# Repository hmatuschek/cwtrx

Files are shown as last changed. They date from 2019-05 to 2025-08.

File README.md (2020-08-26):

# Multiband QRP CW TRX based on the QCX

This repository contains all CAD files for the PCBs, documentation and 
firmware sourcecode for my small [portable multi-band QRP CW transceiver](https://dm3mat.darc.de/cw2019). 

## License
This work is licensed under a [Creative Commons Attribution-ShareAlike 4.0 International License](http://creativecommons.org/licenses/by-sa/4.0/).

[](http://creativecommons.org/licenses/by-sa/4.0/">)

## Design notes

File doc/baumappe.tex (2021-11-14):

\documentclass[10pt, a4paper,twoside]{scrartcl}
\usepackage[ngerman]{babel}
\usepackage{amsmath}
\usepackage{amssymb}
\usepackage{graphicx}
\usepackage{subcaption}
\usepackage{float}
\usepackage[top=2cm,bottom=3cm,outer=2cm,inner=3cm]{geometry}\usepackage[utf8]{inputenc}
\usepackage{hyperref}
\usepackage[multiple]{footmisc}
\usepackage{parskip}
\usepackage{wrapfig}
\usepackage{xfrac}
\usepackage{xcolor}
\usepackage{tikz}
\usetikzlibrary{arrows}
\usetikzlibrary{arrows.meta}
\usepackage{longtable}
\usepackage{pdfpages}
\usepackage[tikz]{bclogo}
\usepackage{eurosym}
\usepackage{listings}

\hypersetup{
    colorlinks=true,
    linkcolor=blue,
    filecolor=magenta,      
    urlcolor=cyan
}

\restylefloat{table}

\newcommand{\warn}[1]{\textbf{#1}}
\newcommand{\con}[1]{\texttt{#1}}
\newcommand{\dis}[1]{\textbf{\texttt{#1}}}

\newenvironment{remember}{\begin{bclogo}[couleur=blue!30,arrondi=.1,logo=\bccrayon,ombre=true]{Merke}}{\end{bclogo}}   
\newenvironment{remark}{\begin{bclogo}[couleur=blue!30,arrondi=.1,logo=\bcinfo,ombre=true]{Hinweis}}{\end{bclogo}}   
\newenvironment{warning}{\begin{bclogo}[couleur=red!30,arrondi=.1,logo=\bcattention,ombre=true]{Warnung}}{\end{bclogo}}   

\title{QRP CW Transceiver Baumappe}
\subtitle{Board Rev. 2, Firmware Rev. 2.0}
\author{Hannes Matuschek -- DM3MAT\\\texttt{<dm3mat [at] darc [dot] de>}\\\texttt{https://dm3mat.darc.de/cw2019}}
\date{\today}

\begin{document}
\maketitle

\begin{abstract}
Diese Baumappe beschreibt den Zusammenbau, Abgleich und die Bedienung der zweiten Revision meines kleinen, portablen CW TRX. Wenn Sie keinen \emph{rev 2} Aufdruck auf den Leiterplatten finden können, ist dies das falsche Dokument!

Der Hauptunterschied zwischen dieser und der ersten Revision ist der Mischer. Anstatt des \texttt{74HC4053}, der eine recht große Dämpfung bei höheren Frequenzen aufweist, verwendet die zweite Revision den \texttt{FST3253}. Dieser Mischer kann problemlos bis ins 10m Band verwendet werden. Außerdem wurde das Platinenlayout vereinfacht. Die Platinen werden nun durch Platinensteckverbinder verbunden, was den Aufbau des TRX deutlich vereinfacht. Auch wanderte der Mikrocontroller auf die Empfängerplatine. Es gibt nun nur noch zwei Platinen mit $10\times 8\,cm$ Abmaßen und nicht mehr drei. Diese passen gerade so in ein Fischer-Gehäuse (\texttt{KOH-2100} + \texttt{KOH-4100} + \texttt{DPL 2-4}).
\end{abstract}
\thispagestyle{empty}
\vfill
\begin{center}
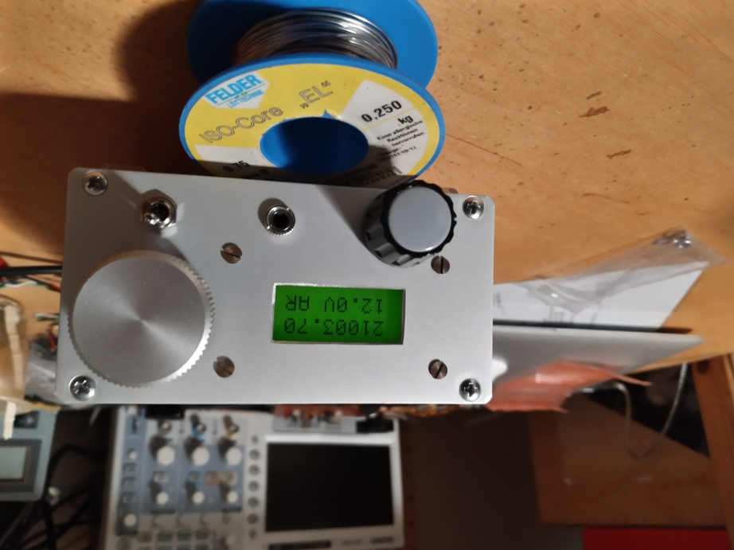
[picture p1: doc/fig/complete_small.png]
 
\end{center}

\cleardoublepage
\tableofcontents
\thispagestyle{empty}

\cleardoublepage
\section{Empfänger- \& Controllerplatine} \label{sec:rx}
 Auf dieser Platine befindet sich der Hauptteil der gesamten TRX-Schaltung. Der Empfänger ist ein Direktüberlagerungsempfänger (Driektmischer), der einen \texttt{FST3253} CMOS-Schalter als so genannter \emph{sample-hold} Mischer verwendet (zusammen mit \texttt{C4-C7}). Dieser Mischer benötigt zwei VFO Signale mit $90^\circ$ Phasendifferenz und produziert vier Mischprodukte mit $0^\circ$, $90^\circ$, $180^\circ$ und $270^\circ$ Phasenverschiebung. Diese zwei Signalpaare ($0^\circ$ + $180^\circ$) und ($90^\circ$ + $270^\circ$) werden dann in zwei unabhängige Differenzverstärker (\texttt{U6A}, \texttt{U6B}) geführt, die zwei um $90^\circ$ phasenverschobene Audiosignale produzieren (für USB, $-90^\circ$ für LSB). Das nachfolgende Phasennetzwert \texttt{U7} \& \texttt{U8} verschiebt dann die Phasenlage der Audiosignale um $-90^\circ$ bei $700\,Hz$. Zuletzt werden die resultierenden Signale mit \texttt{RV3} addiert. Dabei interferieren USB-Signale konstruktiv und LSB-Signal heben sich auf. Diese \emph{Phasenmethode} erlaubt Direktüberlagerungsempfängern eine Unterdrückung eines Seitenbanden. Die weiteren Audiostufen (\texttt{U3} \& \texttt{U5}) filtern und verstärken Audiosignale nahe $700\,Hz$, welche schließlich in die Audio-PA \texttt{U4} geführt werden.
 
 Der Controller- und VFO-Abschnitt der Platine besteht aus einem \texttt{ATMega 328P} Mikrocontroller, der die \texttt{SI5351} PLL steuert. Das \texttt{CLK2} Signal der PLL treibt zwei Flip-Flops \texttt{U9}, welche die Frequenz des \texttt{CLK2} Signals durch vier teilen und dabei zwei um $90^\circ$ phasenverschobene VFO-Signale für den Mischer erzeugen.
  
\subsection{Aufbau des Controllers}
 In einem ersten Schritt wird der Controllerteil der Platine aufgebaut. Löten Sie \texttt{C2}, \texttt{C26}, \texttt{J7} Steckverbinder, \texttt{L3}, \texttt{C38}, \texttt{C40}, \texttt{C41}, \texttt{C42}, \texttt{U10}, \texttt{J10}, \texttt{C14}, \texttt{J3}, \texttt{R3}, \texttt{C46}, \texttt{R4}, \texttt{U11} + Socket, \texttt{LCD1} Steckverbinder, \texttt{R43}, \texttt{R5}, \texttt{RV4}, \texttt{J9} Steckverbinder, \texttt{R41}, \texttt{R40}, \texttt{C39} \& \texttt{U9} ein. 

\begin{remark}
 Durch das kompakte Design sind die Bauteilreferenzen leider teilweise schlecht zu lesen. I habe dafür, mit Hilfe eines sehr netten KiCAD Plugins, eine \href{https://dm3mat.darc.de/cw2019/rx_rev2_ibom.html}{interaktive BOM} für diese Platine exportiert. Damit sollte es recht einfach sein, bestimmte Bauteile auf der Platine zu finden.
\end{remark}

\begin{warning}
Das Metallfähnchen des TO-220 Gehäuses von \texttt{U10} ist üblicherweise direkt mit dem Mittelpin (GND) verbunden. Bitte prüfen Sie das vor dem Einbau. Einige sehr seltene Varianten verbinden dieses Fähnchen mit $+5\,V$, was einen soliden Kurzschluss verursacht.
\end{warning}

Wenn Sie einen der seltenen Varianten von \emph{U10} verwenden, fügen Sie bitte ein Glimmerplätchen zwischen dem TO-220 und der Leiterplatte ein um einen Kurzschluss zu verhindern. Falls nicht, kann darauf verzichtet werden und U10 direkt auf die Platine verschraubt werden.

 \texttt{R43} limitiert den Strom zur LCD-Hintergrundbeleuchtung. Standardmäßig wird hier ein $220\,\Omega$ Widerstand verwendet. Dieser limitiert den Strom auf ungefähr $23\,mA$. Die führt zu eine sehr schwachen Hintergrundbeleuchtung verringert aber den Stromverbrauch von den max. $120\,mA$ (\texttt{R43} kurzgeschlossen). Ich finde persönlich eine schwache Hintergrundbeleuchtung ideal: Während der Nacht reicht auch eine geringe Hintergrundbeleuchtung aus um das Display lesen zu können. Am Tage ist diese Beleuchtung völlig unnötig. Eine sehr helle Hintergrundbeleuchtung ist daher nicht notwendig und würde nur unnötig viel Batteriestrom verbrauchen. Wenn Sie diesen TRX ausschließlich zu Hause verwenden, können Sie \texttt{R43} überbrücken um somit die maximale Helligkeit zu erhalten.
 
\begin{remark} 
 Sie können auch den Widerstand \texttt{R43} mit einem Taster am Frontpanel ersetzen um die Hintergrundbeleuchtung bei bedarf einzuschalten.
\end{remark}

 Als nächsten bauen Sie den Stecker für den Schalter zusammen (oben-rechts auf der Platine mit der Beschriftung \texttt{SW}). Verbinden Sie eine $12\,V$ Spannungsquelle (Strombegrenzt auf nicht mehr als $100\,mA$) mit den Pads oben-rechts auf der Leiterplatte mit der Beschriftung \texttt{+ G}, wobei \texttt{+} $+12\,V$ und \texttt{G} Masse bedeutet.

\begin{remember}
 Die Empfängerplatine selbst besitzt keine Absicherung gegen Verpolung. Seien Sie also vorsichtig, wenn Sie den RX an die Spannungsquelle anschließen.
\end{remember}

 Wenn nichts in Rauch aufgeht, schalten Sie den RX aus und bauen sie die Stecker für den Drehimpulsgeber und das LCD auf.  

 Der Stecker für den Drehimpulsgeber hat die folgenden Anschlüsse (von links nach rechts) \emph{Mitteltaster}, \emph{Encoder B}, \emph{Encoder A} und \emph{Masse}.

 Der LCD-Stecker hat die folgenden Anschlüsse (von links nach rechts): \emph{5V} Pin 2 am LCD, \emph{Kontrast} Pin 3 am LCD, \emph{LED Hintergrundbeleuchtung} Pin 15 am LCD, \emph{GND} Pin 1 am LCD, \emph{RS (register selection)} Pin 4 am LCD, \emph{D4-D7} Pins 11-14 am LCD, \emph{Chip-Enable (EN)} Pin 6 am LCD. Sie müssen auch Pins 5 und 16 direkt am LCD mit Masse (Pin 1, GND) verbinden.
 
 Verbinden Sie nun den Drehimpulsgeber und das LCD mit der Platine und installieren Sie den \texttt{ATMega328} Mikrocontroller. Dann verbinden Sie den RX wieder mit der Spannungsversorgung. Wenn Sie einen vorprogrammierten MCU erhalten haben, sollten Sie nun eine kurze Begrüßung auf dem Display lesen können. Wenn Sie gar nichts oder eine Reihe schwarzer Blöcke auf dem Display sehen, sollten sie zunächst den Kontrast mit \texttt{RV4} einstellen. Wenn Sie weiterhin nichts auf dem Display sehen, überprüfen Sie bitte die Verbindungen zwischen der Platine und dem Display.

\subsection{Die PLL Testen}
 Als nächstes wird die Funktion der \texttt{SI5351} PLL überprüft. Dazu stecken Sie das \texttt{SI5351} breakout-board in den Sockel J9.

\begin{warning}
 Bitte achten Sie darauf, das \texttt{SI5351} beakout-board richtig herum einzusetzen. Es gibt keinen Schutz. Das breakout-board sollte mit dem LCD Steckverbinder überlappen nicht aber \texttt{U9}!
\end{warning}
 
 Schalten Sie nun den RX ein und überprüfen Sie ob ei $3.5\,MHz$ Signal an den Pins 8, 9, 11 und 12 von \texttt{U9} anliegt. Wenn nicht, überprüfen Sie ob ein $14.0\,MHz$ Signal am \texttt{CLK2} Ausgang des \texttt{SI5351} beakout-board anliegt. An dieser Stelle können Sie auch die $90^\circ$ Phasenverschiebung zwischen den Pins 8 und 12 von \texttt{U9} überprüfen.

\begin{remark}
Standardmäßig ist der RX für den Empfang des oben Seitenbandes (USB) ausgelegt. Wenn Sie den LSB Empfang bevorzugen, unterbrechen Sie die Verbindung des Jumpers \texttt{USB} und überbrücken Sie den Jumper \texttt{LSB} neben \texttt{U9}.
\end{remark} 

Wenn alles zu Ihrer Zufriedenheit funktioniert, fahren Sie mit dem Zusammenbau des restlichen Empfängers fort.

\subsection{Aufbau des Empfängers}
Bevor Sie mit dem Zusammenbau des Empfängers fortfahren, entfernen Sie alle Verbindungen zur Platine. Das heißt, entfernen Sie den \texttt{SI5351}, das LCD und den Impulsgeber sowie die Verkabelung zur Spannungsversorgung.

Als erstes sollte der SMD SOIC-16 \texttt{FST3253} Mischer eingelötet werden. 

\begin{warning}
 Seien Sie vorsichtig! Der \texttt{SI5351} sowie der \texttt{FST3253} sind \textbf{sehr} empfindlich gegenüber elektrostatischer Entladung. Tragen Sie ein anti-static Armband und verwenden Sie eine anti-statische Matte. Tragen Sie keine Kleidung aus Wolle oder synthetischen Fasern. Ich habe schon zwei \texttt{FST3253} auf diese Weise zerstört. 
\end{warning}

\paragraph{Falls Sie noch nie SMD Komponenten verbaut haben}
 Es ist überraschend einfach. Verwenden Sie eine kleine Spitze für Ihren Lötkolben, dünnes Lötzinn (z.B., $0.75mm$) und reichlich Flussmittel! Geben Sie eine gute Portion Flussmittel auf die Pads und Verzinnen Sie ein Pad (z.B., Pin 1). Dann nehmen Sie den IC mit einer spitzen Pinzette auf und fixieren Sie ihn ausschließlich an Pin 1 indem Sie das Pad erhitzen und den IC auf die Platine drücken. Überprüfen Sie nun die Ausrichtung des IC mit seinen Pads. Ist alles zu ihrer Zufriedenheit, können Sie die verbleibenden Pins verlöten. Verwenden Sie wenig Lötzinn und lassen Sie das Flussmittel die ganze Arbeit machen! Falls Sie eine Lötbrücke zwischen zwei Pins erhalten, entfernen Sie das überschüssige Lötzinn mit etwas Entlötlitze.

Sobald der Mischer installiert ist, ist die Reihenfolge, in der die  weiteren Bauelemente installiert werden unkritisch. Bauen Sie den restlichen RX auf, lassen Sie aber noch die Platinensteckverbinder sowie die RCA-Buchse (\texttt{TX-OC}) weg. Diese werden erst am Ende montiert.

\begin{remark}
Die Audio-PA (\texttt{LM386}, \texttt{U4}) hat sehr viel Verstärkung. Wenn Sie lediglich Kopfhörer verwenden wollen, können Sie \texttt{R13} und \texttt{C16} weglassen. Sie könne sie später noch hinzufügen.
\end{remark}

Um den Eingangstransformator zu wickeln, schneiden sie drei 15-16 cm lange CuL-Drahtstücke zurecht. Starten Sie die Windungen indem Sie die drei Drähte \textbf{von Hinten} durch den Kern stecken. Halten Sie diese nun fest und machen Sie die nächste Windung indem Sie die Drähte gegen den Uhrzeigersinn \textbf{von vorn} durch den Kern stecken. Fahren Sie nun fort bis sie 8 Findungen gegen den Uhrzeigersinn auf den Kern gebracht haben. Jedes mal, wenn die Drähte durch den Kern gesteckt werden, gilt als eine Windung.

\begin{figure}[ht!]
 \begin{subfigure}[t]{0.49\textwidth}
   \centering
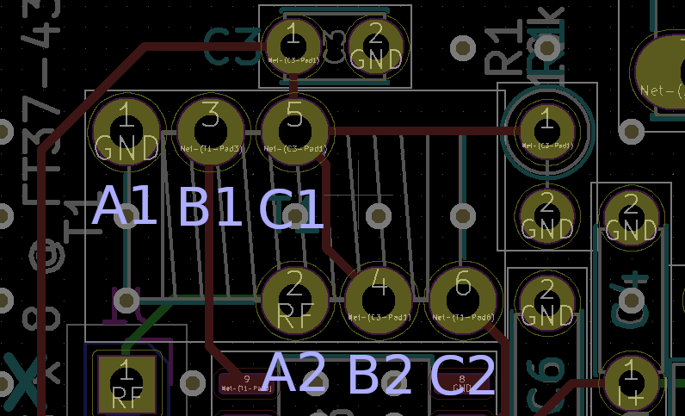
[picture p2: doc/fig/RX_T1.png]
   
   \caption{Footprint von T1}
 \end{subfigure}
 \begin{subfigure}[t]{0.49\textwidth}
   \centering
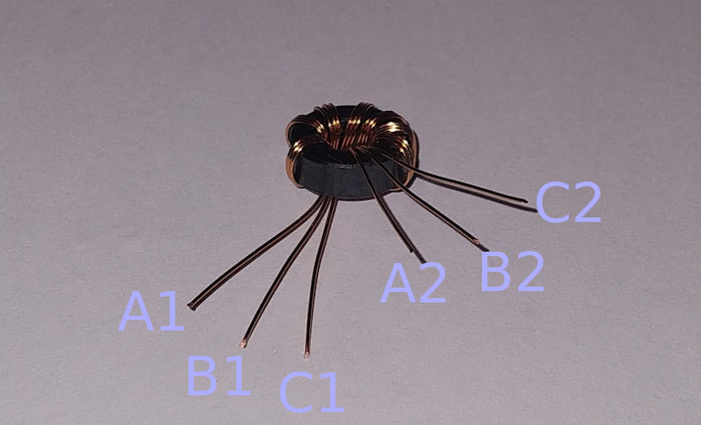
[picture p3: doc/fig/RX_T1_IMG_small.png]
   
   \caption{Gewickelter T1 mit Beschriftung.}
 \end{subfigure}
 \caption{Bevor Sie den Transformator einlöten, überprüfen Sie bitte korrekte Ausrichtung der Anschlüsse. Das Bedeutet das oben-linke wird mit dem unten-linken (d.h., A1 mit A2), oben-mitte mit dem unten-mitte (d.h., B1 mit B2) und das oben-rechte mit dem unten-rechten Pad (d.h., C1 mit C2) verbunden ist.}
\end{figure}

\begin{warning}
Die Audioendstufe neigt leider zum Schwingen, vor allem wenn ein kleiner Lautsprecher verwendet wird. Wenn das passiert, wird der gesamte Audiopfad in die Sättigung getrieben. Dabei kann bis zu 12V an den Mixer geführt werden, was diesen dann zerstört! Um das zu verhindern, \textbf{sollten} vier 5.1V Zenerdioden parallel zu den Kondensatoren C4-C7 fliegend gelötet werden. 
\end{warning}

\subsection{Empfängertest und Abstimmung}
Sobald der Empfänger vollständig aufgebaut ist, verbinden Sie die Spannungsversorgung und bereiten Sie die Stecker für die Lautstärke und den Kopfhörerausgang vor. Verbinden Sie nun auch ein Stück Koaxialkabel mit den \texttt{RX}/\texttt{GN} Pads links-oben auf der Platine. Dies ist der Antenneneingang für den Test. Je nachdem welches Band Sie gewählt haben, sollten Sie die Strombegrenzung der Spannungsversorgung nun auf $120\,mA$ erhöhen.

\subsubsection{Frequenzabstimmung}
Wenn ein genauer Frequenzzähler vorhanden ist, können Sie mit der Feinabstimmung der PLL Frequenz anfangen. Wählen Sie dazu im Menu das 20m Band aus und stellen Sie eine Frequenz von $14.000.70 MHz$ ein. Messen Sie nun die Frequenz am USB Pad. Sie Sollte nun genau $14.0\,MHz$ betragen (falls die Seitentonfrequenz auf $700\,Hz$) eingestellt ist. Sollte die Frequenz abweichen, wählen Sie im \emph{Setup}-Menü den Punkt \emph{PLL correction}. Sie können nun die PLL-Korrektur einstellen bis Sie die gewünschte Frequenz messen.

\subsubsection{CW Filter Abgleich}
Ach wenn die Mittenfrequenz des CW Audiofilter von $\approx 700\,Hz$ nicht geändert werden kann, werden Variationen in den Bauelementwerten zu eine kleinen Verschiebung der Mittenfrequenz des schmalen Filters führen. Für einen guten Abgleich der Send- und Empfangsfrequenzen sollte der CW Seitenton auf genau der Mittenfrequenz des CW Filters liegen. Daher sollte das Spektrum des CW Filters gemessen werden. Zum Beispiel mit der PC Soundkarte und einer Anwendung, die dieses Spektrum darstellt. Die so ermittelte Mittenfrequenz des CW Filters sollte dann unter \texttt{Menu}\ $\rightarrow$\ \texttt{Setup}\ $\rightarrow$\ \texttt{CW Tone} eingestellt werden.

\begin{remember}
Die im Display dargestellte Frequenz ist die Frequenz auf dem der TRX sendet. Nicht die VFO-Frequenz während des Empfangs.
\end{remember}

\subsubsection{Seitenbandunterdrückung}
Wenn Sie über einen Signalgenerator verfügen, stellen Sie ihn auf $14.000 MHz$ ein. Verbinden Sie den Signalgenerator über ein geeignetes Dämpfungsglied mit dem RX. Wählen Sie dann das 20m Band aus und stimmen Sie auf $14.001.3\,MHz$ ab. Sie werden nun einen sehr niedrigen Ton (c.a. $500\,Hz$) hören. Stimmen Sie nun \texttt{RV2} \& \texttt{RV3} ab um die Lautstärke dieses Tons zu minimieren. Dann stimmen Sie den RX auf $14.001.6\,HMz$ ab. Sie sollte nun eine hohen Ton ($900\,Hz$) hören. Stimmen Sie nun \texttt{RV1} \& \texttt{RV3} ab um die Lautstärke dieses Tons zu minimieren. Es könnte notwendig sein, diese Vorgang abwechselnd zu wiederholen bis ein optimales Ergebnis erreicht wird.

Mit diesem Abgleich ist der Abgleich des RX nun vollständig. 

\clearpage
\subsection{RX Bauelemente}  \label{sec:rxcomp}
\begin{longtable}{|l|p{6cm}|l|l|} \hline 
\# & Component & Value & Remarks \\ \hline 
1 & R15 & 10R & \\
4 & R20, R21, R22, R23 & 100R & \\
1 & R43 & 220R & \\
3 & R38, R39, R42 & 1k & \\
1 & R13 & 2.2k & \\
9 & R7, R27, R29-R31, R33, R35-R37 & 3.3k & \\
1 & R32 & 4.3k & \\
1 & R4 & 4.7k & \\
1 & R26 & 5.1k & \\
1 & R34 & 7.5k & \\
10 & R1, R2, R6, R11, R18, R24, R25, R28, R40, R41 & 10k & \\
2 & R9, R10 & 30k & \\
2 & R12, R14 & 33k & \\
2 & R16, R17 & 36k & \\
2 & R3, R5 & 47k & \\
1 & R8 & 120k & \\
1 & R19 & 470k & \\
2 & RV1, RV2 & 50k & \\
1 & RV3 & 500R & \\
1 & RV4 & 10k & \\
3 & C13, C20, C23 & 1n & \\
2 & C25, C27 & 3.3n & \\
3 & C30, C31, C35 & 10n & \\
5 & C12, C17, C18, C21, C33 & 47n & \\
23 & C3, C8, C11, C22, C24, C26, C29, C32, C34, C37-C41, C46-C54 & 100n & \\
5 & C4, C5, C6, C7, C36 & 470n & \\
2 & C1, C28 & 1u & \\
3 & C15, C16, C42 & 10u & \\
3 & C2, C14, C19 & 100u & \\
8 & L1, L3, L4, L5, L6, L7, L8, L9 & 100u & \\
1 & T1 & 3 x 8 @ FT37-43 & \\
1 & D1 & 1N4148 & \\
4 & parallel zu C4-C7 & 5.1V Zener & \\
1 & Q1 & BS170 & \\
1 & Q2 & 2N3904 & \\
1 & U1 & FST3253 & \\
5 & U3, U5, U6, U7, U8 & LM833 & \\
1 & U4 & LM386 & \\ 
6 & -- & DIP-8 Sockets & \\
1 & U9 & 74AC74 & \\
1 & U10 & L7805 & \\
1 & U11 & ATmega328-PU & \\
1 & --  & DIP-28 Socket & \\
1 & - & SI5351 break-out & \\
2 & J1, J3, J4, J11 & 1x10 pin-header long & \\
1 & J6 & 2x3 pin-header & \\
1 & J9 & 1x7 pin-socket & \\
2 & J2, J7 & 1x2 90deg & \\
1 & -- & Switch & \\
1 & J8 & 1x3 90deg & \\
1 & -- & 10k log & potentiometer \\
1 & J10 & 1x4 90deg & \\
1 & -- & Rotary encoder & \\
1 & LCD1 & 1x10 90deg & \\
1 & -- & LCD & 2 x 8 symbols \\
1 & J13 & TX-OC & RCA-jack (optional) \\
1 & J5 & Key & 3.5mm stereo jack\\ \hline
\end{longtable}

\cleardoublepage
\section{PA \& Tiefpassfilter-Platine} \label{sec:pa}
Den Hauptteil der PA/LP-Platine wird von den vier 7-Pol Chebyschev Tiefpassfilter eingenommen. Diese Chebyschevfilter werden benötigt um mit lediglich vier Tiefpassfiltern alle HF-Bänder von 80m bis 10m abzudecken. Der Filter ganz rechts deckt die 80m und 60m Bänder ab und sollte eine Grenzfrequenz von $5.6\,MHz$ haben. Der nächste Filter deckt das 40m und 30m Band ab und sollte eine Grenzfrequenz von $10.5\,MHz$. Der vorletzte Filter deckt das 20m und 17m Band ab und sollte eine Grenzfrequenz von $20\,MHz$ haben. Letztendlich der Filter ganz links deckt das 15m, 12m und 10m Band ab und sollte eine Grenzfrequenz von $30\,Mhz$. Die einzelnen Tiefpassfilter werden mit 4 Subminiaturrelais umgeschaltet die von der RX Platine durch \texttt{J2} gesteuert werden.

Der MOSFET \texttt{Q4} fungiert als RX/TX-Schalter, der das Tiefpass-gefilterte Signal vom Eingang zum RX über \texttt{J6} führt. Der PA-Abschnitt besteht aus einem \texttt{74HCT00} als Treiber und vier \texttt{BS170} MOSFETs als PA Transistoren. Das TX-Oszillator-Signal kommt von der RX/Controller-Platine via \texttt{J7}. Die Stromversorgung des gesamten TRX geschieht durch die Buchse \texttt{J3} und die Stromversorgung des RX erfolgt durch \texttt{J11}.

\begin{remark}
 Bevor Sie die Tiefpassfilter auf die Platine löten, bauen Sie diese zuerst auf einem Stück Leiterplattenmaterial auf und messen Sie diesen durch. Chebyschev Tiefpassfilter sind etwas empfindlich bezüglich der Komponentenwerte.
\end{remark}

 Wenn keine Messgeräte vorhanden sind, ziehen Sie bitte jeweils eine Windung von den gegebenen Werten ab. Die Anzahl der Windungen wurden aus den Al-Werten des Herstellers bestimmte. Meiner Erfahrung nach führt dies zu leicht zu großen Induktivitäten. Außerdem gehen Sie sicher lieber das Risiko einer zu hohen als einer zu niedrigen Grenzfrequenz der Tiefpassfilter ein. 
 
\begin{remark}
 Wie für die Empfängerplatine, gibt es auch für die PA-Platine eine \href{https://dm3mat.darc.de/cw2019/pa_rev2_ibom.html}{interaktive BOM}.
\end{remark}

 Die Diode \texttt{D4} ist parallel in Sperrrichtung zur Spannungsversorgungsbuchse geschaltet. Zusammen mit einer Sicherung im Kabel dient diese Diode dem Verpolschutz. Wenn die Spannungsversorgung falsch herum angeschlossen wird, schließt diese Diode die Spannungsversorgung kurz, was die Sicherung in der Versorgungsleitung durchbrennen lässt. Eine 2A Sicherung \emph{flink} sollte es schon sein. 

 Zuletzt löten Sie die Platinensteckverbindersockel \texttt{J2}, \texttt{J6}, \texttt{J7} ein \texttt{J11}.
´ 
\clearpage
\subsection{PA/Tiefpass Bauelemente}  \label{sec:pacomp}
\begin{longtable}{|l|p{6cm}|l|l|} \hline 
\# & Component & Value & Remarks \\ \hline 
2 & R12, R13 & 100 & \\
1 & R9 & 470R & \\
1 & R10 & 1k & \\
1 & R14 & 4.7k & \\
7 & R1, R3, R5, R7, R11, R15, R16 & 10k & \\
4 & R2, R4, R6, R8 & 100k & \\
2 & C2, C15 & 100p & NP0 \\
4 & C3, C6, C11, C16 & 220p & NP0 \\
4 & C4, C7, C12, C17 & 470p & NP0 \\
2 & C5, C18 & 820p & NP0 \\
2 & C8, C13 & 1n & NP0 \\
2 & C9, C14 & 1.5n & NP0 \\
11 & C1, C10, C19, C20, C22, C23, C24, C27, C28, C29, C30 & 100n & \\
1 & C25 & 1u & \\
1 & C26 & 220u & \\
1 & L14 & 22u & 07HCP \\
1 & L13 & 100u & MICC \\
3 & L1, L5, L9 & 330n & 11T on T37-6 \\
3 & L2, L6, L10 & 480n & 13T on T37-6 \\
3 & L3, L7, L11 & 750n & 14T on T37-2 \\
3 & L4, L8, L12 & 1700n & 21T on T37-2 \\
1 & T1 & -- & 8T + 8T on FT37-43 \\
4 & K1, K2, K3, K4 & G6S-2 & \\
6 & D1, D2, D3, D5, D6, D7 & 1N4148 & \\
1 & D4 & 1N4001 & \\	
4 & Q1, Q2, Q3, Q10 & 2N3904 & \\
6 & Q4, Q6, Q7, Q8, Q9, Q11 & BS170 & \\
1 & Q5 & BD140-16 & \\
1 & U1 & 74HCT00 & \\
1 & J1 & BNC & \\
1 & J2 & 1 x 8 pin-socket & \\
1 & J3 & barrel-jack & \\
3 & J6, J7, J11 & 1 x 2 pin-socket & \\ \hline
\end{longtable}

\cleardoublepage
\section{Endmontage} \label{sec:box}
Schließlich folgt die Endmontage. In diesem schritt werden die Platinensteckverbinder montiert. Wie dies geschieht hängt ein wenig von dem Verwendeten Gehäuse ab. Die Beschreibung die ich hier gebe, betrifft den Fischer-Gehäusebausatz \texttt{KOH-2100} + \texttt{KOH-4100} + \texttt{DPL 2-4}. Dieses ist ein kompaktes $10 \times 10 \times 5\,cm$ Gehäuse. Die Platinen werden mit c.a. $\approx 1.5\,cm$ Abstand in die untere Halbschale geschoben. Leider habe ich keine passenden Stapelleisten für diesen Abstand gefunden und verwende daher welche mit $38\,mm$ Gesamtlänge und daher die viel zu lang sind.

\begin{figure}[!ht]
 \centering
 \begin{subfigure}{0.49\linewidth}
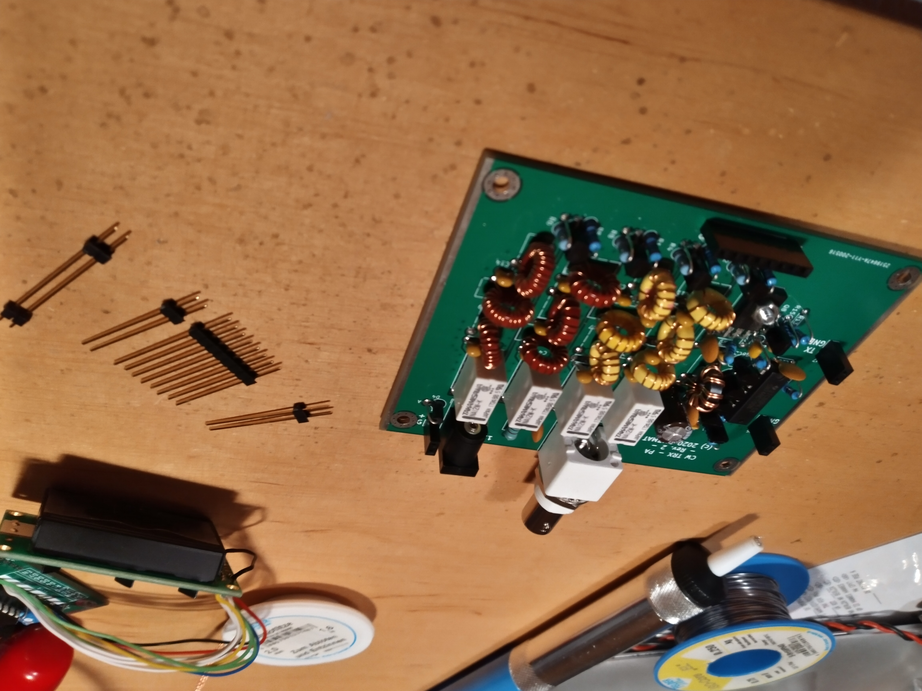
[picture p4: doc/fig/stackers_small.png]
  
  \caption{Schneiden Sie das obere Ende der Stapelleisten ab, bevor Sie sie in die Sockel auf der PA Platine stecken.}  \label{fig:stackers}
 \end{subfigure}
 \begin{subfigure}{0.49\linewidth}
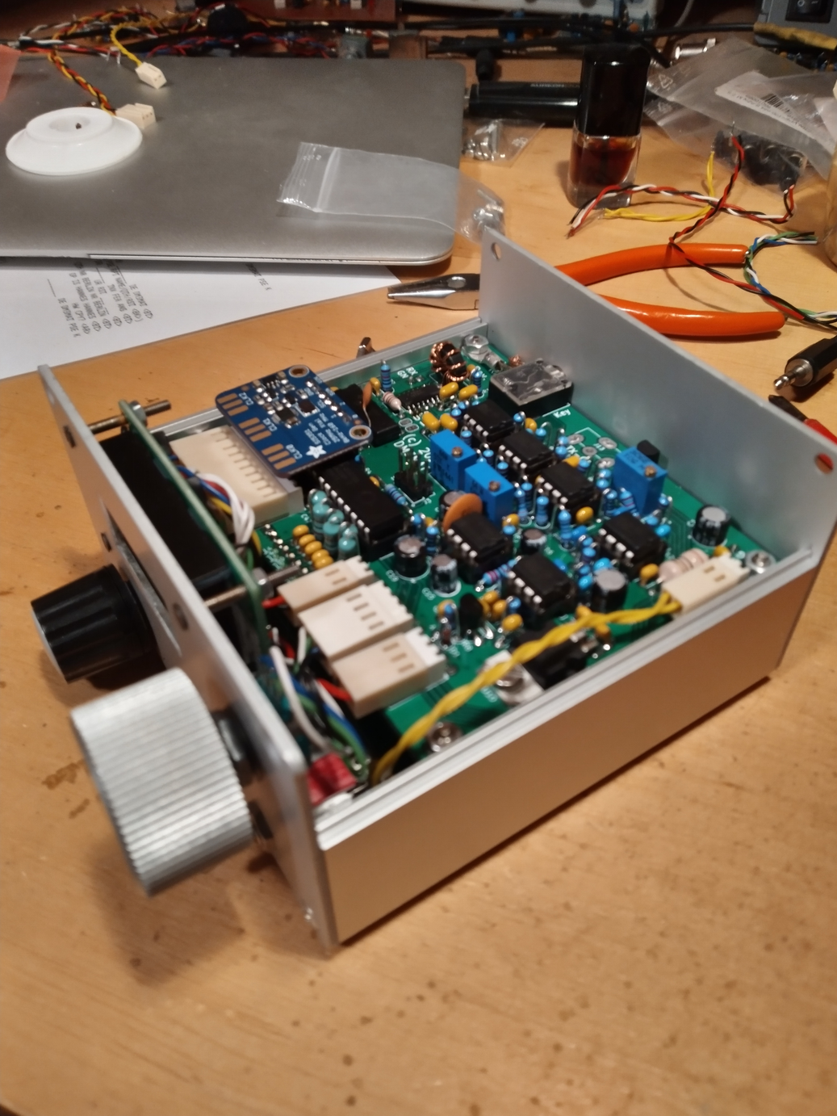
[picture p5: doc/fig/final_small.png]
  
  \caption{Stecken Sie die RX Platine auf die Stapelleisten, schieben Sie das Gebilde in die Gehäuseschale, löten Sie die Stapelleisten an der Empfängerplatine fest und schneiden Sie schließlich die Stapelleisten zu.}  \label{fig:final}
 \end{subfigure}
 \caption{Endmontage der Platinen.}
\end{figure}

Der einfachste Weg ist es die oberen Enden der Stapelleisten abzuschneiden (siehe Abbildung \ref{fig:stackers}) und diese dann in die entsprechenden Sockel der PA Platine zu stecken. Führen Sie dann die langen Enden durch die entsprechenden Löcher der RX Platine und schieben Sie beide in das Gehäuse. Löten Sie nun die Stapelleisten auf der RX Platine fest und kürzen Sie die überstehenden Enden.

Wenn Sie das oben erwähnte Fischergehäuse verwenden, wird die RCA Buchse zur Steuerung einer externen PA nicht mehr passen. Die RX und PA Platinen sind einfach zu dicht beieinander. Wenn Sie ein größeres Gehäuse verwenden, können Sie nun die RCA Buchse installieren.

\subsection{Finaler Test}
Mit der abgeschlossenen Endmontage ist es nun an der Zeit die PA und die Sende-Empfangsumschaltung zu testen. Verbinden Sie alles miteinander und schließen Sie ein Dummyload and den Ausgang an. Messen Sie die HF Spannung über dem Dummyload oder schleifen Sie ein HF-Leistungsmeter zwischen TRX und Dummyload ein. Sie sollte etwa $22\,Vp$ oder ca. $5\,W$ am Ausgang messen. Die Leistung hängt auch von der Betriebsspannung ab. Hier werden $13.8\,V$ angenommen.

Wenn Sie deutlich weniger Messen, messen Sie bitte die Spitzenspannungen am PA-Ausgang und Tiefpassfiltereingang. Überprüfen Sie bitte auch nochmals die Tiefpassfilter. Wenn alles zu Ihrer Zufriedenheit ist, ist der Aufbau abgeschlossen.

\subsection{Hot fixes}
Die zweite Revision war beinahe ein Redesign. Daher ist noch nicht alles Perfekt. Zum Beispiel produziert der \texttt{74AC74} recht hohe Hochfrequenzspannungen auf der $5\,V$ Spannungsversorgung. Um diese stärker zu dämpfen löten Sie bitte einen $470\,pF$ Kondensator direkt von Pin 16 (5V) zu Pin 8 (GND).

Die Audioendstufe neigt leider zum Schwingen, vor allem wenn ein kleiner Lautsprecher verwendet wird. Wenn das passiert, wird der gesamte Audiopfad in die Sättigung getrieben. Dabei kann bis zu 12V an den Mixer geführt werden, was diesen dann zerstört! Um das zu verhindern, \textbf{sollten} vier 5.1V Zenerdioden parallel zu den Kondensatoren C4-C7 auf dem RX-Board fliegend gelötet werden. 

\clearpage
\subsection{Mechanical Parts}
\begin{longtable}{|l|p{6cm}|l|l|} \hline 
\# & Component & Remarks \\ \hline 
1 & chassis top & \\
1 & chassis bottom & \\
1 & chassis front/back & \\
1 & 10k log pot & \\
1 & rotary encoder & \\
1 & LCD display & \\
1 & head-phone socket & \\
1 & switch & \\
1 & barrel plug & \\
2 & fuse holder & optional \\
2 & 2A flink & optional \\
1 & speaker & optional \\ \hline
\end{longtable}

\cleardoublepage 
\section{Die Firmware bauen und laden} \label{sec:fw}
Um die Firmware zu bauen und aufs Gerät zu laden oder auch um die Firmware zu aktualisieren, wird ein sogenannter \emph{in-system programmer} (ISP) benötigt. Dies sind kleine USB-Sticks die die Verbindung vom Computer zum Controller (MCU) herstellen. Es gibt eine Vielzahl an verschiedenen günstigen ISPs (üblicherweise zwischen 5\EUR und 10\EUR auf eBay). Es ist auch möglich einen ISP für die serielle Schnittstelle \href{http://www.lancos.com/siprogsch.html}{selbst zu bauen} oder auch einen \href{https://www.arduino.cc/en/Tutorial/BuiltInExamples/ArduinoISP}{Arduino als ISP} zu verwenden.

Wenn Sie nun einen ISP besitzen, benötigen Sie etwas Software um die Firmware auf die MCU zu schreiben. I verwende \href{https://www.nongnu.org/avrdude/}{avrdude} unter Linux dafür. Andere funktionieren auch. Sie können nun einfach die Firmware sowie das EEPROM Abbild \href{https://github.com/hmatuschek/cwtrx/releases}{herunter laden} und diese auf die MCU spielen. Zuvor müssen Sie aber die sog. \emph{fuses} (Sicherungen) setzen. Setzen Sie die \emph{low-fuses} auf \texttt{0xE2} und die \emph{high-fuses} auf \texttt{0xD9}. Dies konfiguriert the MCU den internen RC-Oszillator als Takt zu verwenden und diesen Takt nicht um den Faktor 8 zu teilen. Alle weiteren Einstellungen bleiben auf den Standardwerten.

\begin{wrapfigure}{l}{0.2\linewidth}
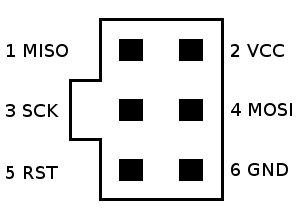
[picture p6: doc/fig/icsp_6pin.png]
  
\end{wrapfigure}
Um nun die Firmware zu laden, muss die MCU mit dem Computer verbunden werden. Dazu wird ein Standard 6-Pin ISP-Steckverbinder verwendet. Der Pin 1 ist durch einen kleinen Kreis auf dem Board markiert. Daraus ergibt sich, dass die kleine \emph{Nase} am Stecker vom Controller weg zeigen muss.

Wenn Sie den Controller programmieren, müssen Sie zunächst die \emph{fuses} setzen. Dieser Schritt muss nur einmal ausgeführt werden, da diese Einstellungen erhalten bleiben auch wenn die Firmware überschrieben wird. Im zweiten Schritt wird die eigentliche Firmware (\texttt{firmware-atmega328p.hex}) auf den Controller geschrieben. Dieser Schritt löscht normalerweise den internen EEPROM. Im EEPROM werden Ihre Einstellungen und die letzte eingestellte Frequenz gespeichert. Die Firmware kann ggf. nicht richtig funktionieren, wenn der EEPROM nicht korrekt initialisiert ist. Daher muss nach der Firmware das EEPROM Abbild (\texttt{firmware-atmega328p-eeprom.hex}) der \emph{Werkseinstellungen} aufgespielt werden.

\subsection{Die Firmware aus den Quellen bauen und laden}
In diesem Absatz will ich kurz das Bauen und Laden der Firmware aus den Quellen unter Ubuntu/Debian (und damit auf einem Raspberry Pi) beschreiben. Bevor Sie starten können, müssen Sie etwas Software nachinstallieren. Den Compiler, die Buildumgebung und die Programmiersoftware. Führen Sie also auf der Kommandozeile aus: 
\begin{lstlisting}[language=bash]
sudo apt-get install git cmake gcc-avr avrdude
\end{lstlisting}

\texttt{git} ist das Versionskontrollsystem. Es wird verwendet um den aktuellen Quellcode herunter zu laden. \texttt{cmake} ist die Buildumgebung. Es gibt eine nette Erweiterung für cmake, die es ermöglicht die Firmware einfach zu bauen und auf die MCU zu laden. \texttt{gcc-avr} ist der Compiler für die AVR MCUs. \texttt{avrdude} ist das Programmiersoftware um die Firmware letztlich auf die MCU zu schreiben.

Sobald Sie die Software installiert haben, können Sie die Quellen von meiner github Seite laden mit
\begin{lstlisting}[language=bash]
git clone https://github.com/hmatuschek/cwtrx.git
\end{lstlisting}

Sie werden nun ein neues Verzeichnis mit dem Namen \texttt{cwtrx} finden. Bevor Sie die Firmware auf die MCU schreiben können, müssen Sie ggf. einige Einstellungen vornehmen. In den ersten Zeilen der Datei \texttt{cwtrx/\-firmware/\-CMakeLists.txt} wird der ISP festgelegt, den Sie verwenden wollen und wie die Software diesen finden kann.

Standardmäßig sollte dort so etwas stehen:
\lstinputlisting[linerange={1-4}, numbers=left]{../firmware/CMakeLists.txt}
In der zweiten Zeile wird die Programmiersoftware festgelegt. Ich verwende hier avrdude. Die dritte Zeile legt den ISP fest. Ich verwende einen STK500V2 kompatiblen ISP (eigentlich heißt der DIAMEX-AVR). Letztendlich wird in Zeile 4 die Gerätedatei festgelegt, unter der der ISP gefunden werden kann. Dieser ISP stellt eine serielle Schnittstelle dar. Daher ist er bei mir unter der Datei \texttt{/dev/ttyACM0} zu finden. Gegebenenfalls müssen Sie die Zeilen 3 und 4 an Ihren ISP anpassen.

Wenn alles aufgesetzt ist, können sie die Firmware bauen. Betreten Sie das Verzeichnis \texttt{cwtrx}, erzeugen Sie ein sog. \emph{build}-Verzeichnis und betreten Sie dieses auch.
\begin{lstlisting}[language=bash]
cd cwtrx
mkdir build
cd build
\end{lstlisting}

Im nächsten Schritt wird der build konfiguriert:
\begin{lstlisting}[language=bash]
cmake ..
\end{lstlisting}
Dieser Schritt sucht nach dem Compiler und bereitet alles vor. Sobald dieser Schritt abgeschlossen ist kann die Firmware und das EEPROM Abbild erstellt werden.
\begin{lstlisting}[language=bash]
make
\end{lstlisting}

Danach müssen die \emph{fuses} gesetzt werden.
\begin{lstlisting}[language=bash]
make set_fuses
\end{lstlisting}
Dieser Schritt kann bei brandneuen MCUs auch fehlschlagen. Versuchen Sie es einfach nochmal. Sobald die \emph{fuses} gesetzt sind, sollte die Kommunikation mit der MCU stabil sein.

Laden Sie danach die Firmware auf die MCU mit
\begin{lstlisting}[language=bash]
make upload_firmware
\end{lstlisting}
und letztendlich das EEPROM Abbild mit
\begin{lstlisting}[language=bash]
make upload_eeprom
\end{lstlisting}

Ihr TRX ist nun betriebsbereit.

\subsection{Firmware aktualisieren}
Unter der Annahme, dass Sie die Schritte oben bereits ausgeführt haben, können Sie die Firmware recht einfach aktualisieren. Betreten Sie dazu das Verzeichnis \texttt{cwtrx} und führen sie die folgenden Schritte aus.
\begin{lstlisting}[language=bash]
git pull
cd build
make 
make upload_firmware
make upload_eeprom
\end{lstlisting}
Ihr TRX sollte nun über die aktuellste Firmware verfügen.

\cleardoublepage
\section{Bedienung} \label{sec:user}
Einen komplexen TRX mit einem Drehimpulsgeber zu bedienen ist recht schwierig. Ich habe daher ein zwei-ebenen Menu entworfen, dass alles Wichtige in die erste Ebene (blau in Abb. \ref{fig:menu}) und alles weniger Wichtige in die Zweite ebene (rot in Abb. \ref{fig:menu}) verbannt. Das erlaubt eine schnelle Handhabung für häufig verwendete Menüpunkte.

\begin{figure}[!ht]
 \centering
 \footnotesize
 \begin{tikzpicture}[node distance=2.3cm,
	>={Latex[width=2mm,length=2mm]},
    menu/.style = {rectangle, rounded corners, draw=black,
                   minimum width=1.5cm, minimum height=1cm,
                   text centered, font=\sffamily, fill=blue!30},
    submenu/.style = {menu, fill=red!30}]
  \node (rit) [menu] {RIT};   
  \node (speed) [menu, right of=rit] {CW Speed}; 
  \node (step) [menu, right of=speed]{Step size};
  \node (vfo) [menu, right of=step] {VFO};
  \node (band) [menu, right of=vfo] {Band};
  \node (setup) [menu, right of=band] {Setup};
  
  \node (quick) [submenu, below of=setup] {Qick-set};
  \node (cw) [submenu, left of=quick] {CW Mode}; 
  \node (tone) [submenu, left of=cw] {CW Tone}; 
  \node (level) [submenu, left of=tone] {CW Level}; 
  \node (text) [submenu, left of=level] {CW Text}; 
  \node (clr) [submenu, left of=text] {Clr. CWT};
  \node (meter) [submenu, below of=clr] {Meter};
  \node (hold) [submenu, below of=meter] {TX Hold}; 
  \node (greet) [submenu, right of=hold] {Greet};
  \node (enc) [submenu, right of=greet] {Enc.Type};
  \node (version) [submenu, right of=enc] {Version};
  \node (sideband) [submenu, right of=version] {USB/LSB};
  \node (pll) [submenu, right of=sideband] {PLL Cor.};
  \node (reset) [submenu, above of=pll] {Reset};

  \path[->,thick]
    (rit) edge (speed)
    (speed) edge (step)
	(step) edge (vfo)
	(vfo) edge (band)
	(band) edge (setup)
	(setup) edge[bend right] (rit);
	
  \path[->,thick,dashed]
    (setup) edge (quick);
  \path[->,thick]
        (quick) edge (cw)
    	(cw) edge (tone)
    	(tone) edge (level) 
    	(level) edge (text)
    	(text) edge (clr)
    	(clr) edge (meter) 
    	(meter) edge (hold)
    	(hold) edge (greet) 
    	(greet) edge (enc)
    	(enc) edge (version)
    	(version) edge (sideband)
    	(sideband) edge (pll)
    	(pll) edge (reset) 
    	(reset) edge (quick);
 \end{tikzpicture}
 \caption{Menu navigation} \label{fig:menu}
\end{figure}

Um in das Menu zu gelangen, drücken Sie einfach kurz auf den Achsentaster des Impulsgebers. Sie werden dann auf der RIT Einstellung oder der zuletzt verwendeten Einstellung landen. Drehen Sie nun den Impulsgeber um in der ersten Ebene des Menüs zu navigieren. Um eine Einstellung zu ändern, drücken Sie nochmals kurz auf den Achsentaster. Sie können nun die ausgewählte Einstellung ändern. Um die Änderung zu speichern und das Menü zu verlassen, drücken Sie nochmals kurz auf den Achsentaster.

Um die zweite Menüebene zu erreichen, drücken Sie zunächst kurz auf den Achsentaster um in die erste Ebene zu gelangen. Wählen Sie dann den Menüpunkt \texttt{Setup} aus und drücken Sie nochmals kurz den Achsentaster. Sie befinden sich nun in der zweiten Menüebene. Das Navigieren, Bearbeiten und Verlassen der zweiten Ebene erfolgt genauso wie in der ersten Menüebene.

\subsection{Gesten}
Die Firmware unterscheidet zwischen 4 verschiedenen \emph{Gesten} den Sie mit dem Drehimpulsgeber ausführen können:
\begin{enumerate}
 \item \emph{drehen} - Einfach den Impulsgeber drehen.
 \item \emph{klick} - Kurzes drücken und wieder loslassen des Achsentasters.
 \item \emph{gedrückt halten} - Langes (mind. $2\,s$) gedrückt halten des Achsentasters.
 \item \emph{drücken \& drehen} - Halten die den Achsentaster gedrückt und drehen Sie gleichzeitig den Impulsgeber.
\end{enumerate}

Während des Empfangs wird durch die \emph{drehen} Geste die Frequenz eingestellt (natürlich), eine \emph{klick} Geste wird das Menü öffnen, die \emph{gedrückt halten} Geste wird den gespeicherten Text senden (falls konfiguriert) und die \emph{drücken \& drehen} Geste wird die sogenannte \emph{quick-set} Einstellung ändern (falls konfiguriert).

\subsection{Einstellungen}
Als \emph{Einstellungen} wird alles Bezeichnet, was während des Betriebs geändert werden kann. Diese Einstellungen sind daher auch alle in der ersten Menüebene zu finden. 
 
\paragraph{Receive/Transmit offset (RIT)}
Erlaubt es die Empfangsfrequenz relativ zur Sendefrequenz zu verstimmen. Eine von null verschiedene RIT wird durch ein \texttt{+} oder \texttt{-} Symbol in der rechten unteren Ecke angezeigt.

\paragraph{CW speed}
Die Gebegeschwindigkeit in WPM.

\paragraph{Tuning step-size}
Die Abstimmschrittweite.

\paragraph{VFO}
Der aktuelle VFO. Entweder \texttt{VFO A}, \texttt{VFO B} oder \texttt{Split}.

\paragraph{Band}
Das aktuelle Band.

\subsection{Setup}
Im \emph{Setup} werden alle Einstellungen versteckt, die üblicherweise nicht während des Betriebs geändert werden. Sie sind daher in die zweite Menüebene verband.

\paragraph{Quick-set}
Das \emph{quick-set} Feature erlaubt es Ihnen eine bestimmte Einstellung (siehe oben) während des Empfangs zu ändern ohne dazu erst das Menü aufrufen zu müssen. Hier können Sie diese Einstellung auswählen: RIT, Gebegeschwindigkeit, Schrittweite, Band oder eben \texttt{none}. Letzteres deaktiviert \emph{quick-set}.

\paragraph{Keyer mode}
Stellt die Art der Taste ein. Entweder \emph{straight key} oder \emph{iambic}.

\paragraph{CW side-tone level}
Stellt die Lautstärke des CW Seitentons ein. Dies ist ein Wert zwischen 1 und 255.

\paragraph{Keyer memory \texttt{CW Text}}
Legt den Text fest, der gesendet wird, wenn der Achsentaster lange gedrückt wird. Wenn kein Text gespeichert ist wird nichts passieren.

Um den Text zu editieren drücken sie nun kurz den Achsentaster. Sie sollten nun einen Kursor unter dem ersten Zeichen des Textes sehen. Wenn Sie nun am Impulsgeber drehen, können Sie das Zeichen auswählen, das sie editieren wollen. Drücken sie nochmals kurz den Achsentaster um das ausgewählte Zeichen zu ändern. Das gewählte Zeichen sollte nun blinken. Wenn die das Zeichen geändert haben drücken Sie nochmals kurz auf den Achsentaster. Der Kursor sollte nun eine Stelle weiter gesprungen sein. Fahren Sie nun so fort bis der gewünschte Text erstellt ist (z.B. ein CQ Ruf). Um den Text zu speichern und das Menu zu verlassen, drücken und halten Sie den Achsentaster für mindestens 2 Sekunden.

\paragraph{Clear keyer memory}
Dieser Menüpunkt löscht den gespeicherten Text.

\paragraph{Meter selection}
Wählt die Anzeige während des Empfangs aus. Dies kann \texttt{Volt}, \texttt{Temp} oder \texttt{None} sein. Wenn Sie \texttt{Volt} wählen wird die Versorgungsspannung kontinuierlich gemessen und angezeigt. Wenn Sie \texttt{Temp} wählen wird die Kerntemperatur der MCU gemessen und angezeigt. Wenn Sie \texttt{None} gewählt haben, wird nichts angezeigt.

\paragraph{TX-hold time}
Legt die Länge der Umschaltpause im $ms$ fest. Standardmäßig ist sie auf $50\,ms$ festgelegt. Dieser kleine Wert erlaubt quasi-QSK. 
\begin{remark}
Wenn Sie eine externe PA verwenden oder im Split Modus operieren, sollten Sie eine längere Umschaltpause wählen um den Relais genügend Zeit um Umschalten zu gewähren.
\end{remark}

\paragraph{Greet text}
Dieser Editor erlaubt es den Begrüßungstext beim booten zu ändern. Dieser Editor funktioniert genau so wie der CW-Texteditor.

\paragraph{CW Seitenton}
Stellt die Frequenz des CW Seitentons ein. Diese Frequenz legt auch den Shift zwischen der Sende und Empfangsfrequenz fest und sollte daher der Mittenfrequenz des CW Audiofilters ($\approx 700\,Hz$) entsprechen.

\paragraph{Encoder type}
Legt den Typ des Drehimpulsgebers fest. Es gibt zwei verbreitete Typen \texttt{A} \& \texttt{B}. Wenn Sie genau den Encoder aus der BOM bestellt haben, haben Sie Typ A. Wenn Sie Probleme mit dem Encoder haben (Doppelschritte), sollten Sie hier Typ B einstellen.

\paragraph{PLL correction}
Diese Einstellung legt die PLL Frequenzkorrektur in PPM fest.

\paragraph{Factory reset}
Vorherige Versionen hatten einige Probleme mit korrumpierten EEPROM Speicher. Dieser Menüpunkt erlaubt es Ihnen den EEPROM auf den Auslieferungszustand zurückzusetzen.

\cleardoublepage
\section{Bill-of-Material (BOM)}
\input{bom.tex}

\subsection{Ein paar \euro\ sparen}
Der teuerste Einzelposten auf der BOM ist das Gehäuse. Sie können sicher ein Alugehäuse für unter \EUR{5} bei ebay finden. Sie finden auch billige Clone der SI5351 break-out Platine für um die \EUR{3}, billige Drehimpulsgeber und 2x8 LCD Displays dort. So können Sie die BOM Kosten noch deutlich senken.

\cleardoublepage
\includepdf[pages={1,2,4,3,5,6},landscape=true, addtotoc={
 1, section, 1, RX Schaltung, rxscm,
 2, subsection, 1, RX Mischer, rxmix,
 4, subsection, 1, Demodulator, rxdemod,
 3, subsection, 1, NF-Sektion, rxaudio,
 5, subsection, 1, PLL, rxpll,
 6, subsection, 1, Controller, rxctrl}]{fig/rx_scm.pdf}
\includepdf[pages={1,2,3},landscape=true, addtotoc={
 1, section, 1, RX Board, rxbrdtop,
 2, subsection, 1, Unterseite, rxbrdbottom,
 3, subsection, 1, Siebdruck, rxbrdsilk}]{fig/rx_brd.pdf}
\includepdf[landscape=true, addtotoc={
 1, subsection, 1, Bauteil Werte \& Lage, rxval}]{fig/rx_values.pdf}
\includepdf[landscape=true, addtotoc={
 1, section, 1, PA/LP Schaltung, pascm}]{fig/pa_scm.pdf}
\includepdf[pages={1,2,3},landscape=true, addtotoc={
 1, section, 1, PA/LP Board, pabrdtop,
 2, subsection, 1, Unterseite, pabrdbottom,
 3, subsection, 1, Siebdruck, pabrdsilk}]{fig/pa_brd.pdf}
\includepdf[landscape=true, addtotoc={
 1, subsection, 1, Bauteil Werte \& Lage, pacomp}]{fig/pa_values.pdf}
\includepdf[landscape=true, addtotoc={
 1, section, 1, Bohrplan, drillfront}]{fig/drill_front.pdf}
\includepdf[landscape=true]{fig/drill_back.pdf}
\end{document}

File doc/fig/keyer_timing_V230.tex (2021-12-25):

\documentclass{standalone}
\usepackage{pgfplots}
\usetikzlibrary{patterns}
\pgfplotsset{width=12cm, height=8cm, compat=1.9}
\pgfplotsset{compat=newest} 

\begin{document}
\begin{tikzpicture}
 \begin{axis}[
   axis lines = left,
   xlabel={$t$ in \emph{dits}},
   ytick={1.5,3.5,5.5,7.5},
   yticklabels={{iambic A}, {iambic B}, {left}, {right}}
  ]
  \fill[pattern=north west lines, opacity=0.2] (2.5,0) rectangle (5,9);
  \fill[pattern=north east lines, opacity=0.5] (4.5,0) rectangle (5,9);
  \fill[pattern=north west lines, opacity=0.2] (5.25,0) rectangle (7,9);
  \fill[pattern=north east lines, opacity=0.5] (6.5,0) rectangle (7,9);
  \fill[pattern=north west lines, opacity=0.2] (8.5,0) rectangle (11,9);
  \fill[pattern=north east lines, opacity=0.5] (10.5,0) rectangle (11,9);
  \fill[pattern=north west lines, opacity=0.2] (11.25,0) rectangle (13,9);
  \fill[pattern=north east lines, opacity=0.5] (12.5,0) rectangle (13,9);
  \addplot [mark=none, blue] coordinates {(0,1) (1,1) (1,2) (4,2) (4,1) (5,1) (5,2) (6,2) (6,1) (7,1) (7,2) (10,2) (10,1) (14,1)};
  \addplot [mark=none, red] coordinates {(0,3) (1,3) (1,4) (4,4) (4,3) (5,3) (5,4) (6,4) (6,3) (7,3) (7,4) (10,4) (10,3) (11,3) (11,4) (12,4) (12,3) (14,3)};
  \addplot [mark=none, black] coordinates {(0,5) (1.5,5) (1.5,6) (9.5,6) (9.5,5) (14,5)};
  \addplot [mark=none, black] coordinates {(0,7) (1,7) (1,8) (9.7,8) (9.7,7) (14,7)};
  \addplot +[mark=none, dashed, black] coordinates {(5,0) (5,9)};
  \addplot +[mark=none, dashed, black] coordinates {(7,0) (7,9)};
  \addplot +[mark=none, dashed, blue] coordinates {(11,0) (11,9)};
  \addplot +[mark=none, dashed, red] coordinates {(13,0) (13,9)};
 \end{axis}
\end{tikzpicture}
\end{document}

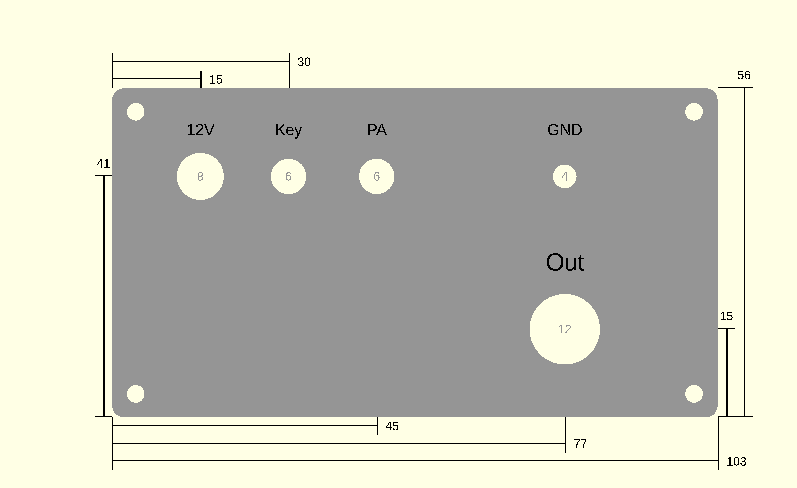
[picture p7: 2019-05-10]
doc/fig/BackPanel.png

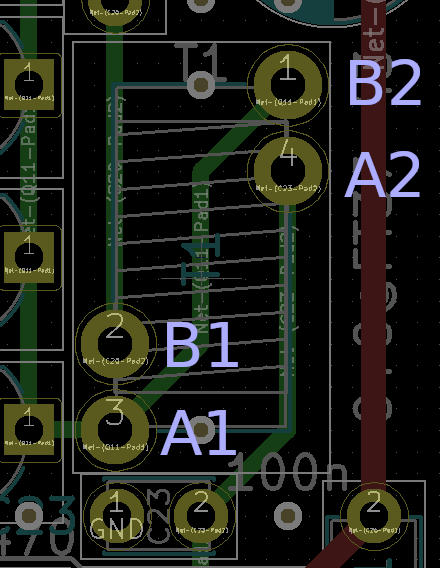
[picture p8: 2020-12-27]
doc/fig/PA_T1.png

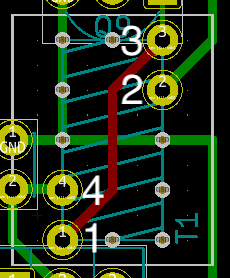
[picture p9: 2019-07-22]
doc/fig/T1.png

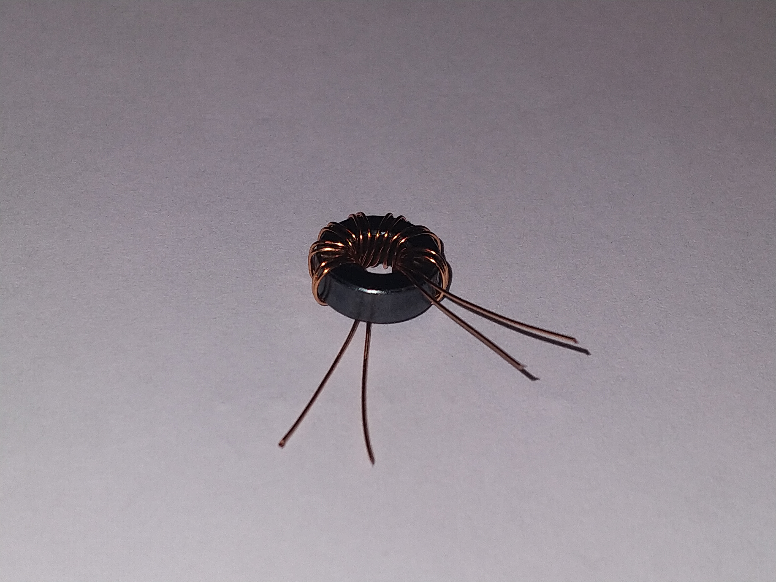
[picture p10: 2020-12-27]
doc/fig/PA_T1_IMG.jpg

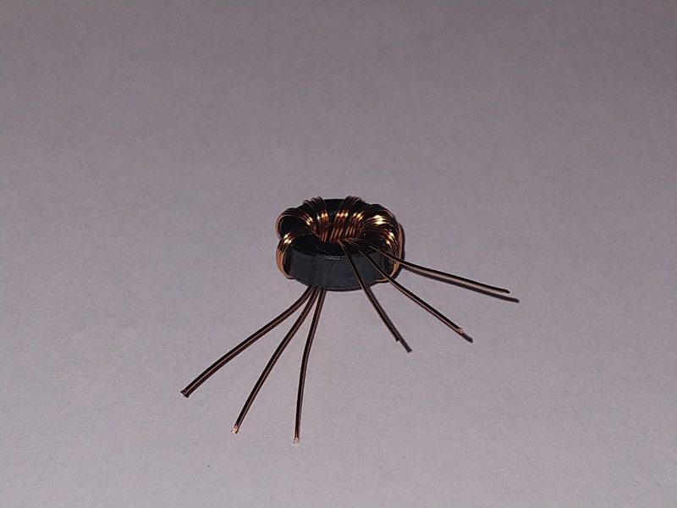
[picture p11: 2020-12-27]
doc/fig/RX_T1_IMG_small.jpg

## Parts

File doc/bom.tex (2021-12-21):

\begin{longtable}{|p{0.02\textwidth}|p{0.02\textwidth}|p{0.3\textwidth}|p{0.3\textwidth}|p{0.07\textwidth}|p{0.07\textwidth}|}\hline
\# & & Value & Reichelt & Cost & Sum \\ \hline\hline
1 & $\square$ & 10R & METALL 10,0 & 0,05 \euro & 0,05 \euro \\
6 & $\square$ & 100R & METALL 100 & 0,05 \euro & 0,29 \euro \\
1 & $\square$ & 220R & METALL 220 & 0,05 \euro & 0,05 \euro \\ 
1 & $\square$ & 470R & METALL 470 & 0,05 \euro & 0,05 \euro \\
4 & $\square$ & 1k & METALL 1,00K & 0,05 \euro & 0,20 \euro \\
1 & $\square$ & 2.2k & METALL 2,20K & 0,05 \euro & 0,05 \euro \\
9 & $\square$ & 3.3k & METALL 3,30K & 0,05 \euro & 0,44 \euro \\
1 & $\square$ & 4.3k & METALL 4,30K & 0,05 \euro & 0,05 \euro \\
2 & $\square$ & 4.7k & METALL 4,70K & 0,05 \euro & 0,10 \euro \\
1 & $\square$ & 5.1k & METALL 5,10K & 0,05 \euro & 0,05 \euro \\
1 & $\square$ & 7.5k & METALL 7,50K & 0,05 \euro & 0,05 \euro \\
17 & $\square$ & 10k & METALL 10,0K & 0,05 \euro & 0,83 \euro \\
2 & $\square$ & 30k & METALL 30,0K & 0,05 \euro & 0,10 \euro \\
2 & $\square$ & 33k & METALL 33,0K & 0,05 \euro & 0,10 \euro \\
2 & $\square$ & 36k & METALL 36,0K & 0,05 \euro & 0,10 \euro \\
2 & $\square$ & 47k & METALL 47,0K & 0,05 \euro & 0,10 \euro \\
4 & $\square$ & 100k & METALL 100K & 0,05 \euro & 0,20 \euro \\
1 & $\square$ & 120k & METALL 120K & 0,05 \euro & 0,05 \euro \\
1 & $\square$ & 470k & METALL 470K & 0,05 \euro & 0,05 \euro \\
2 & $\square$ & 50k & 64W-50K & 0,31 \euro & 0,62 \euro \\
1 & $\square$ & 500R & 64W-500 & 0,27 \euro & 0,27 \euro \\
1 & $\square$ & 10k & ACP 6-L 10K & 0,21 \euro & 0,21 \euro \\ \hline
2 & $\square$ & 100p & NPO-2,5 100P & 0,07 \euro & 0,14 \euro \\
4 & $\square$ & 220p & NPO-2,5 220P & 0,08 \euro & 0,32 \euro \\
4 & $\square$ & 470p & NPO-2,5 470P & 0,09 \euro & 0,36 \euro \\
2 & $\square$ & 820p & Conrad: 1578706 & 0,16 \euro & 0,32 \euro \\
3 & $\square$ & 1n & X7R-2,5 1,0N & 0,07 \euro & 0,21 \euro \\
2 & $\square$ & 1n & NPO-2,5 1,0N & 0,09 \euro & 0,18 \euro \\
2 & $\square$ & 1.5n & X7R-2,5 1,5N & 0,07 \euro & 0,14 \euro \\
2 & $\square$ & 3.3n & X7R-2,5 3,3N & 0,07 \euro & 0,14 \euro \\
3 & $\square$ & 10n & X7R-2,5 10N & 0,07 \euro & 0,21 \euro \\
5 & $\square$ & 47n & X7R-2,5 47N & 0,11 \euro & 0,55 \euro \\
35 & $\square$ & 100n & Z5U-2,5 100N & 0,05 \euro & 1,75 \euro \\
5 & $\square$ & 470n & Z5U-5 470N & 0,19 \euro & 0,95 \euro \\
3 & $\square$ & 1u & Z5U-5 1,0µ & 0,26 \euro & 0,78 \euro \\ \hline		
3 & $\square$ & 10u & RAD 10/35 & 0,02 \euro & 0,06 \euro \\
3 & $\square$ & 100u & RAD 100/16 & 0,03 \euro & 0,09 \euro \\
1 & $\square$ & 220u & RND 150ECR AY & 0,06 \euro & 0,06 \euro \\ \hline
1 & $\square$ & 22u & L-07HCP 22µ & 0,38 \euro & 0,38 \euro \\
9 & $\square$ & 100u & L-MICC 100µ & 0,27 \euro & 2,43 \euro \\ \hline
2 & $\square$ & FT37-43 & FT 37-43 & 0,58 \euro & 1,16 \euro \\
6 & $\square$ & T 37-6 & T 37-6 & 0,78 \euro & 4,68 \euro \\
6 & $\square$ & T 37-2 & T 37-2 & 0,54 \euro & 3,24 \euro \\ \hline
7 & $\square$ & 1N4148 & 1N 4148 & 0,02 \euro & 0,14 \euro \\
1 & $\square$ & 1N4001 & 1N 4001 & 0,02 \euro & 0,02 \euro \\
4 & $\square$ & 5.1V Zener & RND 1N751A &0,02 \euro & 0,08 \euro \\
7 & $\square$ & BS170 & BS 170 & 0,10 \euro & 0,70 \euro \\
5 & $\square$ & 2N3904 & 2N 3904 & 0,04 \euro & 0,20 \euro \\
1 & $\square$ & 2SB772 & SB 772 & 0,24 \euro & 0,24 \euro \\
1 & $\square$ & FST3253 & SOIC-16, Ebay & 2,00 \euro & 2,00 \euro \\
5 & $\square$ & LM833 & LM 833 & 0,90 \euro & 4,50 \euro \\
1 & $\square$ & LM386 & LM 386 DIP & 0,22 \euro & 0,22 \euro \\
6 & $\square$ & DIP-8 socket (optional) & GS 8 & 0,04 \euro & 0,24 \euro \\
1 & $\square$ & 74AC74 & Kessler: 522421 & 0,36 \euro & 0,36 \euro \\
1 & $\square$ & 74HCT00 & 74HCT 00 & 0,33 \euro & 0,33 \euro \\
1 & $\square$ & L7805 & L 7805 CV & 0,25 \euro & 0,25 \euro \\
1 & $\square$ & ATmega328-PU & ATMEGA 328P-PU & 2,50 \euro & 2,50 \euro \\
1 & $\square$ & DIP-28 socket (optional) & GS 28-S & 0,10 \euro & 0,10 \euro \\
1 & $\square$ & SI5351 breakout & Adafruit & 7,35 \euro & 7,35 \euro \\ \hline
4 & $\square$ & G6S-2 & NA 12W K & 0,96 \euro & 3,84 \euro \\ \hline
2 & $\square$ & 1x10 pin-header long & STAPELLEISTE 10 & 0,38 \euro & 0,76 \euro \\
1 & $\square$ & 2x3 pin-header & MPE 087-2-006 & 0,14 \euro & 0,14 \euro \\
1 & $\square$ & 1x7 pin-socket & MPE 156-1-007 & 0,37 \euro & 0,27 \euro \\
2 & $\square$ & 1x2 90deg & PSS 254/2W & 0,02 \euro & 0,04 \euro \\
2 & $\square$ & 1x2 plug & PSK 254/2W & 0,02 \euro & 0,04 \euro \\
1 & $\square$ & 1x3 90deg & PSS 254/3W & 0,04 \euro & 0,04 \euro \\
1 & $\square$ & 1x3 plug & PSK 254/3W & 0,02 \euro & 0,02 \euro \\
1 & $\square$ & 1x4 90deg & PSS 254/4W & 0,09 \euro & 0,09 \euro \\
1 & $\square$ & 1x4 plug & PSK 254/4W & 0,02 \euro & 0,02 \euro \\
1 & $\square$ & 1x10 90deg & PSS 254/10W & 0,10 \euro & 0,10 \euro \\
1 & $\square$ & 1x10 plug & PSK 254/10W & 0,08 \euro & 0,08 \euro \\
2 & $\square$ & contacts & PSK-KONTAKTE & 0,29 \euro & 0,58 \euro \\
2 & $\square$ & head-phone socket & EBS 35 & 0,30 \euro & 0,60 \euro\\
1 & $\square$ & TX-OC & CBP & 0,21 \euro & 0,21 \euro \\
1 & $\square$ & BNC & UG 1094W1 & 0,99 \euro & 0,99 \euro \\
1 & $\square$ & 1 x 8 socket & MPE 094-1-008 & 0,24 \euro & 0,14 \euro \\
1 & $\square$ & barrel jack & DC BU21 90 & 0,46 \euro & 0,46 \euro \\
3 & $\square$ & 1 x 2 socket & RND 205-00642 & 0,02 \euro & 0,06 \euro \\ \hline
1 & $\square$ & chassis top & KOH-2100 & 5,40 \euro & 5,40 \euro \\
1 & $\square$ & chassis bottom & KOH-4100 & 5,80 \euro & 5,80 \euro \\
1 & $\square$ & chassis front/back & DPL 2-4 & 7,99 \euro & 7,99 \euro \\
1 & $\square$ & 10k log pot & RK11K112-LOG10K & 1,35 \euro & 1,35 \euro \\
1 & $\square$ & rotary encoder & STEC11B03 & 3,70 \euro & 3,70 \euro \\
1 & $\square$ & LCD display & LCD-PM 2X8-5 A & 7,30 \euro & 7,30 \euro \\
1 & $\square$ & switch & KIPP 1A11 & 1,20 \euro & 1,20 \euro \\
1 & $\square$ & barrel plug & HS 21-13 & 0,20 \euro & 0,20 \euro \\
2 & $\square$ & fuse holder (optional) & RND 170-00170 & 0,19 \euro & 0,38 \euro \\
2 & $\square$ & 2A flink (optional) & ESKA 520.020 & 0,09 \euro & 0,18 \euro \\
1 & $\square$ & speaker (optional) & LSM-S20K & 2,70 \euro & 2,70 \euro \\ \hline \hline
\multicolumn{4}{|l}{Total\footnote{Prices may change over time.}} & \multicolumn{2}{r|}{\textbf{89,26 \euro}} \\ \hline
\end{longtable}

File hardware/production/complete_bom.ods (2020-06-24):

Qty | Value | Reichelt | Preis | Summe
1 | 10R | METALL 10,0 | 0,05 € | 0,05 €
6 | 100R | METALL 100 | 0,05 € | 0,29 €
1 | 220R | METALL 220 | 0,05 € | 0,05 €
1 | 470R | METALL 470 | 0,05 € | 0,05 €
4 | 1k | METALL 1,00K | 0,05 € | 0,20 €
1 | 2.2k | METALL 2,20K | 0,05 € | 0,05 €
9 | 3.3k | METALL 3,30K | 0,05 € | 0,44 €
1 | 4.3k | METALL 4,30K | 0,05 € | 0,05 €
2 | 4.7k | METALL 4,70K | 0,05 € | 0,10 €
1 | 5.1k | METALL 5,10K | 0,05 € | 0,05 €
1 | 7.5k | METALL 7,50K | 0,05 € | 0,05 €
17 | 10k | METALL 10,0K | 0,05 € | 0,83 €
2 | 30k | METALL 30,0K | 0,05 € | 0,10 €
2 | 33k | METALL 33,0K | 0,05 € | 0,10 €
2 | 36k | METALL 36,0K | 0,05 € | 0,10 €
2 | 47k | METALL 47,0K | 0,05 € | 0,10 €
4 | 100k | METALL 100K | 0,05 € | 0,20 €
1 | 120k | METALL 120K | 0,05 € | 0,05 €
1 | 470k | METALL 470K | 0,05 € | 0,05 €
2 | 50k | 64W-50K | 0,31 € | 0,62 €
1 | 500R | 64W-500 | 0,27 € | 0,27 €
1 | 10k | ACP 6-L 10K | 0,21 € | 0,21 €
2 | 100p | NPO-2,5 100P | 0,07 € | 0,14 €
4 | 220p | NPO-2,5 220P | 0,08 € | 0,32 €
4 | 470p | NPO-2,5 470P | 0,09 € | 0,36 €
2 | 820p | C: 1578706 | 0,16 € | 0,32 €
3 | 1n | X7R-2,5 1,0N | 0,07 € | 0,21 €
2 | 1n | NPO-2,5 1,0N | 0,09 € | 0,18 €
2 | 1.5n | X7R-2,5 1,5N | 0,07 € | 0,14 €
2 | 3.3n | X7R-2,5 3,3N | 0,07 € | 0,14 €
3 | 10n | X7R-2,5 10N | 0,07 € | 0,21 €
5 | 47n | X7R-2,5 47N | 0,11 € | 0,55 €
35 | 100n | Z5U-2,5 100N | 0,05 € | 1,75 €
5 | 470n | Z5U-5 470N | 0,19 € | 0,95 €
3 | 1u | Z5U-5 1,0µ | 0,26 € | 0,78 €
3 | 10u | RAD 10/35 | 0,02 € | 0,06 €
3 | 100u | RAD 100/16 | 0,03 € | 0,09 €
1 | 220u | RND 150ECR AY | 0,06 € | 0,06 €
1 | 22u | L-07HCP 22µ | 0,38 € | 0,38 €
7 | 100u | L-MICC 100µ | 0,27 € | 1,89 €
2 | FT37-43 | FT 37-43 | 0,58 € | 1,16 €
6 | T 37-6 | T 37-6 | 0,78 € | 4,68 €
6 | T 37-2 | T 37-2 | 0,54 € | 3,24 €
7 | 1N4148 | 1N 4148 | 0,02 € | 0,14 €
1 | 1N4001 | 1N 4001 | 0,02 € | 0,02 €
7 | BS170 | BS 170 | 0,10 € | 0,70 €
5 | 2N3904 | 2N 3904 | 0,04 € | 0,20 €
1 | BD140 | BD 140-16 STM | 0,19 € | 0,19 €
1 | FST3253 | Ebay | 2,00 € | 2,00 €
5 | LM833 | LM 833 | 0,90 € | 4,50 €
1 | LM386 | LM 386 DIP | 0,22 € | 0,22 €
6 | DIP-8 socket | GS 8 | 0,04 € | 0,24 €
1 | 74AC74 | Kessler: 522421 | 0,36 € | 0,36 €
1 | 74HCT00 | 74HCT 00 | 0,33 € | 0,33 €
1 | L7805 | L 7805 CV | 0,25 € | 0,25 €
1 | ATmega328-PU | ATMEGA 328P-PU | 2,50 € | 2,50 €
1 | DIP-28 socket | GS 28-S | 0,10 € | 0,10 €
1 | SI5351Breakout | Adafruit | 7,35 € | 7,35 €
4 | G6S-2 | NA 12W K | 0,96 € | 3,84 €
2 | 1x10 pin-header long | STAPELLEISTE 10 | 0,38 € | 0,76 €
1 | 2x3 pin-header | RND 205-00634 | 0,03 € | 0,03 €
1 | 1x7 pin-socket | RND 205-00647 | 0,10 € | 0,10 €
2 | 1x2 90deg | PSS 254/2W | 0,02 € | 0,04 €
2 | 1x2 plug | PSK 254/2W | 0,02 € | 0,04 €
1 | 1x3 90deg | PSS 254/3W | 0,04 € | 0,04 €
1 | 1x3 plug | PSK 254/3W | 0,02 € | 0,02 €
1 | 1x4 90deg | PSS 254/4W | 0,09 € | 0,09 €
1 | 1x4 plug | PSK 254/4W | 0,02 € | 0,02 €
1 | 1x8 90deg | PSS 254/8W | 0,10 € | 0,10 €
1 | 1x8 plug | PSK 254/8W | 0,08 € | 0,08 €
2 | contacts | PSK-KONTAKTE | 0,29 € | 0,58 €
1 | TX-OC | RND 205-00698 | 0,57 € | 0,57 €
1 | Key | EBS 35 | 0,30 € | 0,30 €
1 | BNC | UG 1094W1 | 0,99 € | 0,99 €
1 | 1 x 8 Socket | RND 205-00648 | 0,10 € | 0,10 €
1 | Barrel Jack | CLIFF FCR681465P | 0,77 € | 0,77 €
3 | 1 x 2 Socket | RND 205-00642 | 0,02 € | 0,06 €
1 | chassis top | KOH-2100 | 5,40 € | 5,40 €
1 | chassis bottom | KOH-4100 | 5,80 € | 5,80 €
1 | chassis front/back | DPL 2-4 | 7,99 € | 7,99 €
1 | 10k log pot | RK11K112-LOG10K | 1,35 € | 1,35 €
1 | rotary encoder | STEC11B03 | 3,70 € | 3,70 €
1 | LCD display | LCD-PM 2X8-5 A | 7,30 € | 7,30 €
1 | Head-phone socket | EBS 35 | 0,30 € | 0,30 €
1 | Switch | KIPP 1A11 | 1,20 € | 1,20 €
1 | barrel plug | HS 21-13 | 0,20 € | 0,20 €
2 | fuse holder (optional) | RND 170-00170 | 0,19 € | 0,38 €
2 | 2A flink (optional) | ESKA 520.020 | 0,09 € | 0,18 €
1 | speaker (optional) | LSM-S20K | 2,70 € | 2,70 €
 |  | Summe |  | 85,73 €

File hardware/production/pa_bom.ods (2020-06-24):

Qty | Reference(s) | Value | Reichelt | Price | Cost
2 | R12, R13 | 100R | METALL 100 | 0,05 € | 0,10 €
1 | R9 | 470R | METALL 470 | 0,05 € | 0,05 €
1 | R10 | 1k | METALL 1,00K | 0,05 € | 0,05 €
1 | R14 | 4.7k | METALL 4,70K | 0,05 € | 0,05 €
7 | R1, R3, R5, R7, R11, R15, R16 | 10k | METALL 10,0K | 0,05 € | 0,34 €
4 | R2, R4, R6, R8 | 100k | METALL 100K | 0,05 € | 0,20 €
 |  |  |  |  | 0,00 €
2 | C2, C15 | 100p | NPO-2,5 100P | 0,07 € | 0,14 €
4 | C3, C6, C11, C16 | 220p | NPO-2,5 220P | 0,08 € | 0,32 €
4 | C4, C7, C12, C17 | 470p | NPO-2,5 470P | 0,09 € | 0,36 €
2 | C5, C18 | 820p | C: 1578706 | 0,16 € | 0,32 €
2 | C8, C13 | 1n | NPO-2,5 1,0N | 0,09 € | 0,18 €
2 | C9, C14 | 1.5n | X7R-2,5 1,5N | 0,07 € | 0,14 €
12 | C1, C10, C19, C20, C22, C23, C24, C27, C28, C29, C30 | 100n | Z5U-2,5 100N | 0,03 € | 0,36 €
1 | C25 | 1u | Z5U-5 1,0µ | 0,26 € | 0,26 €
 |  |  |  |  | 0,00 €
1 | C26 | 220u | RND 150ECR AY | 0,06 € | 0,06 €
 |  |  |  |  | 0,00 €
1 | L14 | 22u | L-07HCP 22µ | 0,38 € | 0,38 €
1 | L13 | 100u | L-MICC 100µ | 0,27 € | 0,27 €
3 | L1, L5, L9 | 330n, 11T | T 37-6 | 0,78 € | 2,34 €
3 | L2, L6, L10 | 480n, 13T | T 37-6 | 0,78 € | 2,34 €
3 | L3, L7, L11 | 750n, 14T | T 37-2 | 0,54 € | 1,62 €
3 | L4, L8, L12 | 1700n, 21T | T 37-2 | 0,54 € | 1,62 €
1 | T1 | 8+8 @ FT37-43 | FT 37-43 | 0,58 € | 0,58 €
 |  |  |  |  | 0,00 €
4 | K1, K2, K3, K4 | G6S-2 | NA 12W K | 0,96 € | 3,84 €
 |  |  |  |  | 0,00 €
4 | D1, D2, D3, D5 | 1n4148 | 1N 4148 | 0,02 € | 0,08 €
1 | D4 | 1N4001 | 1N 4001 | 0,02 € | 0,02 €
 |  |  |  |  | 0,00 €
4 | Q1, Q2, Q3, Q10 | 2N3904 | 2N 3904 | 0,04 € | 0,16 €
6 | Q4, Q6, Q7, Q8, Q9, Q11 | BS170 | BS 170 | 0,10 € | 0,60 €
1 | Q5 | BD140 | BD 140-16 STM | 0,19 € | 0,19 €
 |  |  |  |  | 0,00 €
1 | U1 | 74HCT00 | 74HCT 00 | 0,33 € | 0,33 €
 |  |  |  |  | 0,00 €
1 | J1 | BNC | UG 1094W1 | 0,99 € | 0,99 €
1 | J2 | 1 x 8 Socket | RND 205-00648 | 0,10 € | 0,10 €
1 | J3 | Barrel Jack + Switch | CLIFF FCR681465P | 0,77 € | 0,77 €
3 | J6, J7, J11 | 1 x 2 Socket | RND 205-00642 | 0,02 € | 0,06 €
 |  |  | Summe |  | 19,21 €

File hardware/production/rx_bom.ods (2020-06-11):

Qty | Reference(s) | Value | Reichelt | Preis | Summe
1 | R15 | 10R | METALL 10,0 | 0,05 € | 0,05 €
4 | R20, R21, R22, R23 | 100R | METALL 100 | 0,05 € | 0,20 €
1 | R43 | 220R | METALL 220 | 0,05 € | 0,05 €
3 | R38, R39, R42 | 1k | METALL 1,00K | 0,05 € | 0,15 €
1 | R13 | 2.2k | METALL 2,20K | 0,05 € | 0,05 €
9 | R7, R27, R29, R30, R31, R33, R35, R36, R37 | 3.3k | METALL 3,30K | 0,05 € | 0,44 €
1 | R32 | 4.3k | METALL 4,30K | 0,05 € | 0,05 €
1 | R4 | 4.7k | METALL 4,70K | 0,05 € | 0,05 €
1 | R26 | 5.1k | METALL 5,10K | 0,05 € | 0,05 €
1 | R34 | 7.5k | METALL 7,50K | 0,05 € | 0,05 €
10 | R1, R2, R6, R11, R18, R24, R25, R28, R40, R41 | 10k | METALL 10,0K | 0,05 € | 0,49 €
2 | R9, R10 | 30k | METALL 30,0K | 0,05 € | 0,10 €
2 | R12, R14 | 33k | METALL 33,0K | 0,05 € | 0,10 €
2 | R16, R17 | 36k | METALL 36,0K | 0,05 € | 0,10 €
2 | R3, R5 | 47k | METALL 47,0K | 0,05 € | 0,10 €
1 | R8 | 120k | METALL 120K | 0,05 € | 0,05 €
1 | R19 | 470k | METALL 470K | 0,05 € | 0,05 €
2 | RV1, RV2 | 50k | 64W-50K | 0,31 € | 0,62 €
1 | RV3 | 500R | 64W-500 | 0,27 € | 0,27 €
1 | RV4 | 10k | ACP 6-L 10K | 0,21 € | 0,21 €
3 | C13, C20, C23 | 1n | X7R-2,5 1,0N | 0,07 € | 0,21 €
2 | C25, C27 | 3.3n | X7R-2,5 3,3N | 0,07 € | 0,14 €
3 | C30, C31, C35 | 10n | X7R-2,5 10N | 0,07 € | 0,21 €
5 | C12, C17, C18, C21, C33 | 47n | X7R-2,5 47N | 0,11 € | 0,55 €
23 | C3, C8, C11, C22, C24, C26, C29, C32, C34, C37, C38, C39, C40, C41, C46, C47, C48, C49, C50, C51, C52, C53, C54 | 100n | Z5U-2,5 100N | 0,05 € | 1,15 €
5 | C4, C5, C6, C7, C36 | 470n | Z5U-5 470N | 0,19 € | 0,95 €
2 | C1, C28 | 1u | Z5U-5 1,0µ | 0,26 € | 0,52 €
3 | C15, C16, C42 | 10u | RAD 10/35 | 0,02 € | 0,06 €
3 | C2, C14, C19 | 100u | RAD 100/16 | 0,03 € | 0,09 €
6 | L1, L3, L4, L5, L6, L7, L8, L9 | 100u | L-MICC 100µ | 0,27 € | 1,62 €
1 | T1 | 3 x 8 @ FT37-43 | FT 37-43 | 0,58 € | 0,58 €
1 | D1 | 1N4148 | 1N 4148 | 0,02 € | 0,02 €
1 | Q1 | BS170 | BS 170 | 0,10 € | 0,10 €
1 | Q2 | 2N3904 | 2N 3904 | 0,04 € | 0,04 €
1 | U1 | FST3253 | Ebay | 2,00 € | 2,00 €
5 | U3, U5, U6, U7, U8 | LM833 | LM 833 | 0,90 € | 4,50 €
1 | U4 | LM386 | LM 386 DIP | 0,22 € | 0,22 €
1 | U9 | 74AC74 | Ebay | 1,00 € | 1,00 €
1 | U10 | L7805 | L 7805 CV | 0,25 € | 0,25 €
1 | U11 | ATmega328-PU | ATMEGA 328P-PU | 2,50 € | 2,50 €
1 | - | SI5351Breakout | Adafruit | 7,35 € | 7,35 €
2 | J1, J3, J4, J11 | 1x10 pin-header long | STAPELLEISTE 10 | 0,38 € | 0,76 €
1 | J6 | 2x3 pin-header | RND 205-00634 | 0,03 € | 0,03 €
1 | J9 | 1x7 pin-socket | RND 205-00647 | 0,10 € | 0,10 €
2 | J2, J7 | 1x2 90deg | PSS 254/2W | 0,02 € | 0,04 €
2 | -- | 1x2 plug | PSK 254/2W | 0,02 € | 0,04 €
1 | J8 | 1x3 90deg | PSS 254/3W | 0,04 € | 0,04 €
1 | -- | 1x3 plug | PSK 254/3W | 0,02 € | 0,02 €
1 | J10 | 1x4 90deg | PSS 254/4W | 0,09 € | 0,09 €
1 | -- | 1x4 plug | PSK 254/4W | 0,02 € | 0,02 €
1 | LCD1 | 1x8 90deg | PSS 254/8W | 0,10 € | 0,10 €
1 | -- | 1x8 plug | PSK 254/8W | 0,08 € | 0,08 €
1 | -- | contacts | PSK-KONTAKTE | 0,29 € | 0,29 €
1 | J13 | TX-OC | RND 205-00698 | 0,57 € | 0,57 €
1 | J5 | Key | EBS 35 | 0,30 € | 0,30 €
 |  |  |  | Summe: | 29,748

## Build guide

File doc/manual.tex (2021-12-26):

\documentclass[10pt, a4paper,twoside]{scrartcl}
\usepackage{amsmath}
\usepackage{amssymb}
\usepackage{graphicx}
\usepackage{subcaption}
\usepackage{float}
\usepackage[top=2cm,bottom=3cm,outer=2cm,inner=3cm]{geometry}\usepackage[utf8]{inputenc}
\usepackage{hyperref}
\usepackage[multiple]{footmisc}
\usepackage{parskip}
\usepackage{wrapfig}
\usepackage{xfrac}
\usepackage{xcolor}
\usepackage{tikz}
\usetikzlibrary{arrows,automata}
\usetikzlibrary{arrows.meta}
\usepackage{longtable}
\usepackage{pdfpages}
\usepackage[tikz]{bclogo}
\usepackage{eurosym}
\usepackage{listings}

\hypersetup{
    colorlinks=true,
    linkcolor=blue,
    filecolor=magenta,      
    urlcolor=cyan
}

\restylefloat{table}

\newcommand{\warn}[1]{\textbf{#1}}
\newcommand{\con}[1]{\texttt{#1}}
\newcommand{\dis}[1]{\textbf{\texttt{#1}}}

\newenvironment{remember}{\begin{bclogo}[couleur=blue!30,arrondi=.1,logo=\bccrayon,ombre=true]{Remember}}{\end{bclogo}}   
\newenvironment{remark}{\begin{bclogo}[couleur=blue!30,arrondi=.1,logo=\bcinfo,ombre=true]{Remark}}{\end{bclogo}}   
\newenvironment{warning}{\begin{bclogo}[couleur=red!30,arrondi=.1,logo=\bcattention,ombre=true]{Warning}}{\end{bclogo}}   

\title{QRP CW Transceiver Manual}
\subtitle{Board rev. 2, Firmware rev. 2.5}
\author{Hannes Matuschek -- DM3MAT\\\texttt{<dm3mat [at] darc [dot] de>}\\\texttt{https://dm3mat.darc.de/cw2019}}
\date{\today}

\begin{document}
\maketitle

\begin{abstract}
This document describes the assembly, alignment and usage of the second revision of my small, portable CW TRX. If you cannot find any \emph{rev 2} markings on your boards, this is the wrong document!

The main difference to the first revision is the mixer. Instead of a \texttt{74HC4053}, which has some significant damping on higher frequencies, the second revision relies on the famous \texttt{FST3253} switch. This allows for using the TRX well into the 10m band. Additionally, the board layout has been changed to allow for board-to-board interconnects and proper connectors to ease the assembly of the final TRX. To this end there are only two boards (instead of three) with a $10\times 8\,cm$ footprint that can be squeezed into a $10 \times 10\times 5\,cm$ Fischer-chassis (\texttt{KOH-2100} + \texttt{KOH-4100} + \texttt{DPL 2-4}).  Using this chassis, the receiver will weight about $580\,g$ (without batteries \& key).
\end{abstract}
\thispagestyle{empty}
\vfill
\begin{center}
 
\end{center}

\cleardoublepage
\tableofcontents
\thispagestyle{empty}

\cleardoublepage
\section{Receiver \& Controller Board} \label{sec:rx}
 The receiver and controller board houses the majority of the TRX circuitry. The receiver is a direct conversion receiver using the \texttt{FST3253} CMOS switch as a sample-hold mixer (in conjunction with \texttt{C4-C7}). The latter takes two VFO input signals with $90^\circ$ phase difference and produces four mixing products with $0^\circ$, $90^\circ$, $180^\circ$ and $270^\circ$ phase shifts. These signal pairs ($0^\circ$ + $180^\circ$) and ($90^\circ$ + $270^\circ$) are fed into two independent difference-amplifiers (\texttt{U6A}, \texttt{U6B}) producing two $90^\circ$ phase-shifted audio signals (for USB, $-90^\circ$ for LSB). The following phase-shift-network \texttt{U7} \& \texttt{U8} then shifts back the audio phase by $-90^\circ$ at $700\,Hz$. Finally the resulting signals are added at \texttt{RV3}. Here the USB signals will interfere constructively while the LSB signals will cancel out. This phasing method allows for an unwanted side-band suppression in a direct conversion receiver. The next stages (\texttt{U3} \& \texttt{U5}) will filter and amplify audio signals near $700\,Hz$, which are then fed into the audio PA \texttt{U4}. 
 
 The controller and VFO section of the board consists of a \texttt{ATMega 328P} MCU controlling the \texttt{SI5351} PLL oscillator. The \texttt{CLK2} signal of the PLL drives the two flip-flops \texttt{U9}, which divide the \texttt{CLK2} frequency by four and produce a proper $90^\circ$ phase-shifted signal for the mixer.
 
\subsection{Controller Assembly}
 In a first step, the controller section of the receiver board is assembled. Install \texttt{C2}, \texttt{C26}, \texttt{J7} connector, \texttt{L3}, \texttt{C38}, \texttt{C40}, \texttt{C41}, \texttt{C42}, \texttt{U10}, \texttt{J10}, \texttt{C14}, \texttt{J3}, \texttt{R3}, \texttt{C46}, \texttt{R4}, \texttt{U11} + Socket, \texttt{LCD1} connector, \texttt{R43}, \texttt{R5}, \texttt{RV4}, \texttt{J9} connector, \texttt{R41}, \texttt{R40}, \texttt{C39} \& \texttt{U9} first. 

\begin{remark}
 Due to the compact layout of the PCB, the component references might be hard to read. I therefore used a very nice plugin for KiCad to export an \href{https://dm3mat.darc.de/cw2019/rx_rev2_ibom.html}{interactive BOM} for this board. This certainly helps to find the spots where all components are placed, even if the silk-screen is hard to read.
\end{remark}

\begin{warning}
The metal tab of the TO-220 package of \texttt{U10} is usually connected directly to the center pin (GND). Please check beforehand if this is the case for your variant. Some rare packages connect this pad to \emph{+5V} leading to a nice \& solid short-circuit that will blow either \texttt{U10} or \texttt{L3} or both.
\end{warning}

If you got one of the rare TO-220 variant of U10 that connects the metal tab to +5V, use a mica-insulator between \texttt{U10} and the PCB. If you have enough head-room, you could also install \texttt{U10} vertically, heat-sinking to the PCB is not necessary.

 \texttt{R43} limits the current to the LCD back-light. By default a $220\,\Omega$ resistor is installed. This limits the current to about $23\,mA$. This results in a very dim back-light but reduces the current consumption from max. $120\, mA$ (\texttt{R43} shorted). I personally consider this dim setting the most useful: During daylight a back light makes no sense, as the LCD is perfectly readable. During night without any external light-sources, a very dim back light is still sufficient to read the LCD. There is simply no need to drain the battery for unused or too-bright back lights. If you use the TRX only at home and current consumption is not an issue, you may choose a smaller value for \texttt{R43} or even bridge it for maximum brightness.
 
\begin{remark} 
 You may also replace the resistor \texttt{R43} with a push-button at the front panel to switch the back-light on when needed.
\end{remark}
 
 Then, assemble the switch plug and (top right corner labeled \emph{SW}). Connect a $12\,V$ power-supply (ideally current-limited to not more than $100\,mA$) to the pads of the supply connector (also top-right corner) labeled \emph{+ G}, where the \emph{+} pad is $+12\,V$ and the \emph{G} pad is ground. 

\begin{remember}
 The receiver board itself has no reverse-polarity protection. So be careful when connecting the RX board to the power-supply!
\end{remember}
  
 If nothing blows up, switch the TRX off and continue assembling the rotary-encoder and LCD plugs. 
 
 The rotary encoder plug has the following connections (read left-to-right): \emph{Button}, \emph{Encoder B}, \emph{Encoder A}, \emph{Ground}. 

 The LCD-plug has the following connections (read left-to-right): \emph{5V} pin 2 on LCD, \emph{contrast} pin 3 on LCD, \emph{LED backlight} pin 15 on LCD, \emph{GND} pin 1 on LCD, \emph{RS (register selection)} pin 4 on LCD, \emph{D4-D7} pins 11-14 on LCD, \emph{chip-enable (EN)} pin 6 on LCD. You also need to connect pins 5 and 16 on the LCD-board directly to ground (pin 1 on LCD).
 
 Plug the LCD \& rotary encoder into the board and install the \texttt{ATMega328} MCU. Then connect the board to the power-supply. If you got a pre-programmed MCU you should see a brief greeting on the LCD. If you do not see anything at all or a series of back blocks on the screen, you may have to set the LCD supply/contrast setting using RV4. If you still don't see anything on the LCD, double-check your connects to the LCD! 

\subsection{Testing PLL}
In a next step, verify the proper operation of the \texttt{SI5351} PLL. First, install the \texttt{SI5351} break-out board. 

\begin{warning}
 Be careful when inserting the \texttt{SI5351} beakout-board, there is no protection in the socket to plug it in the wrong way: The board should overlap with the LCD connector not U9!
\end{warning}
 
Then switch on the RX and verify that there is a $3.5MHz$ signal at pins 8, 9, 11 and 12 of \texttt{U9}. If not, verify that there is a $14.0Mhz$ signal at the \texttt{CLK2} output of the \texttt{SI5351} break-out board. 

You may also verify the $90^\circ$ phase-shift between pins 9 and 12 of \texttt{U9} using a dual-channel oscilloscope.

\begin{remark}
By default, the RX is wired to receive on the upper side-band (USB). If you prefer LSB-reception, you may break the jumper labeled \emph{USB} and put a solder-bride on jumper \emph{LSB}. You also need to set the side-band in the firmware.
\end{remark} 

If everything works fine for you so far, continue with assembling the rest of the receiver board.

\subsection{Receiver Assembly}
Before starting to assemble the receiver, disconnect everything from the board. That is, remove the \texttt{SI5351}, LCD and encoder wires and also remove the power-supply wires.

In a first step, install the SMD SOIC-16 \texttt{FST3253} mixer. 

\begin{warning}
 Be careful! The \texttt{SI5351} as well as the \texttt{FST3253} are \textbf{very} sensitive to electrostatic discharge (ESD). Wear an antistatic wrist wrap and use an antistatic mat (if available) and avoid wearing wool or synthetic fibers. I personally destroyed two \texttt{FST3253} that way. 
\end{warning}

\paragraph{If you never soldered SMD components before} It is surprisingly simple. Get a sharp soldering-iron tip and thin solder (e.g., $0.75mm$) as well as plenty of flux. Put a lot of flux on the pads. Then put a small amount of solder on one of the pins, for example pin 1 in the bottom-right corner. Pick up the IC with pointy tweezers and place it on the board. Verify the orientation and alignment of the IC. Solder only pin 1 to the board by heating the pad and pushing the IC on the board. Then take a magnifying glass and verify the alignment of all pins with their pads. If needed, reheat pad 1 and improve the alignment. Once the alignment is right, you can start to solder the remaining pads. You do not need much solder! And remember: The flux will do all the work for you. If you got a solder-bridge between two pins, grab some desoldering-wig and remove the solder. 

Once the mixer is installed, it does not matter in which order the next components are installed. Complete the assembly of the board but leave the board-to-board interconnects (labeled \emph{TX, RX, +G} and the unlabeled 10-pin connector at the bottom) as well as the RCA plug labeled \emph{TX-OC } unpopulated for now. They will added in the final assembly step later.

\begin{remark}
The audio PA (\texttt{LM386}, \texttt{U4}) has plenty of amplification. If you want to use head-phones, you may leave \texttt{R13} and \texttt{C16} off the board. You may add them later if more audio amplification is needed.
\end{remark}

When winding the input transformer \texttt{T1}, cut 3 about 15-16cm long pieces of magnet wire and start the winding by pushing the three wires tough the core \textbf{from the back}. Hold them. Then make the next winding counter-clock wise by pushing the other end of the wires though the core from the front and continue to wind 8 turns on the core counter-clock wise. Every time the wires pass through the core, counts as a turn. 

\begin{figure}[ht!]
 \begin{subfigure}[t]{0.49\textwidth}
   \centering
   
   \caption{Footprint of T1}
 \end{subfigure}
 \begin{subfigure}[t]{0.49\textwidth}
   \centering
   
   \caption{T1 wound and labeled.}
 \end{subfigure}
 \caption{Before soldering the core, make sure the wires are aligned correctly using a multi-meter. That is, top-left connects to bottom left (i.e., A1 to A2), top-center to bottom-center (i.e., B1 to B2) and top right to bottom right pads (i.e., C1 to C2) on the board.}
\end{figure}

\begin{warning}
The audio PA being used has a tendency to oscillate, in particular if a small speaker is used. If it does so, it may drive the complete audio-chain into saturation. In this case, the audio-chain may feed-back $12\,V$ to the FST3253 mixer. This may destroy the hard-to-get mixer! To prevent this problem, you \textbf{should} install four 5.1V Zener-diodes in parallel to C4-C7. This limits the voltage that can be fed back to the mixer and saves it. 
\end{warning}

\subsection{Receiver Test and Alignment}
Once the receiver is completed, re-connect the top-right pads \emph{+ G} to the power-supply, prepare the volume and head-phone plug. Also connect a piece of coaxial cable to the \emph{RX/GN} pads in the top-left. This is the antenna input for the test. Depending on the selected band, you may need to increase the current-limit of the power supply to about $120\,mA$. 

\subsubsection{Frequency Alignment}
If a accurate frequency-counter is at hand, you may start your alignment by fixing the PLL offset. Select the 20m band and tune to $14.0007 MHz$. Then measure the frequency at the USB pad. You should read exactly $14.000 MHz$ (if the CW side-tone frequency is set to $700\,Hz$). If not, enter the Setup menu and select the \emph{PLL correction} option. Now adjust the correction until you read $14.000 MHz$ in the frequency counter.

\subsubsection{CW Filter Alignment}
Although the CW filter cannot be \emph{tuned}, variations in component values may lead to small variations in the center frequency of the narrow CW audio filter. For a proper alignment of the RX frequency-shift, the CW-tone must be set to the center frequency of the CW filter. Hence, measure the spectrum (e.g., using your PC sound card and an application that can display the audio spectrum) of the audio signal. Determine the center frequency of the CW filter and set the CW side-tone frequency (under \texttt{Menu}\ $\rightarrow$\ \texttt{Setup}\ $\rightarrow$\ \texttt{CW Tone}) to that value. This will also adjust the RX frequency-shift.

\begin{remember}
The displayed frequency is the frequency, the TRX will transmit on. It is not the beat-frequency the TRX is receiving on.
\end{remember}

\subsubsection{Side-band Suppression}
If an signal generator is at hand, tune the generator to $14.000 MHz$. Then select the 20m Band and tune to $14.0012 MHz$. You may hear a low-frequency tone (about $500Hz$). Tune \texttt{RV2} \& \texttt{RV3} to minimize the unwanted side-band tone. Then tune to $14.0016 MHz$. You may hear a high-frequency tone (about $900 Hz$). Tune \texttt{RV1} \& \texttt{RV3} to minimize the unwanted side-band tone. You may repeat the previous steps several times to obtain the optimal result. In my experience, the unwanted side-band suppression will work satisfactorily on all bands once aligned properly on 20m. 

With these steps, the alignment of the RX is completed and you may take the RX on a short ride through the bands.

\clearpage
\subsection{RX Component List}  \label{sec:rxcomp}
\begin{longtable}{|l|p{6cm}|l|l|} \hline 
\# & Component & Value & Remarks \\ \hline 
1 & R15 & 10R & \\
4 & R20, R21, R22, R23 & 100R & \\
1 & R43 & 220R & \\
3 & R38, R39, R42 & 1k & \\
1 & R13 & 2.2k & \\
9 & R7, R27, R29-R31, R33, R35-R37 & 3.3k & \\
1 & R32 & 4.3k & \\
1 & R4 & 4.7k & \\
1 & R26 & 5.1k & \\
1 & R34 & 7.5k & \\
10 & R1, R2, R6, R11, R18, R24, R25, R28, R40, R41 & 10k & \\
2 & R9, R10 & 30k & \\
2 & R12, R14 & 33k & \\
2 & R16, R17 & 36k & \\
2 & R3, R5 & 47k & \\
1 & R8 & 120k & \\
1 & R19 & 470k & \\
2 & RV1, RV2 & 50k & \\
1 & RV3 & 500R & \\
1 & RV4 & 10k & \\
3 & C13, C20, C23 & 1n & \\
2 & C25, C27 & 3.3n & \\
3 & C30, C31, C35 & 10n & \\
5 & C12, C17, C18, C21, C33 & 47n & \\
23 & C3, C8, C11, C22, C24, C26, C29, C32, C34, C37-C41, C46-C54 & 100n & \\
5 & C4, C5, C6, C7, C36 & 470n & \\
2 & C1, C28 & 1u & \\
3 & C15, C16, C42 & 10u & \\
3 & C2, C14, C19 & 100u & \\
8 & L1, L3, L4, L5, L6, L7, L8, L9 & 100u & \\
1 & T1 & 3 x 8 @ FT37-43 & \\
1 & D1 & 1N4148 & \\
4 & in parallel to C1-C4 & 5.1V Zener & \\
1 & Q1 & BS170 & \\
1 & Q2 & 2N3904 & \\
1 & U1 & FST3253 & \\
5 & U3, U5, U6, U7, U8 & LM833 & \\
1 & U4 & LM386 & \\ 
6 & -- & DIP-8 Sockets & \\
1 & U9 & 74AC74 & \\
1 & U10 & L7805 & \\
1 & U11 & ATmega328-PU & \\
1 & --  & DIP-28 Socket & \\
1 & - & SI5351 break-out & \\
2 & J1, J3, J4, J11 & 1x10 pin-header long & \\
1 & J6 & 2x3 pin-header & \\
1 & J9 & 1x7 pin-socket & \\
2 & J2, J7 & 1x2 90deg & \\
1 & -- & Switch & \\
1 & J8 & 1x3 90deg & \\
1 & -- & 10k log & potentiometer \\
1 & J10 & 1x4 90deg & \\
1 & -- & Rotary encoder & \\
1 & LCD1 & 1x8 90deg & \\
1 & -- & LCD & 2 x 8 symbols \\
1 & J13 & TX-OC & RCA-jack (optional) \\
1 & J5 & Key & 3.5mm stereo jack\\ \hline
\end{longtable}

\cleardoublepage
\section{PA \& Low-Pass Board} \label{sec:pa}
The majority of the PA/LP board consists of four 7-pole Chebyshev low-pass filters. The Chebyshev-type filters are needed to get away with only four filters to cover all RF bands from 80m to 10m. The right-most filter covers the 80m and 60m band and should have a cutoff frequency near $5.6\,MHz$. The next filter covers 40m and 30m and should have a cutoff frequency near $10.5\,MHz$. The second-to-last filter covers 20m and 17m and should have a cutoff frequency near $20\,MHz$. Finally the leftmost filter will cover 15m, 12m and 10m with a cutoff frequency near $30\,MHz$. The low-pass filters are switched by 4 sub-miniature relays controlled by the RX-board via the board-to-board (b2b) connector \texttt{J2}.

The \texttt{Q4} mosfet acts as the TX/RX switch passing the LP-filtered RF from the input to the RX via b2b \texttt{J6}.

The PA section consist of a \texttt{74HCT00} as driver, four \texttt{BS170} mosfets as PA transistors and a \texttt{BD140-16} for key-shaping. The TX oscillator signal arrives from the RX-board via b2b \texttt{J7}.

The complete TRX is powered from the barrel-jack \texttt{J3} and the supply voltage is passed to the RX-board via b2b \texttt{J11}. 

\begin{remark}
 Before assembling the low-pass filers on the board. Please assemble them ugly-style on a piece of PCB material and measure their properties using a network analyzer or spectrum analyzer. Being Chebyshev low-pass filter, the exact component values are critical!
\end{remark}

 If no measurement equipment is present. Please subtract one winding from the given values below. The number of turns for each core was determined using AL-values provided by the manufacturer. In my experience, this leads to an slightly overestimation of the number of turns by about one. Moreover, you are probably more willing to risk a lower stop-band suppression rather than an increased damping in the pass band.

\begin{remark}
 Like for the RX board, the PA board has its own \href{https://dm3mat.darc.de/cw2019/pa_rev2_ibom.html}{interactive BOM}.
\end{remark}

 The diode \texttt{D4} is connected in parallel to the barrel-jack and acts together with a fuse as a reverse-polarity protection. If the supply is connected to the TRX in reverse-polarity, the diode will short the input which will cause a huge current that blows the fuse. A 2A \emph{flink} fuse will do.
 
 Finally install the b2b \textbf{sockets} on the PA/LP board, that is \texttt{J2}, \texttt{J6}, \texttt{J7} and \texttt{J11}.
 
\clearpage
\subsection{PA/LP Component List}  \label{sec:pacomp}
\begin{longtable}{|l|p{6cm}|l|l|} \hline 
\# & Component & Value & Remarks \\ \hline 
2 & R12, R13 & 100 & \\
1 & R9 & 470R & \\
1 & R10 & 1k & \\
1 & R14 & 4.7k & \\
7 & R1, R3, R5, R7, R11, R15, R16 & 10k & \\
4 & R2, R4, R6, R8 & 100k & \\
2 & C2, C15 & 100p & NP0 \\
4 & C3, C6, C11, C16 & 220p & NP0 \\
4 & C4, C7, C12, C17 & 470p & NP0 \\
2 & C5, C18 & 820p & NP0 \\
2 & C8, C13 & 1n & NP0 \\
2 & C9, C14 & 1.5n & NP0 \\
11 & C1, C10, C19, C20, C22, C23, C24, C27, C28, C29, C30 & 100n & \\
1 & C25 & 1u & \\
1 & C26 & 220u & \\
1 & L14 & 22u & 07HCP \\
1 & L13 & 100u & MICC \\
3 & L1, L5, L9 & 330n & 11T on T37-6 \\
3 & L2, L6, L10 & 480n & 13T on T37-6 \\
3 & L3, L7, L11 & 750n & 14T on T37-2 \\
3 & L4, L8, L12 & 1700n & 21T on T37-2 \\
1 & T1 & -- & 8T + 8T on FT37-43 \\
4 & K1, K2, K3, K4 & G6S-2 & \\
6 & D1, D2, D3, D5, D6, D7 & 1N4148 & \\
1 & D4 & 1N4001 & \\	
4 & Q1, Q2, Q3, Q10 & 2N3904 & \\
6 & Q4, Q6, Q7, Q8, Q9, Q11 & BS170 & \\
1 & Q5 & 2SB 772 & \\
1 & U1 & 74HCT00 & \\
1 & J1 & BNC & \\
1 & J2 & 1 x 8 pin-socket & \\
1 & J3 & barrel-jack & \\
3 & J6, J7, J11 & 1 x 2 pin-socket & \\ \hline
\end{longtable}

\cleardoublepage
\section{Final Assembly} \label{sec:box}
Finally, the board-to-board interconnects are installed. The way these connectors are installed, depends on the chassis and distance between the boards you chose. The example I give here applies to the Fischer \texttt{KOH-2100} + \texttt{KOH-4100} + \texttt{DPL 2-4} kit. This is a nice and compact $10 \times 10 \times 5\,cm$ chassis. The boards slide into the chassis with $\approx 1.5\,cm$ distance. Unfortunately, I was not able to find stackers or long pin-headers with a matching length here in Germany. Have a look at Ebay or at Mouser. Pin headers with insertion lengths of about $12\,mm$ should do the trick. I, however, went with stackers of $38\,mm$ total length which is is way too long and therefore needed to be shortened.

\begin{figure}[!ht]
 \centering
 \begin{subfigure}{0.49\linewidth} 
  
  \caption{Cut stackers to get long pin-headers, before inserting them into the socket of the PA board.} \label{fig:stackers}
 \end{subfigure} 
 \begin{subfigure}{0.49\linewidth} 
  
  \caption{Put RX board on top, insert into chassis, solder pins to RX board and cut pins to length.} \label{fig:final}
 \end{subfigure}
 \caption{Final assembly of the board-to-board interconnects.}
\end{figure}

The easiest way to do that, is to cut the top-part away from these stackers (see figure \ref{fig:stackers}) and stick them into the sockets on the PA board. Than put the RX board on top. Now carefully insert both boards in the chassis. Make sure that you can close the chassis. Finally solder the stackers/long pin-headers into the RX board. 

\begin{warning}
Do not overheat the stackers/pin-headers as the socket may melt. Just tag them in-place and reflow the header connections once the PA-board is removed.
\end{warning}

When the TRX is installed into the Fischer chassis mentioned above, the RCA connector at the back of the RX board to key an external PA will not fit. The boards are way to close together. If a different chassis is used, the connector can be installed right now.

\subsection{Final Testing}
With these final steps completed, it is now time to test the PA and RX/TX switching. Reconnect everything and connect a dummy-load to the output. Measure the RF voltage-drop across the dummy-load (oscilloscope). Alternatively, connect a power/SWR meter between the TRX and dummy-load. You should get about $22\,Vp$ across the dummy-load or about $5\,W$ on transmit, depending on the supply voltage (assuming about $13.8\,V$). On the lower band (e.g., up to $30\,m$) it might even be a little bit more. 

If your output is way less, measure the peak voltages at the PA-output and LP-input and double-check the low-pass filters. If the output matches, the assembly is complete. 

\subsection{Hot fixes}
The second revision was a redesign to some extend. Hence not everything is perfect yet. For example, the \texttt{74AC74} produces a lot of high-frequency ripple on the 5V rail. To suppress them stronger, a $470\,pF$ capacitor should be soldered directly from pin 16 (5V) to pin 8 (GND).  

The audio PA has a tendency to oscillate, in particular if a small speaker is used. If it does so, it may drive the complete audio-chain into saturation. In this case, the audio-chain may feed-back $12\,V$ to the FST3253 mixer. This destroys the hard-to-get mixer! To prevent this problem, you \textbf{should} install four 5.1V Zener-diodes in parallel to C4-C7 on the receiver board. This limits the voltage that can be fed back to the mixer and saves it. 

\subsection{Mechanical Parts}
\begin{longtable}{|l|p{6cm}|l|l|} \hline 
\# & Component & Remarks \\ \hline 
1 & chassis top & \\
1 & chassis bottom & \\
1 & chassis front/back & \\
1 & 10k log pot & \\
1 & rotary encoder & \\
1 & LCD display & \\
1 & head-phone socket & \\
1 & switch & \\
1 & barrel plug & \\
2 & fuse holder & optional \\
2 & 2A flink & optional \\
1 & speaker & optional \\ \hline
\end{longtable}

\cleardoublepage 
\section{Build \& Load the Firmware} \label{sec:fw}
To program the firmware onto the device in the first place or update the firmware to a newer version, a so-called in-system programmer ISP is needed. This is a small USB device that provides the interface from the computer to the controller (MCU). There are many cheap AVR ISPs out there (usually between 5\EUR and 10\EUR on ebay). It is also possible to build a \href{http://www.lancos.com/siprogsch.html}{makeshift ISP for the good old serial-port} or using a \href{https://www.arduino.cc/en/Tutorial/BuiltInExamples/ArduinoISP}{Arduino as ISP}. 

Once you got your hands on an ISP, you still need some software to upload the firmware to the device. I used \href{https://www.nongnu.org/avrdude/}{avrdude} under Linux for this but others should work as well. If you got a working setup, you can simply \href{https://github.com/hmatuschek/cwtrx/releases}{download} the pre-compiled firmware and EEPROM image from my github page and program the device immediately. You only need to set the fuses of the AtMega first to low=\texttt{0xE2} and high=\texttt{0xD9}. These fuse settings tells the MCU to use the internal 8Mhz RC-oscillator (no pins left for a crystal) and not to divide the clock by 8. All other settings are left as default. 

\begin{wrapfigure}{l}{0.2\linewidth}
  
\end{wrapfigure}
You can find the 6-pin ISP header (J3) on the RX board. Pin 1 is marked by a small circle on the corner. Consequently the small tab on the ISP plug must face away from the MCU. 

When programming the MCU, you need to first set the fuses. This step must only be done once as these settings are conserved across programming cycles. In a second step the firmware (\texttt{firmware-atmega328p.hex}) is written to the MCU. This step usually erases the EEPROM content. The EEPROM is used to store settings, last frequency etc. The firmware may not properly work with some uninitialized EEPROM. Hence, after the firmware was written, the default EEPROM image (\texttt{firmware-atmega328p-eeprom.hex}) must be written to the MCU.

\subsection{Building Firmware from Scratch}
In this section, I like to describe building and loading the firmware from scratch on a Ubuntu/Debian system (e.g., on a Raspberry Pi). Before you can start a bunch of software needs to be installed. That is the cross compiler, build tools and programming software. So run on a command line
\begin{lstlisting}[language=bash]
sudo apt-get install git cmake gcc-avr avrdude
\end{lstlisting}

\texttt{git} is the version control system I use. It is used to download the latest source code. \texttt{cmake} is the build system. There is a nice extension to cmake for the avr-gcc and avrdude that makes building and writing the firmware to the MCU easy. \texttt{gcc-avr} is the cross-compiler for the AVR devices. Finally, \texttt{avrdude} is the programming tool to write the firmware to the device.

Once all the software is installed, you need to download the firmware source from my github page. So call
\begin{lstlisting}[language=bash]
git clone https://github.com/hmatuschek/cwtrx.git
\end{lstlisting}
You will now find a new directory named \texttt{cwtrx}. Before the firmware can be programmed to the device, you may need to adjust some settings to reflect your programmer. The first lines in the \texttt{cwtrx/\-firmware/\-CMakeLists.txt} specify which programmer you use and where to find it. 

By default you should find something like this
\lstinputlisting[linerange={1-4}, numbers=left]{../firmware/CMakeLists.txt}
In the second line, you can set the programming tool. Here avrdude is used. The third line specifies the ISP programmer being used. Here I used a STK500V2 compatible one (actually called DIAMEX-AVR). Finally, line 4 specifies the port where the programmer can be found. This programmer appears as a serial port to the computer (as device \texttt{/dev/ttyACM0}). You may need to change lines 3 and 4 to match your local setup.

Once everything is set up, you can start to build the firmware. Enter the \texttt{cwtrx} directory, create a so-called build directory and enter it as well. 
\begin{lstlisting}[language=bash]
cd cwtrx
mkdir build
cd build
\end{lstlisting}

In the next step, the build will be configured with
\begin{lstlisting}[language=bash]
cmake ..
\end{lstlisting}
This step will search for the AVR GCC and prepare the build. Once completed, build the firmware and EEPROM image with
\begin{lstlisting}[language=bash]
make
\end{lstlisting}

After this step, you need to set the fuses of the MCU. Simply call
\begin{lstlisting}[language=bash]
make set_fuses
\end{lstlisting}
This step may fail if the MCU is brand new. Just retry several times. Once the fuses are set, the communication with the MCU should be stable. Then upload the firmware to the MCU with
\begin{lstlisting}[language=bash]
make upload_firmware
\end{lstlisting}
and finally write the EEPROM image with 
\begin{lstlisting}[language=bash]
make upload_eeprom
\end{lstlisting}

Your TRX is now ready.

\subsection{Updating the Firmware}
Assuming you already performed the steps above, updating the firmware is quiet straight forward. Enter the \texttt{cwtrx} directory and run
\begin{lstlisting}[language=bash]
git pull
cd build
make 
make upload_firmware
make upload_eeprom
\end{lstlisting}
And you are ready to go.

\cleardoublepage
\section{Usage} \label{sec:user}
Handling a feature-rich TRX using a single rotary encoder with a single push-button is kind of challenging. I've designed a two-level menu navigation that puts everything that is needed frequently in the first level (blue in figure \ref{fig:menu}) and everything else in a second level. This keeps the navigation fast for frequently used options. 

The second menu level (red in figure \ref{fig:menu}) contains all settings that are usually not touched during the operation. They concern the basic setup and alignment of the TRX. 

\begin{figure}[!ht]
 \centering
 \footnotesize
 \begin{tikzpicture}[node distance=2.3cm,
	>={Latex[width=2mm,length=2mm]},
    menu/.style = {rectangle, rounded corners, draw=black,
                   minimum width=1.5cm, minimum height=1cm,
                   text centered, font=\sffamily, fill=blue!30},
    submenu/.style = {menu, fill=red!30}]
  \node (rit) [menu] {RIT};   
  \node (speed) [menu, right of=rit] {CW Speed}; 
  \node (step) [menu, right of=speed]{Step size};
  \node (vfo) [menu, right of=step] {VFO};
  \node (band) [menu, right of=vfo] {Band};
  \node (setup) [menu, right of=band] {Setup};
  
  \node (quick) [submenu, below of=setup] {Qick-set};
  \node (type) [submenu, left of=quick] {CW key};
  \node (rev) [submenu, left of=type] {Pad.rev};
  \node (mode) [submenu, left of=rev] {Iambic}; 
  \node (tone) [submenu, left of=mode] {CW Tone}; 
  \node (level) [submenu, left of=tone] {CW Level}; 
  \node (text) [submenu, left of=level] {CW Text}; 
  \node (clr) [submenu, below of=text] {Clr. CWT};
  \node (meter) [submenu, below of=clr] {Meter};
  \node (hold) [submenu, right of=meter] {TX Hold}; 
  \node (greet) [submenu, right of=hold] {Greet};
  \node (enc) [submenu, right of=greet] {Enc.Type};
  \node (version) [submenu, right of=enc] {Version};
  \node (sideband) [submenu, right of=version] {USB/LSB};
  \node (pll) [submenu, right of=sideband] {PLL Cor.};
  \node (reset) [submenu, above of=pll] {Reset};

  \path[->,thick]
    (rit) edge (speed)
    (speed) edge (step)
	(step) edge (vfo)
	(vfo) edge (band)
	(band) edge (setup)
	(setup) edge[bend right] (rit);
	
  \path[->,thick,dashed]
    (setup) edge (quick);
  \path[->,thick]
        (quick) edge (type)
        (type) edge (rev)
        (rev) edge (mode)
    	(mode) edge (tone)
    	(tone) edge (level) 
    	(level) edge (text)
    	(text) edge (clr)
    	(clr) edge (meter) 
    	(meter) edge (hold)
    	(hold) edge (greet) 
    	(greet) edge (enc)
    	(enc) edge (version)
    	(version) edge (sideband)
    	(sideband) edge (pll)
    	(pll) edge (reset) 
    	(reset) edge (quick);
 \end{tikzpicture}
 \caption{Menu navigation} \label{fig:menu}
\end{figure}

To enter the menu, just click the button on the rotary encoder. You will land on either the RIT setting or on the last modified setting. Using the rotary-encoder you can navigate through the first menu level. To change a settings, click the center button again. You can now change the selected setting using the rotary encoder. To finish the setting and leave the menu, click the center button again.

To enter the second menu-level, enter the first level by clicking on the center button and select the menu entry \texttt{Setup}. Click on the center button again to enter the second-level menu. You will land on the \texttt{Quick-set} setting. You may now navigate the second menu-level using the rotary encoder. Changing and leaving the second-level menu works in the same way as the first-level menu. 

\subsection{Gestures}
The firmware distinguishes four different \emph{gestures} of the rotary encoder:
\begin{enumerate}
 \item \emph{tune} - just rotate the encoder.
 \item \emph{click} - press and release the center button of the encoder.
 \item \emph{long-press} - press and hold the center button for at least 2 seconds.
 \item \emph{press-rotate} - press and rotate the encoder.
\end{enumerate}

During RX, a \emph{tune} gesture will simply tune the frequency (of cause), a \emph{click} gesture will enter the menu, a \emph{long-press} gesture will send the keyer memory (if set) and a \emph{press-rotate} gesture will quick-set a property (if specified).

\subsection{Settings}
The \emph{settings} are all settings that might be changed during normal operation of the TRX. Hence they are located at the first level of the menu for the sake of quick access.
 
\paragraph{Receive/Transmit offset (RIT)}
Allows to fine-tune the RX frequency while keeping the TX frequency constant. A non-zero RIT will be indicated by a \texttt{+} or \texttt{-} symbol in the bottom-right corner of the display during RX. 

\paragraph{CW speed}
Specifies the speed in WPM for the iambic and automatic keyer.

\paragraph{Tuning step-size}
Specifies the step-size when tuning the TRX.

\paragraph{VFO}
Specifies the current VFO and VFO-mode. That is \texttt{VFO A}, \texttt{VFO B} or \texttt{Split}.

\paragraph{Band}
Specifies the current band. 

\subsection{Quick-Set}
The \emph{quick-set} feature allows you to modify a selected setting without entering the menu at all. Just press \& rotate the  encoder.

To use this feature, you have to specify the settings you want to \emph{quick-set} under \texttt{Menu} $\rightarrow$ \texttt{Setup} $\rightarrow$ \texttt{QuickSet} (see below).

\subsection{Setup}
\emph{Setup} hides all settings that are usually not touched during regular operation and are therefore hidden in the second menu-level. You can access these settings by selecting \texttt{Menu} $\rightarrow$ \texttt{Setup}.

\paragraph{Quick-set}
The quick-set feature allows to set a specific property without entering the menu. By holding and turning the rotary-encoder at the same time. This menu item allows to select one of four settings to be manipulated by the quick-set feature: RIT, keyer speed, tuning step-size, band or \emph{none}. The latter disables the quick-set feature (default).

\paragraph{Key type}
The key type specifies the type of keyer you use. Possible options are \emph{straight key}, \emph{paddle}and \emph{iambic}. The TRX switches automatically to \emph{straight key} if the TRX detects a mono-plug at startup.

\paragraph{Paddle reverse}
If enabled, the meaning of the two paddles are reversed. That is, the left paddle will produce a series of \emph{dahs} and the right one produces a series of \emph{dits}.

\paragraph{Iambic mode}
Specifies either \emph{iambic A} or \emph{iambic B} modes for the automatic keyer if the type is set to \emph{iambic}.

\paragraph{CW side-tone level}
Specifies the volume of the CW side-tone. This is a value between 1 and 255.

\paragraph{Keyer memory \texttt{CW Text}}
Specifies the text to be send automatically (e.g., a CQ call) when the rotary encoder is long-pressed. If no text is set, nothing will happen.

To edit the CW text head to \texttt{Menu} $\rightarrow$ \texttt{Setup} $\rightarrow$ \texttt{CW Text} and \emph{click} the encoder to enter the editor. You should see a cursor beneath the first character. You can use the encoder to select the character you want to edit. \emph{Click} again and the character should start to blink. You can now change the selected character. Once the desired character is found, \emph{click} again to set it. You are now back at the editor level and the next character is automatically selected. Once the text is edited, leave the editor by \emph{long-pressing} the encoder.

\paragraph{Clear keyer memory}
Simply clears the keyer memory.

\paragraph{Meter selection}
Selects a meter to display during RX. This can be \texttt{Volt} to display the supply voltage or \texttt{Temp} to display the core-temperature of the MCU.

\paragraph{TX-hold time}
Specifies the delay between TX and RX in $ms$. By default a value of $50\,ms$ is selected. This small value allows for quasi-QSK but is sufficiently long to avoid ugly clicks in the audio path when switching from TX to RX.
\begin{remark}
When operating a PA or in split mode, a longer delay should be chosen to allow the relays to switch properly.
\end{remark}

\paragraph{Greet text}
An editor that allows you to change the \emph{greeting} at startup. The editing is similar to the \emph{keyer memory} editor above.

\subsection{Alignment}
These settings can be found under the \emph{Setup} sub-menu and are usually only changed during the alignment of the TRX. 

\paragraph{CW side-tone frequency}
Specifies the CW side-tone frequency as well as the RX frequency shift. This frequency should be identical to the center frequency of the narrow CW audio filter.

\paragraph{Encoder type}
Specifies the encoder type used. There are two different generic encoder-types \texttt{A} \& \texttt{B}. If you ordered exactly the encoder listed in the BOM, you should have a type-A encoder (default). If you encounter problems with the encoder (e.g., double-steps) you may change this setting to type B. If you wired the encoder in the wrong way (wrong tuning direction) you may simply change this setting to \texttt{A~rev} or \texttt{B~rev}. 

\paragraph{PLL correction}
This setting specifies the PLL clock frequency correction in PPM. See \texttt{RX Alignment} above.

\paragraph{Factory reset}
The previous version of the TRX encountered some issues with the EEPROM memory, leading to corrupted settings which turn the TRX unusable. This option allows to reset the entire EEPROM memory to \emph{factory settings} fixing the corrupted memory issue.

\cleardoublepage
\section{Bill-of-Material (BOM)}
\input{bom.tex}

\subsection{Shave off some \euro\ from the BOM}
The single most expensive item on the BOM is the chasis. You can certainly find some extruded aluminium chassis for less than \EUR{5} on Ebay. You can also get cheap clones of the Adafruit SI5351 break-out board for around \EUR{3}, cheap rotary encoders (\EUR{1}) and 2x8 LCD displays (\EUR{3}) there. I shoud announce a competition for the cheapest BOM for this TRX.

\cleardoublepage
\includepdf[pages={1,2,4,3,5,6},landscape=true, addtotoc={
 1, section, 1, RX Circuit, rxscm,
 2, subsection, 1, RX Mixer, rxmix,
 4, subsection, 1, Demodulator, rxdemod,
 3, subsection, 1, AF-Section, rxaudio,
 5, subsection, 1, PLL, rxpll,
 6, subsection, 1, Controller, rxctrl}]{fig/rx_scm.pdf}
\includepdf[pages={1,2,3},landscape=true, addtotoc={
 1, section, 1, RX Board, rxbrdtop,
 2, subsection, 1, Bottom, rxbrdbottom,
 3, subsection, 1, Silkscreen, rxbrdsilk}]{fig/rx_brd.pdf}
\includepdf[landscape=true, addtotoc={
 1, subsection, 1, Component Placement \& Values, rxval}]{fig/rx_values.pdf}
\includepdf[landscape=true, addtotoc={
 1, section, 1, PA/LP Circuit, pascm}]{fig/pa_scm.pdf}
\includepdf[pages={1,2,3},landscape=true, addtotoc={
 1, section, 1, PA/LP Board, pabrdtop,
 2, subsection, 1, Bottom, pabrdbottom,
 3, subsection, 1, Silkscreen, pabrdsilk}]{fig/pa_brd.pdf}
\includepdf[landscape=true, addtotoc={
 1, subsection, 1, Component Placement \& Values, pacomp}]{fig/pa_values.pdf}
\includepdf[landscape=true, addtotoc={
 1, section, 1, Drill Plan, drillfront}]{fig/drill_front.pdf}
\includepdf[landscape=true]{fig/drill_back.pdf}
\end{document}

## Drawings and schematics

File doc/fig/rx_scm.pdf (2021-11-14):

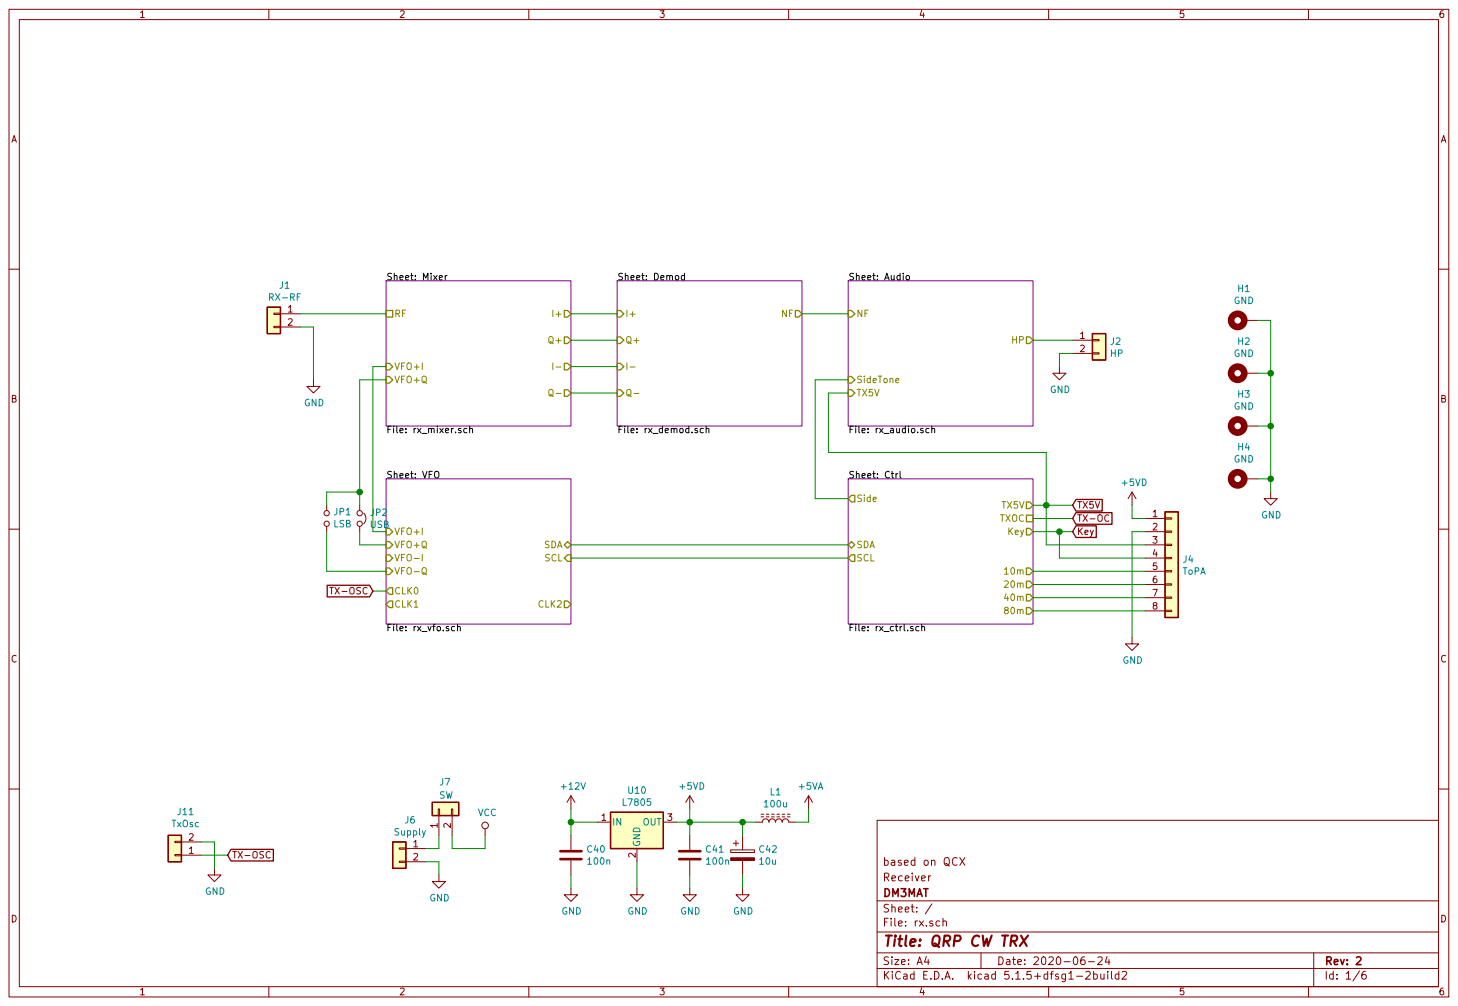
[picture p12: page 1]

Sheet: Ctrl File: rx_ctrl.sch SDA

JP2 USB
File: rx_vfo.sch VFO+I VFO-I VFO+Q

File: rx.sch Sheet: / DM3MAT Receiver based on QCX

Id: 1/6 Title: QRP CW TRX

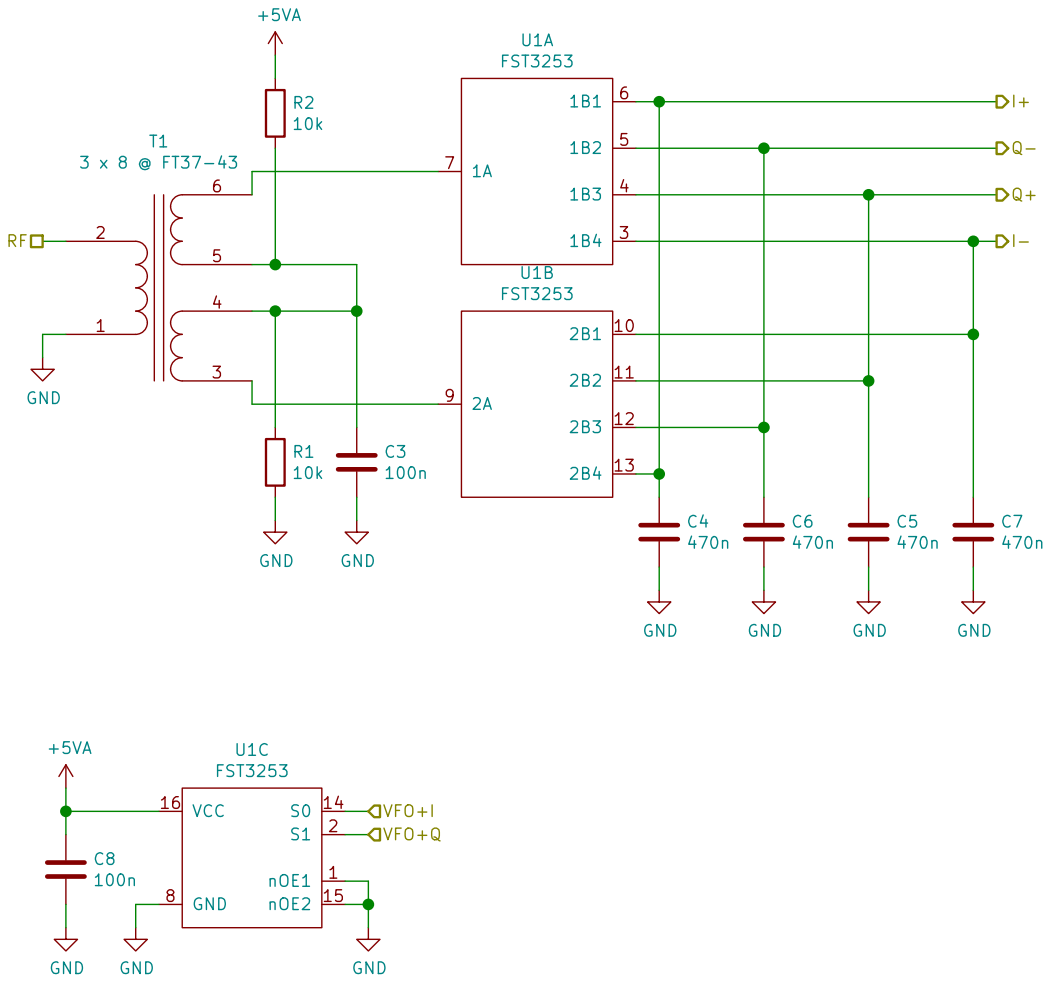
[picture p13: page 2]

File: rx_mixer.sch Sheet: /Mixer/ DM3MAT Mixer based on QCX

Id: 2/6 Title: QRP CW TRX

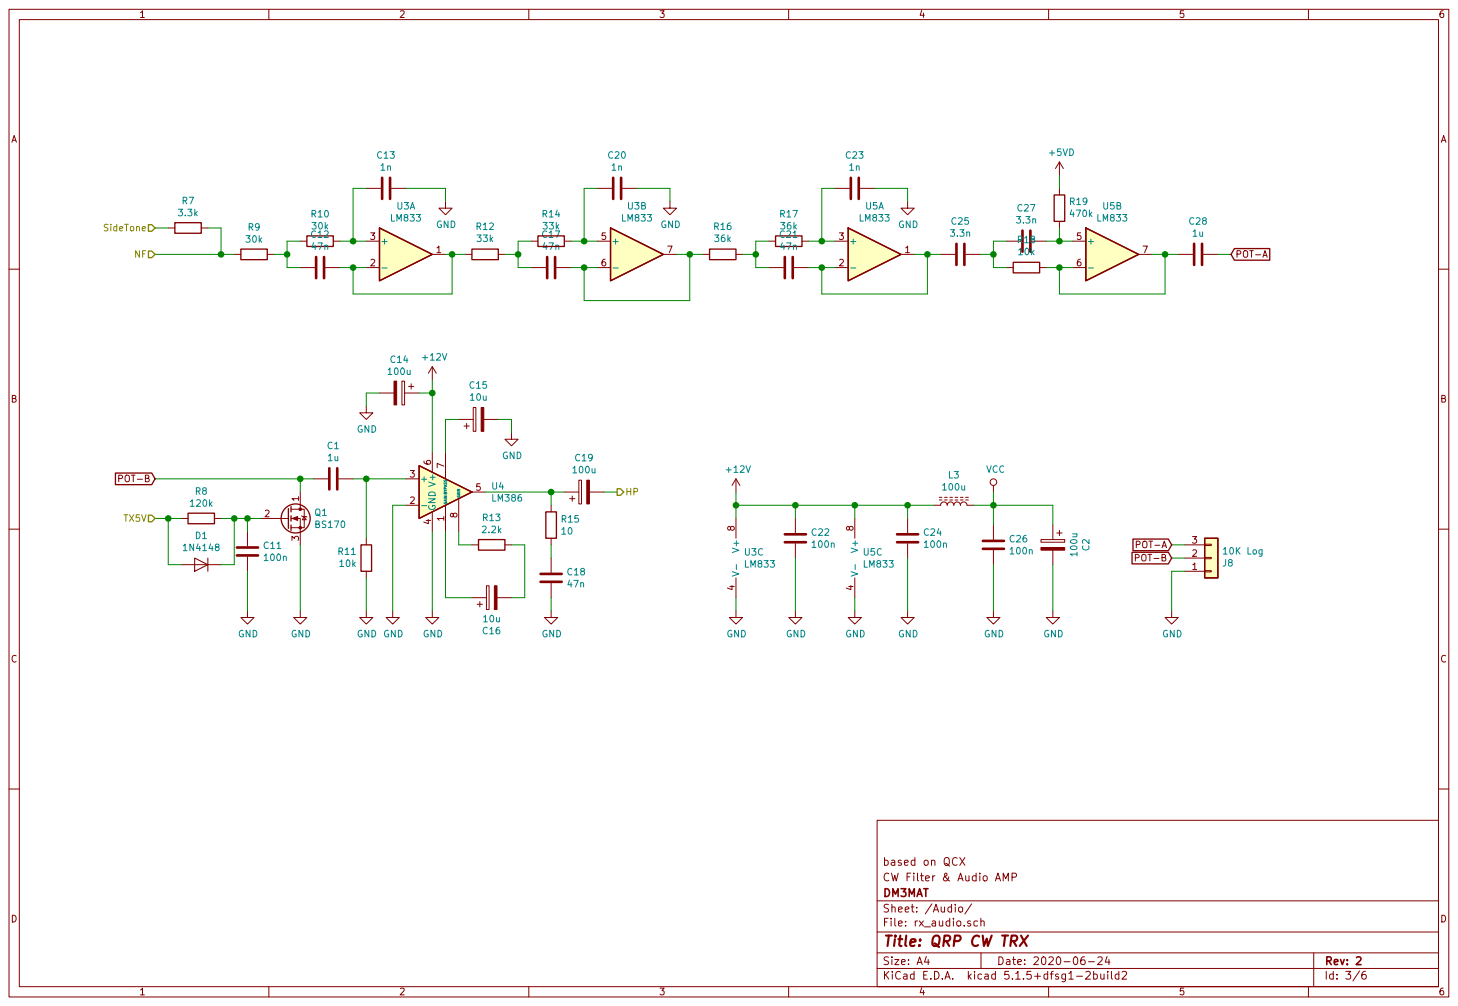
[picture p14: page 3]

based on QCX
File: rx_audio.sch Sheet: /Audio/ DM3MAT CW Filter & Audio AMP

Id: 3/6 Title: QRP CW TRX

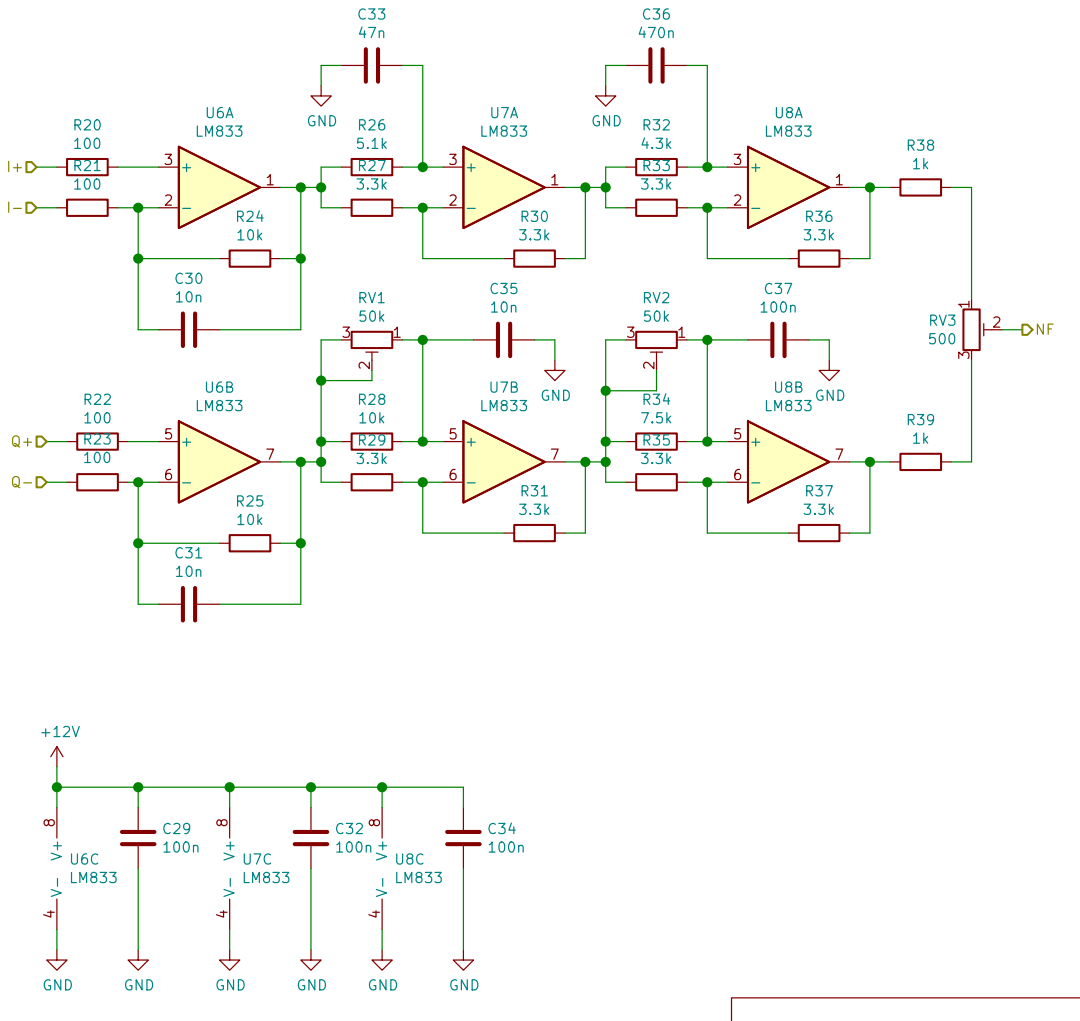
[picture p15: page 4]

File: rx_demod.sch Sheet: /Demod/ DM3MAT Demodulator based on QCX

Id: 4/6 Title: QRP CW TRX

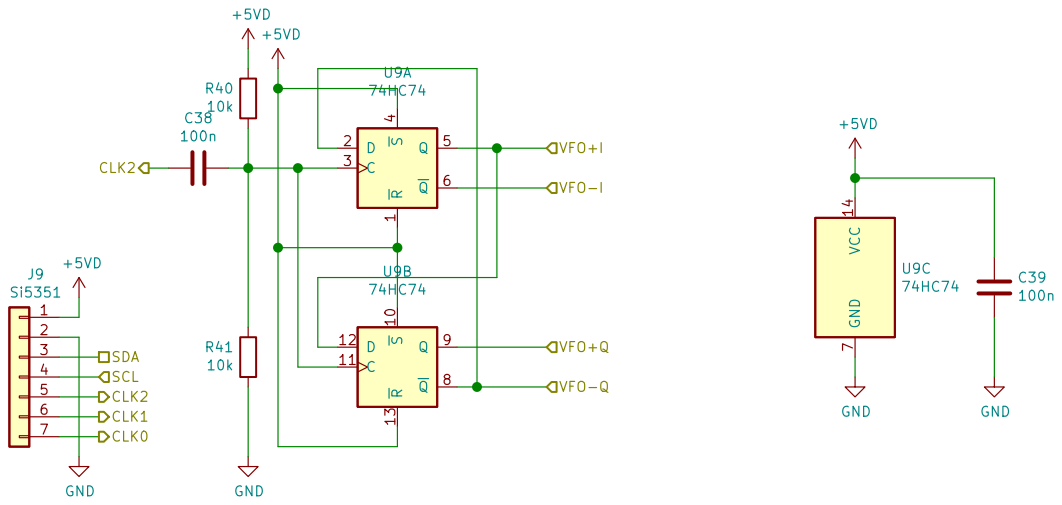
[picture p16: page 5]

based on QCX
File: rx_vfo.sch Sheet: /VFO/ DM3MAT PLL + I/Q gen

Id: 5/6 Title: QRP CW TRX

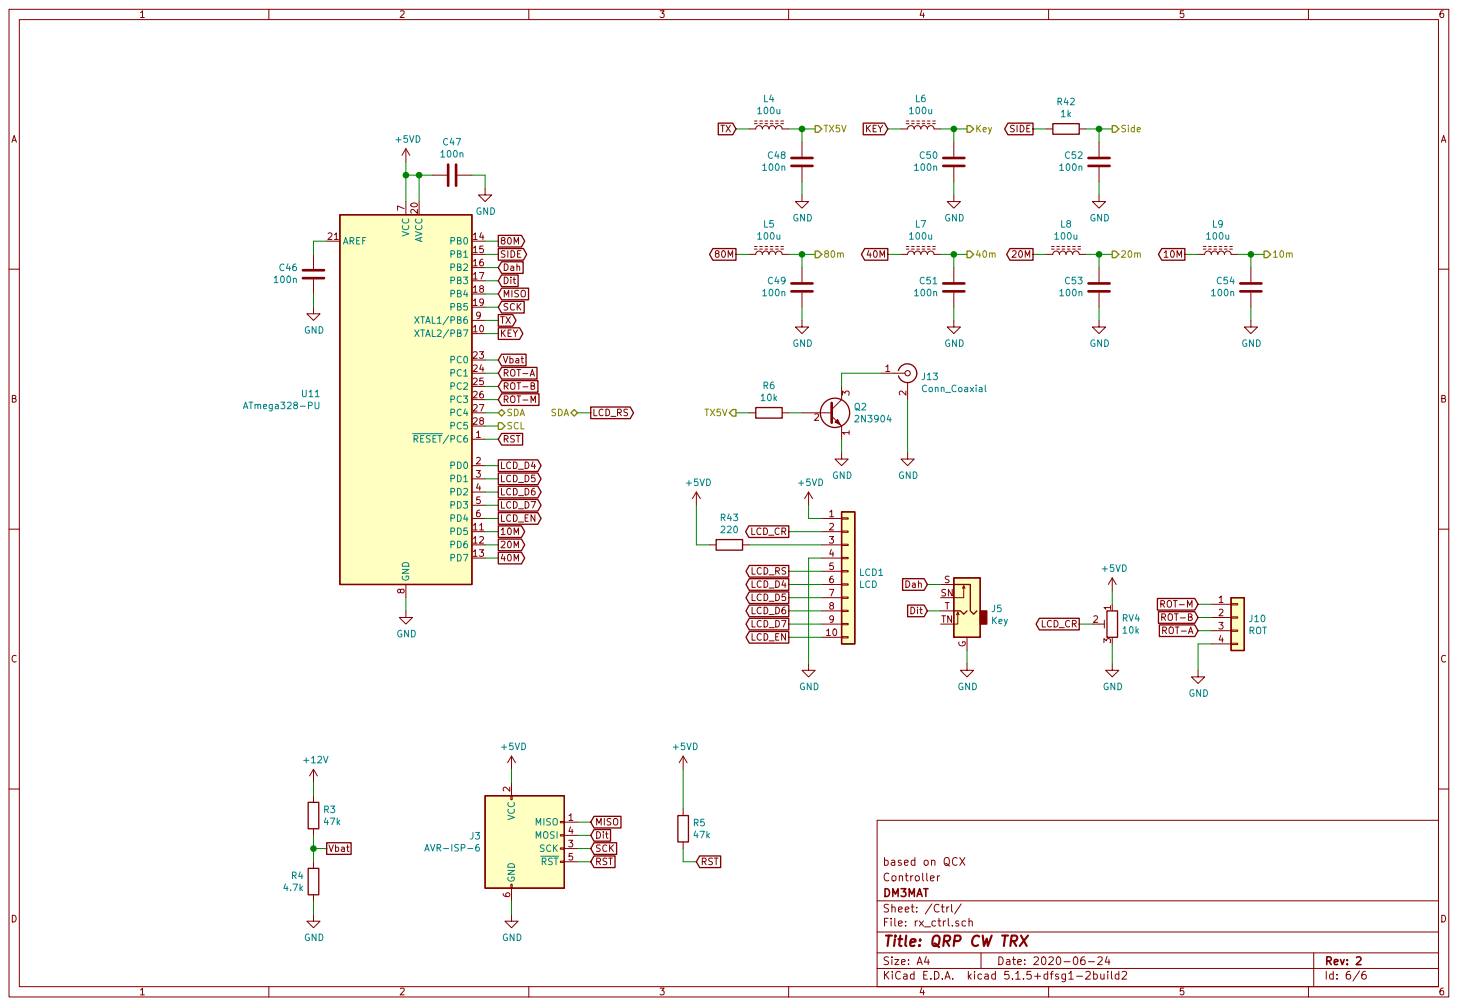
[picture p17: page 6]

File: rx_ctrl.sch Sheet: /Ctrl/ DM3MAT Controller based on QCX

Id: 6/6 Title: QRP CW TRX

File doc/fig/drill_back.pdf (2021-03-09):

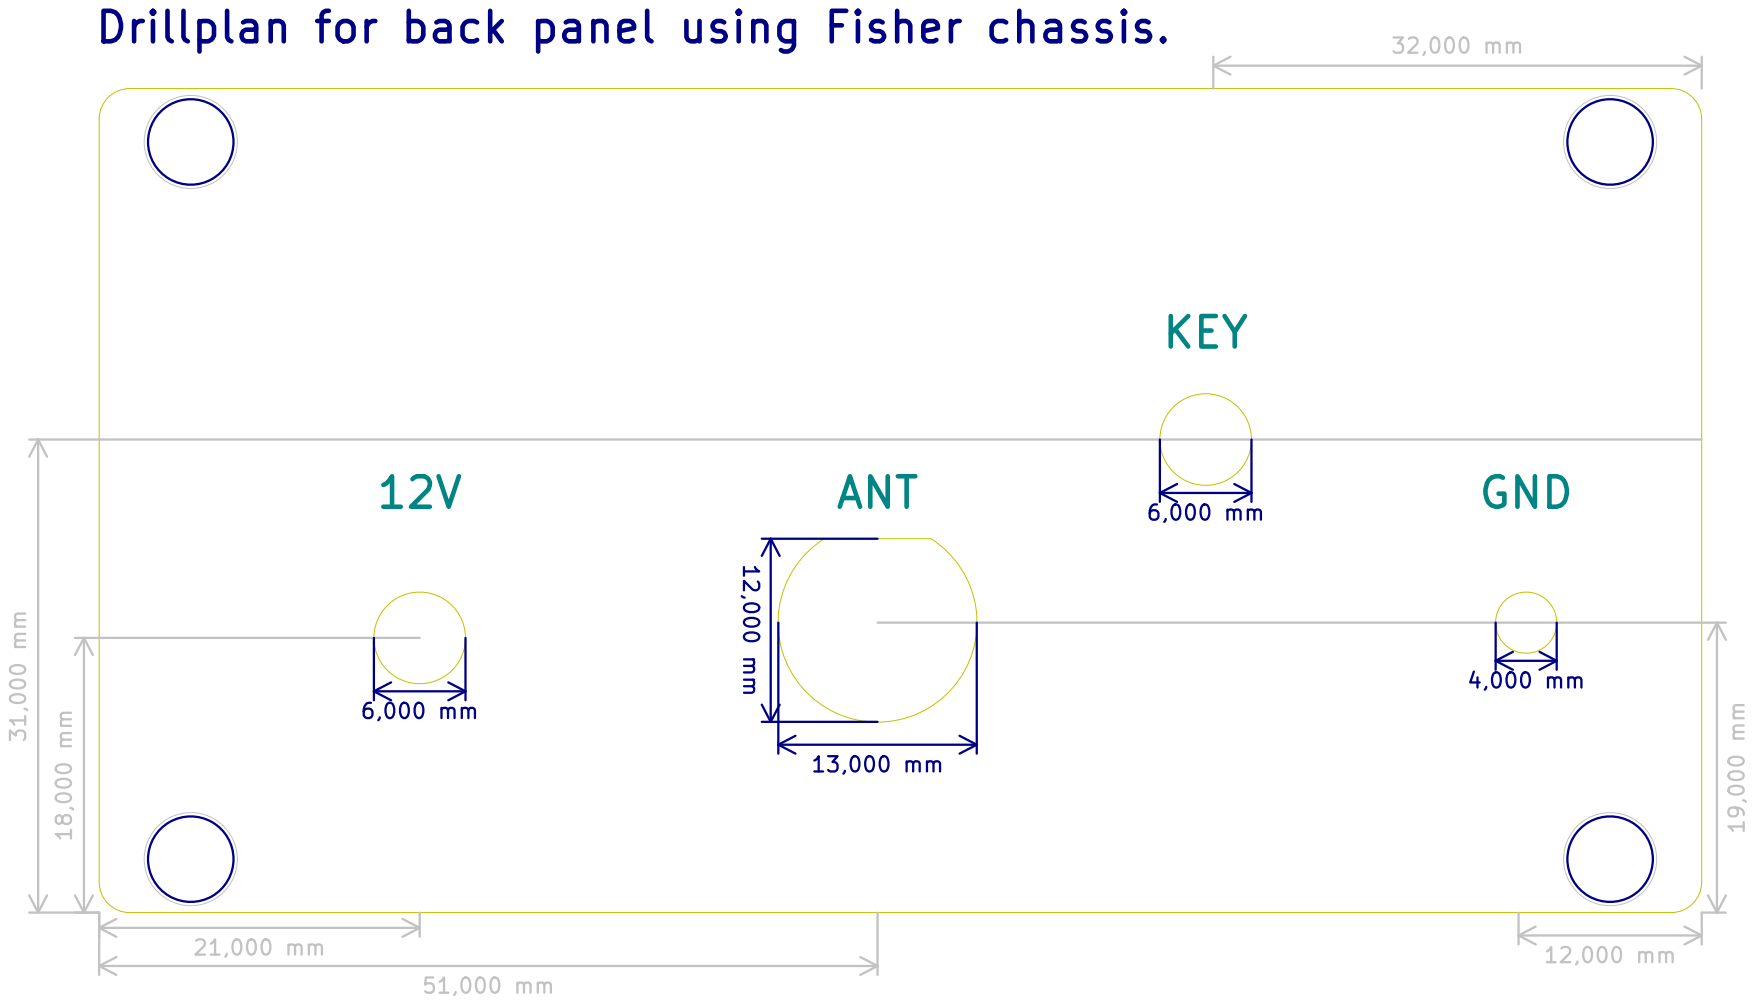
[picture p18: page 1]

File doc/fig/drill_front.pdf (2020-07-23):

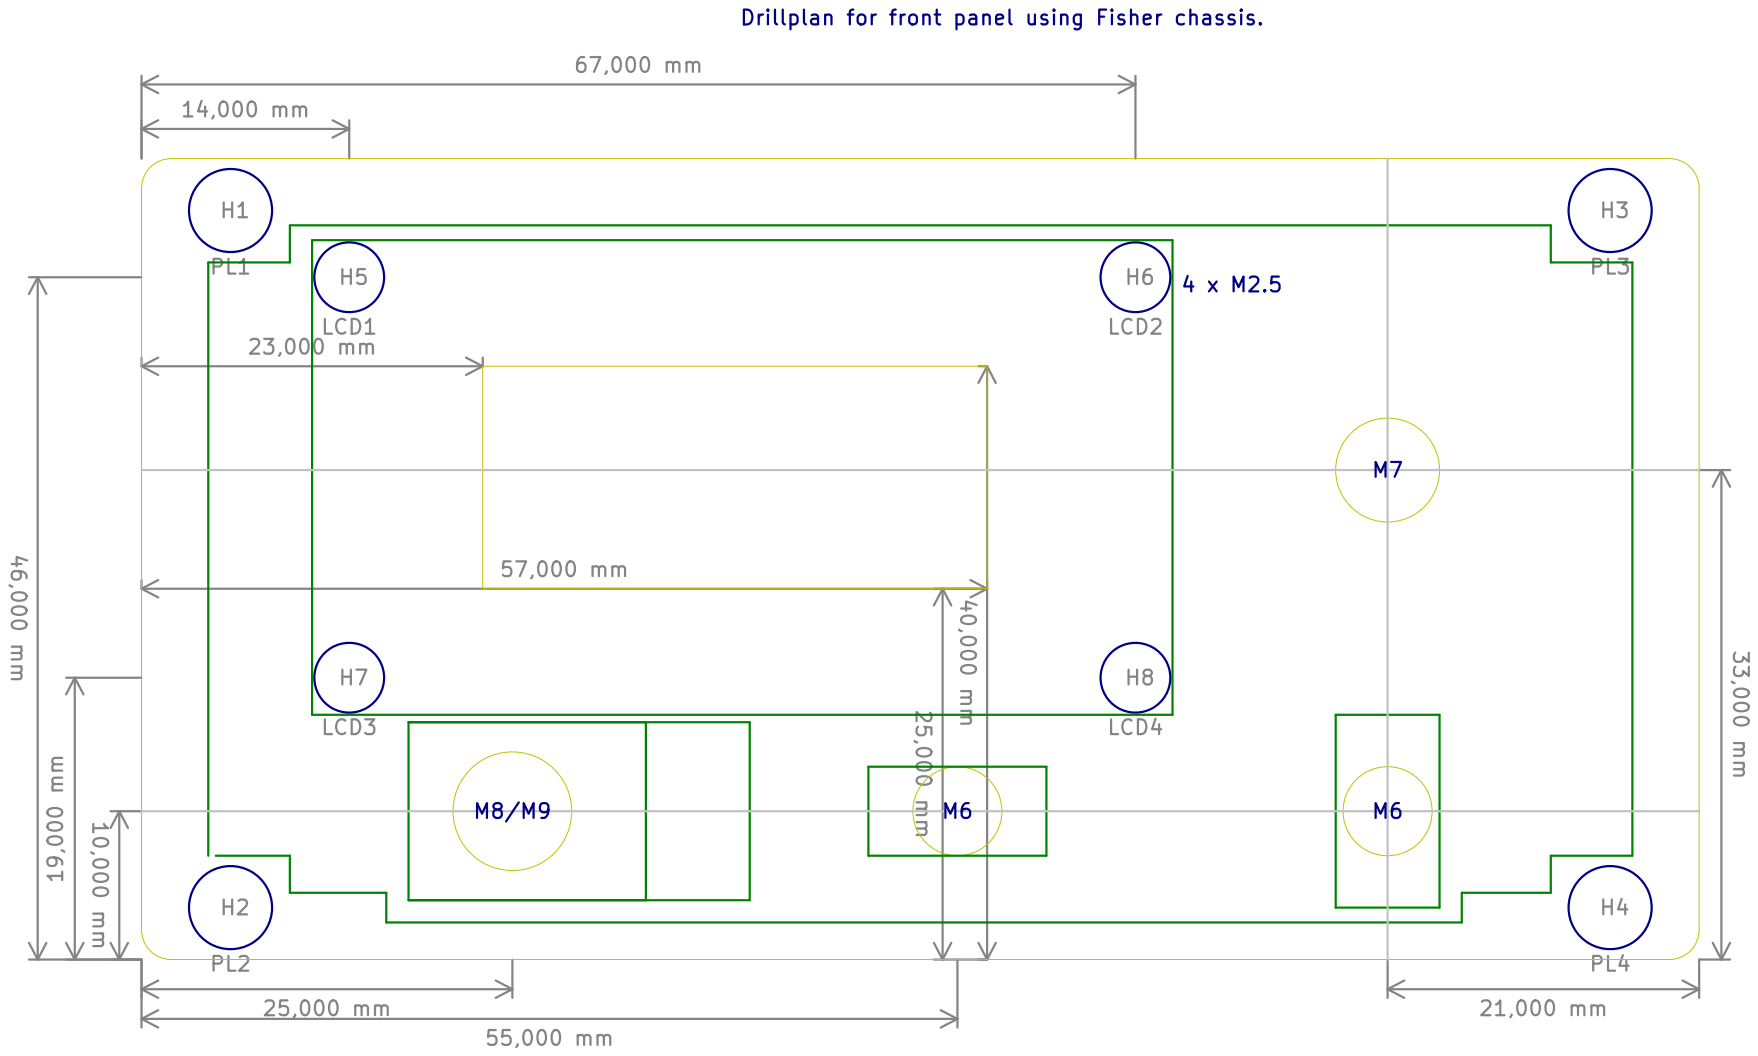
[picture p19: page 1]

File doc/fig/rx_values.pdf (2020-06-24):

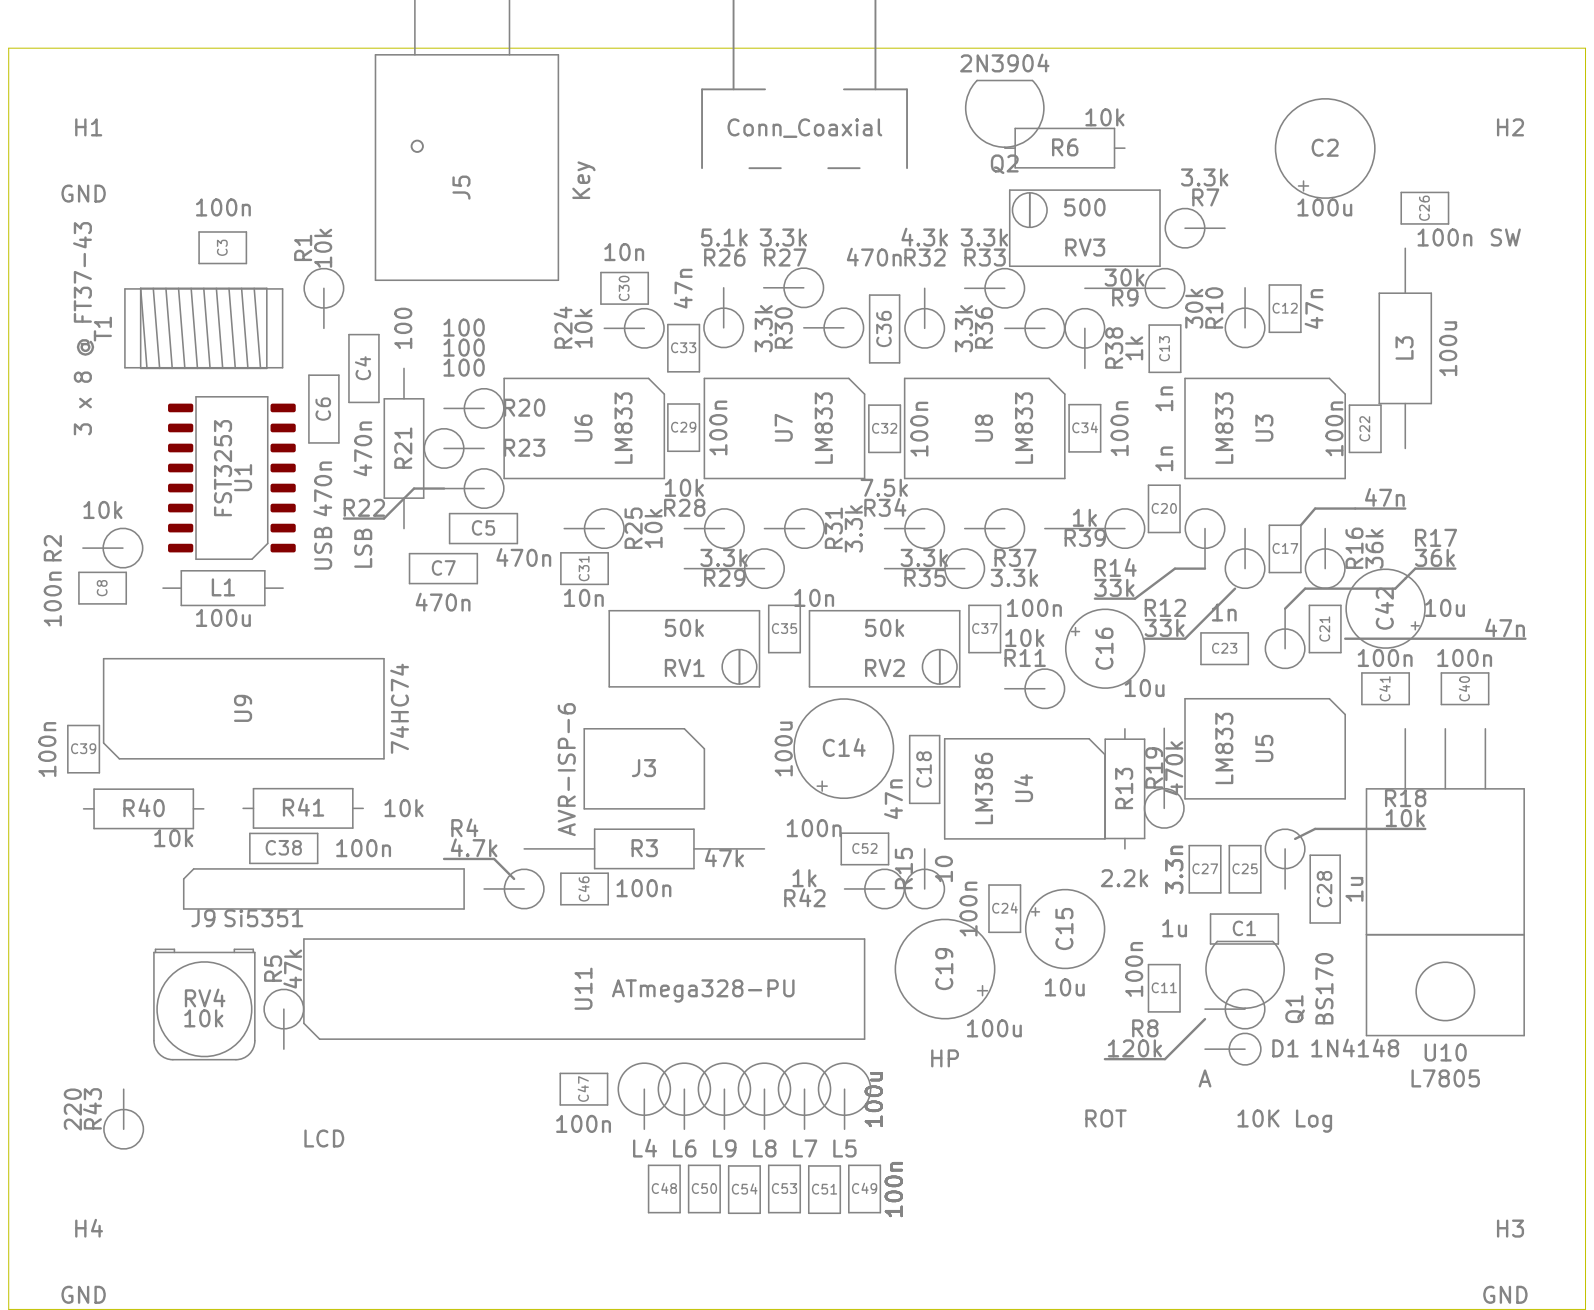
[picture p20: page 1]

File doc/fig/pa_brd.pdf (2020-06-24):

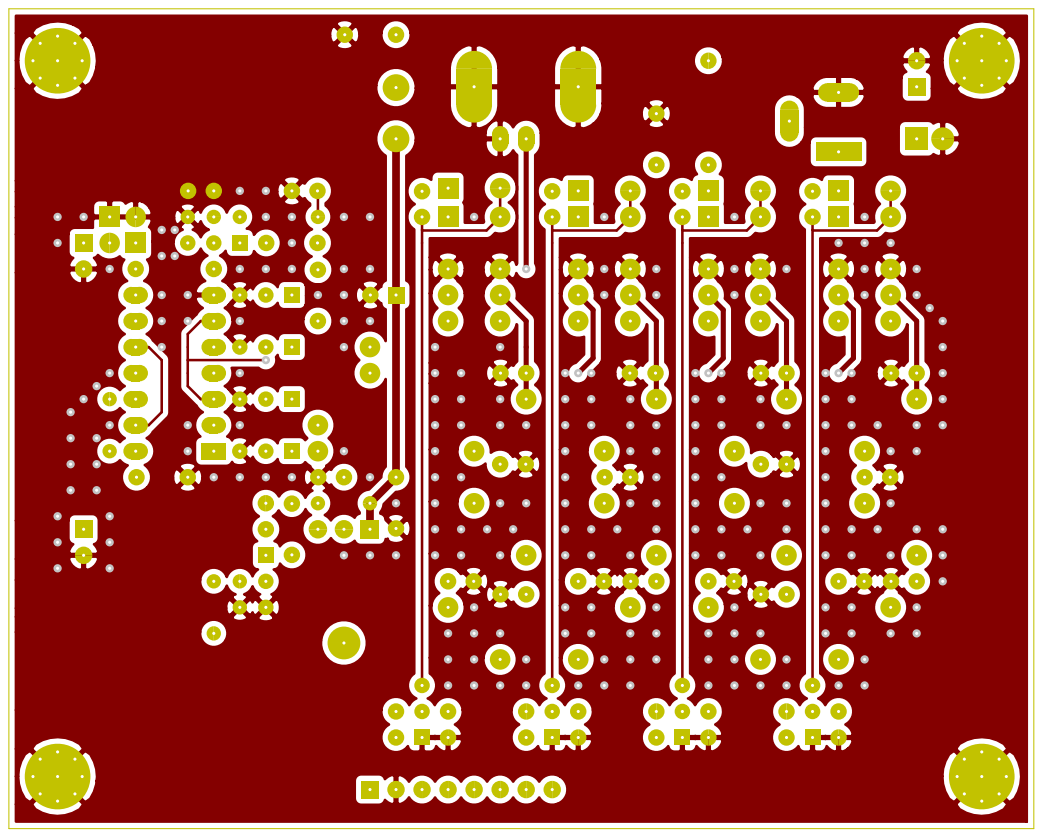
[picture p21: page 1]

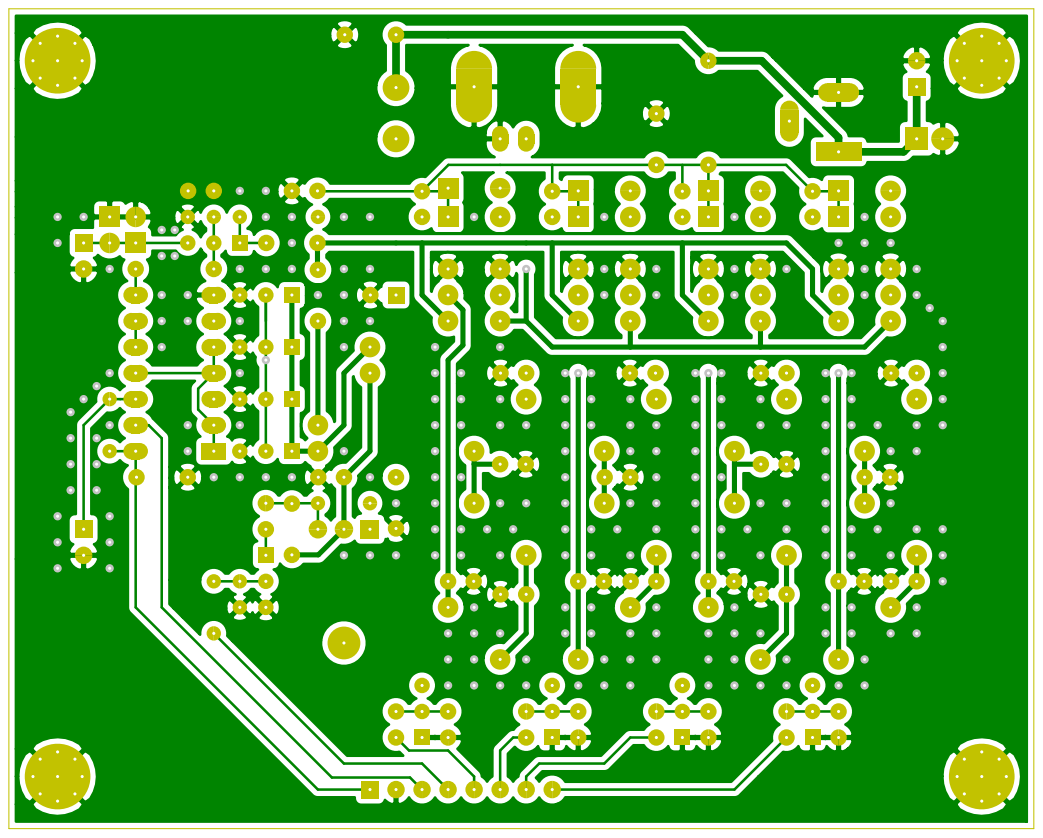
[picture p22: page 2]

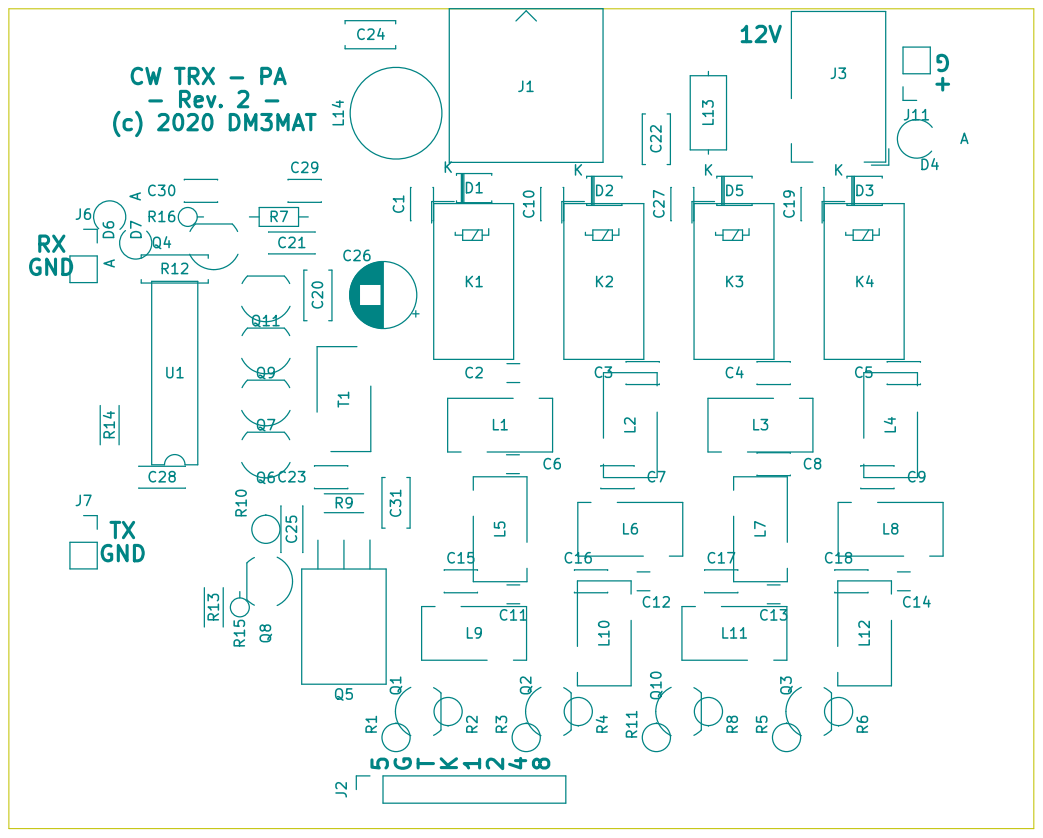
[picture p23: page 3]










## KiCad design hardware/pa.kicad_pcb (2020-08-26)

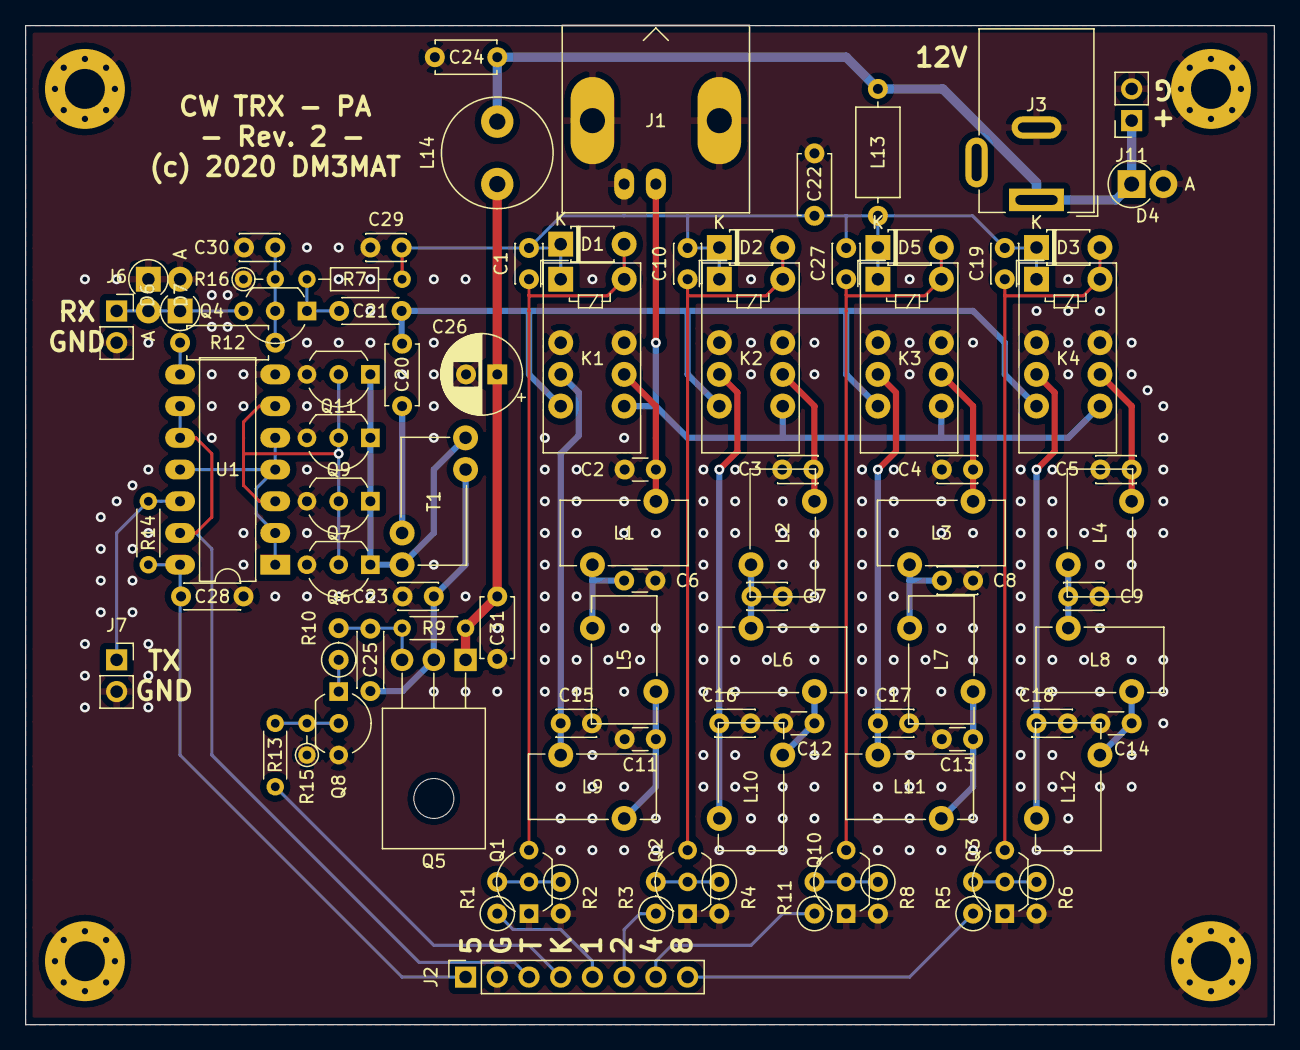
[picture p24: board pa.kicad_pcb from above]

Board: 2 copper layers, 100.0 x 80.0 mm, 95 parts (0 on the bottom side), 50 nets.

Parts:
C1, C10, C19, C23, C27, C29, C30: 100n; C_Disc_D3.0mm_W2.0mm_P2.50mm
C2: 100p; C_Disc_D3.0mm_W1.6mm_P2.50mm
C3, C16: 220p; C_Disc_D3.0mm_W2.0mm_P2.50mm
C4, C7, C17: 470p; C_Disc_D3.0mm_W2.0mm_P2.50mm
C5, C18: 820p; C_Disc_D3.0mm_W2.0mm_P2.50mm
C6, C11: 220p; C_Disc_D3.0mm_W1.6mm_P2.50mm
C8: 1n; C_Disc_D3.0mm_W2.0mm_P2.50mm
C9: 1.5n; C_Disc_D3.0mm_W2.0mm_P2.50mm
C12: 470p; C_Disc_D3.0mm_W1.6mm_P2.50mm
C13: 1n; C_Disc_D3.0mm_W1.6mm_P2.50mm
C14: 1.5n; C_Disc_D3.0mm_W1.6mm_P2.50mm
C15: 100p; C_Disc_D3.0mm_W2.0mm_P2.50mm
C20, C22, C24, C31: 100n; C_Disc_D4.7mm_W2.5mm_P5.00mm
C21: 1n; C_Disc_D4.3mm_W1.9mm_P5.00mm
C25: 1u; C_Disc_D4.3mm_W1.9mm_P5.00mm
C26: 220u; CP_Radial_D6.3mm_P2.50mm
C28: 100n; C_Disc_D4.3mm_W1.9mm_P5.00mm
D1, D2, D3, D5: 1n4148; D_T-1_P5.08mm_Horizontal
D4: 1N4001; D_DO-15_P2.54mm_Vertical_AnodeUp
D6, D7: 1n4148; D_T-1_P2.54mm_Vertical_AnodeUp
H1, H2, H3, H4: GND; MountingHole_3.2mm_M3_Pad_Via
J1: Conn_Coaxial; BNC_Amphenol_B6252HB-NPP3G-50_Horizontal
J2: FromRX; PinSocket_1x08_P2.54mm_Vertical
J3: Barrel_Jack_Switch; BarrelJack_Wuerth_6941xx301002
J6: RX-HF; PinSocket_1x02_P2.54mm_Vertical
J7: TX-HF; PinSocket_1x02_P2.54mm_Vertical
J11: RXSupply; PinSocket_1x02_P2.54mm_Vertical
K1, K2, K3, K4: G6S-2; Relay_DPDT_Omron_G6S-2
L1, L5: 330n; L_Toroid_Vertical_L10.0mm_W5.0mm_P5.08mm_Diagonal_Rev
L2, L6, L10: 480n; L_Toroid_Vertical_L10.0mm_W5.0mm_P5.08mm_Diagonal
L3, L7: 750n; L_Toroid_Vertical_L10.0mm_W5.0mm_P5.08mm_Diagonal_Rev
L4, L8, L12: 1700n; L_Toroid_Vertical_L10.0mm_W5.0mm_P5.08mm_Diagonal
L9: 330n; L_Toroid_Vertical_L10.0mm_W5.0mm_P5.08mm_Diagonal
L11: 750n; L_Toroid_Vertical_L10.0mm_W5.0mm_P5.08mm_Diagonal
L13: 100u; L_Axial_L7.0mm_D3.3mm_P10.16mm_Horizontal_Fastron_MICC
L14: 22u; L_Radial_D8.7mm_P5.00mm_Fastron_07HCP
Q1, Q2, Q3, Q10: 2N3904; TO-92_Inline_Wide
Q4, Q6, Q7, Q8, Q9, Q11: BS170; TO-92_Inline_Wide
Q5: BD140-16; TO-126-3_Horizontal_TabDown
R1, R3, R5, R11: 10k; R_Axial_DIN0207_L6.3mm_D2.5mm_P2.54mm_Vertical
R2, R4, R6, R8: 100k; R_Axial_DIN0207_L6.3mm_D2.5mm_P2.54mm_Vertical
R7: 10k; R_Axial_DIN0204_L3.6mm_D1.6mm_P7.62mm_Horizontal
R9: 470; R_Axial_DIN0204_L3.6mm_D1.6mm_P5.08mm_Horizontal
R10: 1k; R_Axial_DIN0207_L6.3mm_D2.5mm_P2.54mm_Vertical
R12: 100; R_Axial_DIN0207_L6.3mm_D2.5mm_P7.62mm_Horizontal
R13: 100; R_Axial_DIN0204_L3.6mm_D1.6mm_P5.08mm_Horizontal
R14: 4.7k; R_Axial_DIN0204_L3.6mm_D1.6mm_P5.08mm_Horizontal
R15, R16: 10k; R_Axial_DIN0204_L3.6mm_D1.6mm_P2.54mm_Vertical
T1: 8+8@FT37-43; Transformer_1P_1S_Toroid_Vertical_D10.5mm_Amidon-T37
U1: 74HCT00; DIP-14_W7.62mm_LongPads

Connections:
10m: J2.5, R1.1
20m: J2.6, R3.1
40m: J2.7, R11.1
80m: J2.8, R5.1
+5V: C28.2, J2.1, R14.1, U1.14
+12V: C1.2, C10.2, C19.2, C22.2, C27.2, C29.2, D1.1, D2.1, D3.1, D5.1, K1.1, K2.1, K3.1, K4.1, L13.1, R7.2
GND: C2.2, C3.2, C4.2, C5.2, C6.2, C7.2, C8.2, C9.2, C11.2, C12.2, C13.2, C14.2, C15.2, C16.2, C17.2, C18.2, C22.1, C23.1, C24.1, C26.2, C28.1, C29.1, C30.2, C31.1, D4.2, D6.2, D7.1, H1.1, H2.1, H3.1, H4.1, J1.2, J2.2, J3.2, J6.2, J7.2, J11.2, K1.3, K1.10, K2.3, K2.10, K3.3, K3.10, K4.3, K4.10, Q1.1, Q2.1, Q3.1, Q6.3, Q7.3, Q8.3, Q9.3, Q10.1, Q11.3, R2.2, R4.2, R6.2, R8.2, R15.1, R16.1, U1.7
KEY5V: J2.4, R13.2
LPF: C20.1, C21.2, K1.5, K2.5, K3.5, K4.5
unnamed: C2.1, K1.9, L1.1
unnamed: C3.1, K2.9, L2.1
unnamed: C4.1, K3.9, L3.1
unnamed: C5.1, K4.9, L4.1
unnamed: C6.1, L1.2, L5.1
unnamed: C7.1, L2.2, L6.1
unnamed: C8.1, L3.2, L7.1
unnamed: C9.1, L4.2, L8.1
unnamed: C11.1, L5.2, L9.1
unnamed: C12.1, L6.2, L10.1
unnamed: C13.1, L7.2, L11.1
unnamed: C14.1, L8.2, L12.1
unnamed: C15.1, K1.4, L9.2
unnamed: C16.1, K2.4, L10.2
unnamed: C17.1, K3.4, L11.2
unnamed: C18.1, K4.4, L12.2
unnamed: C20.2, T1.2
unnamed: C21.1, Q4.1, R7.1
unnamed: C23.2, C25.1, Q5.2, T1.4
unnamed: C25.2, Q5.3, R9.1, R10.2
unnamed: C26.1, C31.2, L14.1, Q5.1, R9.2
unnamed: C30.1, Q4.2, R12.1, R16.2
unnamed: J1.1, K1.8, K2.8, K3.8, K4.8
unnamed: Q1.2, R1.2, R2.1
unnamed: Q2.2, R3.2, R4.1
unnamed: Q3.2, R5.2, R6.1
unnamed: Q8.1, R10.1
unnamed: Q8.2, R13.1, R15.2
unnamed: Q10.2, R8.1, R11.2
unnamed: Q6.1, Q7.1, Q9.1, Q11.1, T1.1, T1.3
unnamed: Q6.2, Q7.2, Q9.2, Q11.2, U1.3, U1.6
unnamed: U1.1, U1.2, U1.4, U1.5, U1.11
RL10M: C1.1, D1.2, K1.12, Q1.3
RL20M: C10.1, D2.2, K2.12, Q2.3
RL40M: C27.1, D5.2, K3.12, Q10.3
RL80M: C19.1, D3.2, K4.12, Q3.3
RX5V: R12.2, U1.8
RX-HF: D6.1, D7.2, J6.1, Q4.3
TX5V: J2.3, U1.9, U1.10, U1.13
TX-HF: J7.1, R14.2, U1.12
VCC: C24.2, D4.1, J3.1, J11.1, L13.2, L14.2

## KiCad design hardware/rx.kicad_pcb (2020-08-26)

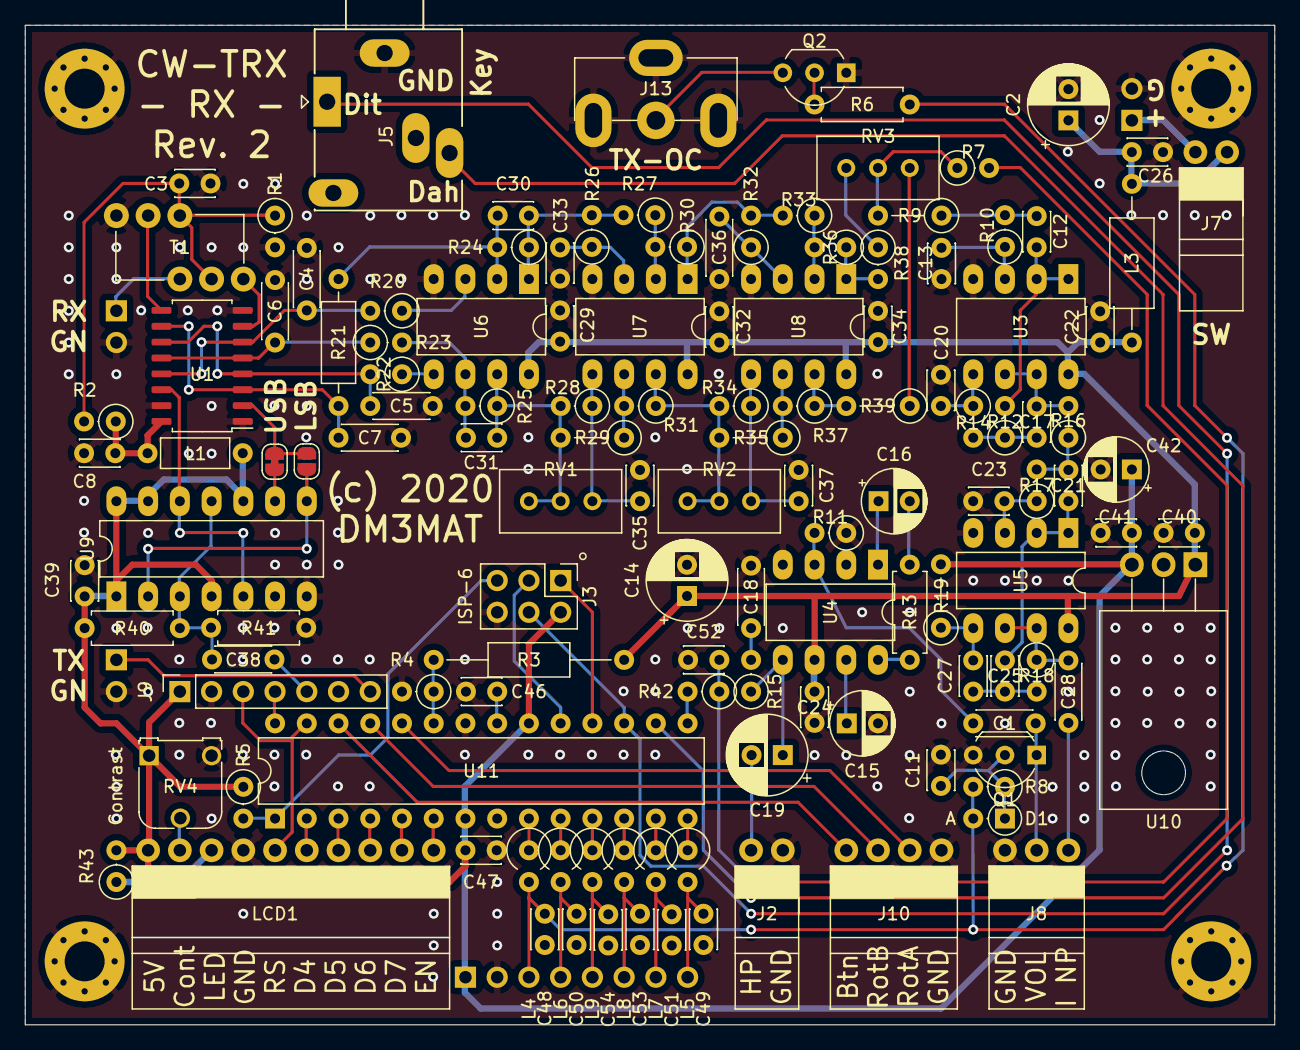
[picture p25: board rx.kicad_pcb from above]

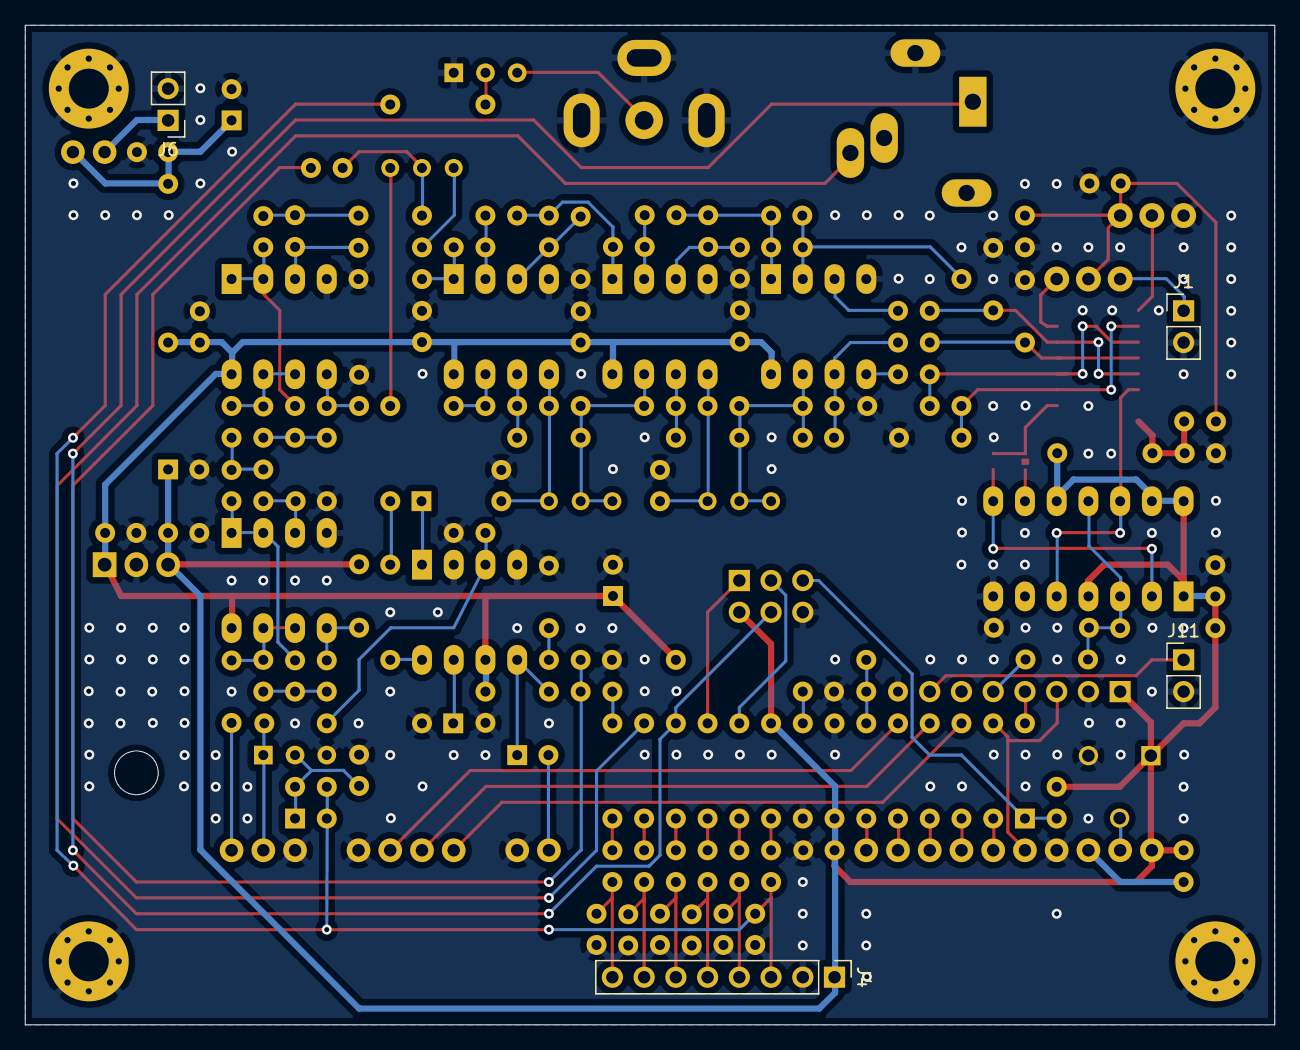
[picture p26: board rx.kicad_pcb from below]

Board: 2 copper layers, 100.0 x 80.0 mm, 137 parts (4 on the bottom side), 100 nets.

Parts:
C1, C28: 1u; C_Disc_D4.3mm_W1.9mm_P5.00mm
C2, C14, C19: 100u; CP_Radial_D6.3mm_P2.50mm
C3, C8, C11, C22, C24, C26, C29, C32, C34, C37, C39, C40, C41, C46, C47, C48, C49, C50, C51, C52, C53, C54: 100n; C_Disc_D3.0mm_W2.0mm_P2.50mm
C4, C5, C6, C7, C36: 470n; C_Disc_D4.3mm_W1.9mm_P5.00mm
C12, C17, C21, C33: 47n; C_Disc_D3.0mm_W2.0mm_P2.50mm
C13, C20, C23: 1n; C_Disc_D3.0mm_W2.0mm_P2.50mm
C15, C16, C42: 10u; CP_Radial_D5.0mm_P2.50mm
C18: 47n; C_Disc_D4.3mm_W1.9mm_P5.00mm
C25, C27: 3.3n; C_Disc_D3.0mm_W2.0mm_P2.50mm
C30, C31, C35: 10n; C_Disc_D3.0mm_W2.0mm_P2.50mm
C38: 100n; C_Disc_D4.3mm_W1.9mm_P5.00mm
D1: 1N4148; D_DO-35_SOD27_P2.54mm_Vertical_AnodeUp
H1, H2, H3, H4: GND; MountingHole_3.2mm_M3_Pad_Via
J1: RX-RF; PinHeader_1x02_P2.54mm_Vertical
J2: HP; Connector_BKL_1x02_P2.54mm_Horizontal
J3: AVR-ISP-6; PinHeader_2x03_P2.54mm_Vertical
J4: ToPA; PinHeader_1x08_P2.54mm_Vertical
J5: Key; Jack_3.5mm_Ledino_KB3SPRS_Horizontal
J6: Supply; PinHeader_1x02_P2.54mm_Vertical
J7: SW; Connector_BKL_1x02_P2.54mm_Horizontal
J8: 10K Log; Connector_BKL_1x03_P2.54mm_Horizontal
J9: Si5351; PinSocket_1x07_P2.54mm_Vertical
J10: ROT; Connector_BKL_1x04_P2.54mm_Horizontal
J11: TxOsc; PinHeader_1x02_P2.54mm_Vertical
J13: Conn_Coaxial; RCA_RND_205-00698_Horizontal
JP1: LSB; SolderJumper-2_P1.3mm_Open_RoundedPad1.0x1.5mm
JP2: USB; SolderJumper-2_P1.3mm_Bridged_RoundedPad1.0x1.5mm
L1: 100u; L_Axial_L5.3mm_D2.2mm_P7.62mm_Horizontal_Vishay_IM-1
L3: 100u; L_Axial_L7.0mm_D3.3mm_P12.70mm_Horizontal_Fastron_MICC
L4, L5, L6, L7, L8, L9: 100u; L_Axial_L7.0mm_D3.3mm_P2.54mm_Vertical_Fastron_MICC
LCD1: LCD; Connector_BKL_1x10_P2.54mm_Horizontal
Q1: BS170; TO-92_Inline_Wide
Q2: 2N3904; TO-92_Inline_Wide
R1, R2, R11, R18, R24, R25, R28: 10k; R_Axial_DIN0207_L6.3mm_D2.5mm_P2.54mm_Vertical
R3: 47k; R_Axial_DIN0207_L6.3mm_D2.5mm_P15.24mm_Horizontal
R4: 4.7k; R_Axial_DIN0207_L6.3mm_D2.5mm_P2.54mm_Vertical
R5: 47k; R_Axial_DIN0207_L6.3mm_D2.5mm_P2.54mm_Vertical
R6, R40, R41: 10k; R_Axial_DIN0207_L6.3mm_D2.5mm_P7.62mm_Horizontal
R7, R27, R30, R31, R33, R36, R37: 3.3k; R_Axial_DIN0207_L6.3mm_D2.5mm_P2.54mm_Vertical
R8: 120k; R_Axial_DIN0207_L6.3mm_D2.5mm_P2.54mm_Vertical
R9: 30k; R_Axial_DIN0207_L6.3mm_D2.5mm_P5.08mm_Vertical
R10: 30k; R_Axial_DIN0207_L6.3mm_D2.5mm_P2.54mm_Vertical
R12, R14: 33k; R_Axial_DIN0207_L6.3mm_D2.5mm_P2.54mm_Vertical
R13: 2.2k; R_Axial_DIN0207_L6.3mm_D2.5mm_P7.62mm_Horizontal
R15: 10; R_Axial_DIN0207_L6.3mm_D2.5mm_P2.54mm_Vertical
R16, R17: 36k; R_Axial_DIN0207_L6.3mm_D2.5mm_P2.54mm_Vertical
R19: 470k; R_Axial_DIN0207_L6.3mm_D2.5mm_P5.08mm_Vertical
R20, R22, R23: 100; R_Axial_DIN0207_L6.3mm_D2.5mm_P2.54mm_Vertical
R21: 100; R_Axial_DIN0207_L6.3mm_D2.5mm_P10.16mm_Horizontal
R26: 5.1k; R_Axial_DIN0207_L6.3mm_D2.5mm_P2.54mm_Vertical
R29, R35: 3.3k; R_Axial_DIN0207_L6.3mm_D2.5mm_P5.08mm_Vertical
R32: 4.3k; R_Axial_DIN0207_L6.3mm_D2.5mm_P2.54mm_Vertical
R34: 7.5k; R_Axial_DIN0207_L6.3mm_D2.5mm_P2.54mm_Vertical
R38, R42: 1k; R_Axial_DIN0207_L6.3mm_D2.5mm_P2.54mm_Vertical
R39: 1k; R_Axial_DIN0207_L6.3mm_D2.5mm_P5.08mm_Vertical
R43: 220; R_Axial_DIN0207_L6.3mm_D2.5mm_P2.54mm_Vertical
RV1, RV2: 50k; Potentiometer_Bourns_3296W_Vertical
RV3: 500; Potentiometer_Bourns_3296W_Vertical
RV4: 10k; Potentiometer_Runtron_RM-065_Vertical
T1: 3 x 8 @ FT37-43; Transformer_1P_2S_Toroid_Vertical_D10.5mm_Amidon-T37
U1: FST3253; SOIC-16_4.55x10.3mm_P1.27mm
U3, U5, U6, U7, U8: LM833; DIP-8_W7.62mm_LongPads
U4: LM386; DIP-8_W7.62mm_LongPads
U9: 74HC74; DIP-14_W7.62mm_LongPads
U10: L7805; TO-220-3_Horizontal_TabDown
U11: ATmega328-PU; DIP-28_W7.62mm

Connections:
10M: L9.1, U11.11
20M: L8.1, U11.12
40M: L7.1, U11.13
80M: L5.1, U11.14
+5VA: C8.1, L1.2, R2.1, U1.16
+5VD: C39.2, C41.1, C42.1, C47.1, J3.2, J4.1, J9.1, L1.1, LCD1.1, R5.1, R19.2, R40.2, R43.2, RV4.1, U9.1, U9.4, U9.10, U9.13, U9.14, U10.3, U11.7, U11.20
+12V: C14.1, C22.1, C24.1, C29.1, C32.1, C34.1, C40.1, L3.1, R3.1, U3.8, U4.6, U5.8, U6.8, U7.8, U8.8, U10.1
/Audio/HP: C19.2, J2.1
/Audio/NF: R7.1, R9.2, RV3.2
/Ctrl/10m: C54.2, J4.5, L9.2
/Ctrl/20m: C53.2, J4.6, L8.2
/Ctrl/40m: C51.2, J4.7, L7.2
/Ctrl/80m: C49.2, J4.8, L5.2
/Ctrl/SCL: J9.4, U11.28
/Ctrl/Side: C52.2, R7.2, R42.1
/Demod/I+: C4.1, R20.2, U1.6, U1.13
/Demod/I-: C7.1, R21.2, U1.3, U1.10
/Demod/Q+: C5.1, R22.2, U1.4, U1.11
/Demod/Q-: C6.1, R23.1, U1.5, U1.12
/Mixer/RF: J1.1, T1.2
/Mixer/VFO+I: U1.14, U9.5, U9.12
/Mixer/VFO+Q: JP1.2, JP2.1, U1.2
/VFO/CLK2: C38.2, J9.5
/VFO/VFO+Q: JP2.2, U9.9
/VFO/VFO-Q: JP1.1, U9.2, U9.8
Dah: J5.S, U11.16
Dit: J3.4, J5.T, U11.17
GND: C2.2, C3.2, C4.2, C5.2, C6.2, C7.2, C8.2, C11.2, C13.2, C14.2, C15.2, C18.2, C20.2, C22.2, C23.2, C24.2, C26.2, C29.2, C32.2, C33.2, C34.2, C35.1, C36.2, C37.1, C39.1, C40.2, C41.2, C42.2, C46.1, C47.2, C48.1, C49.1, C50.1, C51.1, C52.1, C53.1, C54.1, H1.1, H2.1, H3.1, H4.1, J1.2, J2.2, J3.6, J4.2, J5.G, J6.2, J8.1, J9.2, J10.4, J11.2, J13.2, LCD1.4, Q1.3, Q2.1, R1.2, R4.2, R11.1, R41.1, RV4.3, T1.1, U1.1, U1.8, U1.15, U3.4, U4.2, U4.4, U5.4, U6.4, U7.4, U8.4, U9.7, U10.2, U11.8, U11.22
KEY: L6.1, U11.10
Key: C50.2, J4.4, L6.2
LCD_CR: LCD1.2, RV4.2
LCD_D4: LCD1.6, U11.2
LCD_D5: LCD1.7, U11.3
LCD_D6: LCD1.8, U11.4
LCD_D7: LCD1.9, U11.5
LCD_EN: LCD1.10, U11.6
LCD_RS: J9.3, LCD1.5, U11.27
MISO: J3.1, U11.18
unnamed: C1.1, R11.2, U4.3
unnamed: C3.1, R1.1, R2.2, T1.4, T1.5
unnamed: C11.1, D1.1, Q1.2, R8.1
unnamed: C12.1, R9.1, R10.2
unnamed: C12.2, R12.2, U3.1, U3.2
unnamed: C13.1, R10.1, U3.3
unnamed: C15.1, U4.7
unnamed: C16.1, U4.1
unnamed: C16.2, R13.2
unnamed: C17.1, R12.1, R14.2
unnamed: C17.2, R16.2, U3.6, U3.7
unnamed: C18.1, R15.2
unnamed: C19.1, R15.1, U4.5
unnamed: C20.1, R14.1, U3.5
unnamed: C21.1, R16.1, R17.2
unnamed: C21.2, C25.1, U5.1, U5.2
unnamed: C23.1, R17.1, U5.3
unnamed: C25.2, C27.1, R18.2
unnamed: C27.2, R19.1, U5.5
unnamed: C28.2, R18.1, U5.6, U5.7
unnamed: C30.1, R24.1, R26.2, R27.2, U6.1
unnamed: C30.2, R21.1, R24.2, U6.2
unnamed: C31.1, R25.1, R28.2, R29.2, RV1.2, RV1.3, U6.7
unnamed: C31.2, R23.2, R25.2, U6.6
unnamed: C33.1, R26.1, U7.3
unnamed: C35.2, R28.1, RV1.1, U7.5
unnamed: C36.1, R32.1, U8.3
unnamed: C37.2, R34.1, RV2.1, U8.5
unnamed: C38.1, R40.1, R41.2, U9.3, U9.11
unnamed: C46.2, U11.21
unnamed: J6.1, J7.1
unnamed: J13.1, Q2.3
unnamed: LCD1.3, R43.1
unnamed: Q2.2, R6.1
unnamed: R13.1, U4.8
unnamed: R20.1, U6.3
unnamed: R22.1, U6.5
unnamed: R27.1, R30.2, U7.2
unnamed: R29.1, R31.2, U7.6
unnamed: R30.1, R32.2, R33.2, U7.1
unnamed: R31.1, R34.2, R35.2, RV2.2, RV2.3, U7.7
unnamed: R33.1, R36.2, U8.2
unnamed: R35.1, R37.2, U8.6
unnamed: R36.1, R38.2, U8.1
unnamed: R37.1, R39.2, U8.7
unnamed: R38.1, RV3.1
unnamed: R39.1, RV3.3
unnamed: T1.3, U1.9
unnamed: T1.6, U1.7
POT-A: C28.1, J8.3
POT-B: C1.2, J8.2, Q1.1
ROT-A: J10.3, U11.24
ROT-B: J10.2, U11.25
ROT-M: J10.1, U11.26
RST: J3.5, R5.2, U11.1
SCK: J3.3, U11.19
SIDE: R42.2, U11.15
TX: L4.1, U11.9
TX5V: C48.2, D1.2, J4.3, L4.2, R6.2, R8.2
TX-OSC: J9.7, J11.1
VCC: C2.1, C26.1, J7.2, L3.2
Vbat: R3.2, R4.1, U11.23

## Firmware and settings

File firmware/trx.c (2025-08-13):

#include "trx.h"
#include "band.h"
#include "keyer.h"
#include "tone.h"
#include "rot.h"
#include "si5351.h"
#include "lcd.h"
#include "display.h"
#include "meter.h"
#include "menu.h"

#include <avr/io.h>
#include <avr/interrupt.h>
#include <util/delay.h>
#include <avr/eeprom.h>
#include <avr/pgmspace.h>
#include <util/atomic.h>
#include <string.h>

// AVR comp for QtCreator
#ifndef ISR
#define ISR(x) void x()
#endif
#ifndef EEMEM
#define EEMEM
#endif

#define TRX_DEFAULT_QUICK_SET      TRX_QS_NONE
#define TRX_DEFAULT_STEPSIZE       TRX_STEP_50
#define TRX_DEFAULT_SIDEBAND       TRX_USB
#define TRX_DEFAULT_RIT            0
#define TRX_DEFUALT_TXENABLED      1
#define TRX_DEFAULT_CW_TONE        700
#define TRX_DEFAULT_CW_LEVEL       255
#define TRX_DEFAULT_CW_SPEED       10
#define TRX_DEFAULT_KEYER_TYPE     KEYER_TYPE_STRAIGHT
#define TRX_DEFAULT_IAMBIC_MODE    KEYER_IAMBIC_B
#define TRX_DEFAULT_PADDLE_REVERSE 0
#define TRX_DEFAULT_METER_TYPE     METER_VOLTAGE
#define TRX_DEFAULT_TX_HOLD        50
#define TRX_DEFAULT_PLL_CORRECTION 0
#define TRX_DEFAULT_ROT_TYPE       ROT_TYPE_A
#define TRX_UPDATE_PERIOD          500
#define TRX_SAVE_PERIOD            10000UL

#define TRX_80_MIN   3500000UL
#define TRX_80_MAX   3800000UL
#define TRX_60_MIN   5351500UL
#define TRX_60_MAX   5366500UL
#define TRX_40_MIN   7000000UL
#define TRX_40_MAX   7200000UL
#define TRX_30_MIN  10100000UL
#define TRX_30_MAX  10150000UL
#define TRX_20_MIN  14000000UL
#define TRX_20_MAX  14350000UL
#define TRX_17_MIN  18068000UL
#define TRX_17_MAX  18168000UL
#define TRX_15_MIN  21000000UL
#define TRX_15_MAX  21450000UL
#define TRX_12_MIN  24890000UL
#define TRX_12_MAX  24990000UL
#define TRX_10_MIN  28000000UL
#define TRX_10_MAX  29690000UL

#define MINMAX(x, a, b) ( (x<a) ? a : ((x>b) ? b : x))

/** Contains the VFO settings. That is band, current dial frequency for each band and the selected
 * sideband. */
typedef struct {
  Band      band;
  uint32_t  band_freq[9];
} VFOSettings;

/** Holds the entire settings for the TRX in memory. */
typedef struct {
  /** Holds the current VFO mode, that is A, B and A/B split. */
  VFOMode         vfo_mode;
  /** Settings for the VFO A. */
  VFOSettings     vfo_a;
  /** Settings for the VFO B. */
  VFOSettings     vfo_b;
  /** Quick-set option. */
  TRXQuickSet     quick_set;
  /** Tuing stepsize. */
  TRXStepSize     step;
  /** Sideband **/
  TRXSideband     sideband;
  /** RIT */
  int8_t          rit;
  /** If true, TX is enabled. */
  uint8_t         tx_enabled;
  /** The frequency of the CW sidetone. */
  uint16_t        cw_tone;
  /** CW tone level. */
  uint8_t         cw_level;
  /** Speed in WPM of the CW keyer. */
  uint8_t         cw_speed;
  /** CW keyer settings. */
  KeyerType       keyer_type;
  KeyerIambicMode iambic_mode;
  uint8_t         paddle_reverse;
  MeterType       meter_type;
  /** TX hold delay in ms. */
  uint16_t        tx_hold;
  /** PLL reference frequeny correction in 0.1ppm. */
  int32_t         pll_correction;
  /** Type of rotary encoder. */
  uint8_t         rot_type;
  uint8_t         cwtext[TRX_CWTEXT_MAXLEN];
  uint8_t         greet[8];
} TRXSettings;


TRXSettings _ee_trx EEMEM = {
  VFO_MODE_A,
  { BAND_80,
    {TRX_80_MIN, TRX_60_MIN, TRX_40_MIN, TRX_30_MIN, TRX_20_MIN, TRX_17_MIN, TRX_15_MIN, TRX_12_MIN, TRX_10_MIN} },
  { BAND_80,
    {TRX_80_MIN, TRX_60_MIN, TRX_40_MIN, TRX_30_MIN, TRX_20_MIN, TRX_17_MIN, TRX_15_MIN, TRX_12_MIN, TRX_10_MIN} },
  TRX_DEFAULT_QUICK_SET,
  TRX_DEFAULT_STEPSIZE,
  TRX_DEFAULT_SIDEBAND,
  TRX_DEFAULT_RIT,
  TRX_DEFUALT_TXENABLED,
  TRX_DEFAULT_CW_TONE,
  TRX_DEFAULT_CW_LEVEL,
  TRX_DEFAULT_CW_SPEED,
  TRX_DEFAULT_KEYER_TYPE,
  TRX_DEFAULT_IAMBIC_MODE,
  TRX_DEFAULT_PADDLE_REVERSE,
  TRX_DEFAULT_METER_TYPE,
  TRX_DEFAULT_TX_HOLD,
  TRX_DEFAULT_PLL_CORRECTION,
  TRX_DEFAULT_ROT_TYPE,
  {03, 17, 00, 03, 17, 00, 03, 17, 00, 17, 18, 16, 00, 04, 05, 00},
  {' ','D','M','3','M','A','T',' '}
};

const TRXSettings _prog_trx PROGMEM = {
  VFO_MODE_A,
  { BAND_80,
    {TRX_80_MIN, TRX_60_MIN, TRX_40_MIN, TRX_30_MIN, TRX_20_MIN, TRX_17_MIN, TRX_15_MIN, TRX_12_MIN, TRX_10_MIN} },
  { BAND_80,
    {TRX_80_MIN, TRX_60_MIN, TRX_40_MIN, TRX_30_MIN, TRX_20_MIN, TRX_17_MIN, TRX_15_MIN, TRX_12_MIN, TRX_10_MIN} },
  TRX_DEFAULT_STEPSIZE,
  TRX_DEFAULT_QUICK_SET,
  TRX_DEFAULT_SIDEBAND,
  TRX_DEFAULT_RIT,
  TRX_DEFUALT_TXENABLED,
  TRX_DEFAULT_CW_TONE,
  TRX_DEFAULT_CW_LEVEL,
  TRX_DEFAULT_CW_SPEED,
  TRX_DEFAULT_KEYER_TYPE,
  TRX_DEFAULT_IAMBIC_MODE,
  TRX_DEFAULT_PADDLE_REVERSE,
  TRX_DEFAULT_METER_TYPE,
  TRX_DEFAULT_TX_HOLD,
  TRX_DEFAULT_PLL_CORRECTION,
  TRX_DEFAULT_ROT_TYPE,
  {},
  {' ','D','M','3','M','A','T',' '}
};


TRXSettings _trx;

volatile TRXState _state;
TRXState _display_state;

uint16_t _tx_hold_count;
uint16_t _trx_tick_count;
uint16_t _trx_save_count;
volatile uint8_t _trx_update_vfo;
volatile uint8_t _trx_tuned;
volatile uint8_t _trx_save_freq;
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

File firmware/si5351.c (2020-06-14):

/*
 * si5351.c - Si5351 library for avr-gcc
 *
 * Copyright (C) 2014 Jason Milldrum <milldrum@gmail.com>
 *
 * Some tuning algorithms derived from clk-si5351.c in the Linux kernel.
 * Sebastian Hesselbarth <sebastian.hesselbarth@gmail.com>
 * Rabeeh Khoury <rabeeh@solid-run.com>
 *
 * rational_best_approximation() derived from lib/rational.c in
 * the Linux kernel.
 * Copyright (C) 2009 emlix GmbH, Oskar Schirmer <oskar@scara.com>
 *
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
 * You should have received a copy of the GNU General Public License
 * along with this program.  If not, see <http://www.gnu.org/licenses/>.
 */

#include <stdio.h>
#include <stdint.h>
#include <stdlib.h>
#include <string.h>
#include <math.h>
#include <util/twi.h>
#include <avr/eeprom.h>

#include "si5351.h"
#include "i2c.h"

int32_t ref_correction = 0;
uint32_t plla_freq = 0;
uint32_t pllb_freq = 0;

struct Si5351Status dev_status;
struct Si5351IntStatus dev_int_status;

void si5351_reset();
void si5351_pll_reset(enum si5351_pll target_pll);

/******************************/
/* Suggested public functions */
/******************************/

/*
 * si5351_init(void)
 *
 * Call this to initialize I2C communications and get the
 * Si5351 ready for use.
 */
uint8_t si5351_init(void)
{
	i2c_init();

	/* Set crystal load capacitance */
	if (si5351_write(SI5351_CRYSTAL_LOAD, SI5351_CRYSTAL_LOAD_8PF))
    return 1;

  //si5351_reset();

  return 0;
}

/*
 * Resets the PLLs, outputs etc.
 */
void si5351_reset() {
  // Initialize the CLK outputs according to flowchart in datasheet
	// First, turn them off
	si5351_write(16, 0x80);
	si5351_write(17, 0x80);
	si5351_write(18, 0x80);
	si5351_write(19, 0x80);
	si5351_write(20, 0x80);
	si5351_write(21, 0x80);
	si5351_write(22, 0x80);
	si5351_write(23, 0x80);

	// Turn the clocks back on...
	si5351_write(16, 0x0c);
	si5351_write(17, 0x0c);
	si5351_write(18, 0x0c);
	si5351_write(19, 0x0c);
	si5351_write(20, 0x0c);
	si5351_write(21, 0x0c);
	si5351_write(22, 0x0c);
	si5351_write(23, 0x0c);

	// Set PLLA to 800 MHz for automatic tuning
	si5351_set_pll(SI5351_PLL_FIXED, SI5351_PLLA);
	si5351_set_pll(SI5351_PLL_FIXED, SI5351_PLLB);

	si5351_set_ms_source(SI5351_CLK0, SI5351_PLLA);
	si5351_set_ms_source(SI5351_CLK1, SI5351_PLLB);
	si5351_set_ms_source(SI5351_CLK2, SI5351_PLLB);

  si5351_clock_enable(SI5351_CLK0, 0);
  si5351_clock_enable(SI5351_CLK1, 0);
  si5351_clock_enable(SI5351_CLK2, 0);

  // Then reset the PLLs
	si5351_pll_reset(SI5351_PLLA);
	si5351_pll_reset(SI5351_PLLB);
}

void si5351_pll_reset(enum si5351_pll target_pll)
{
  switch (target_pll) {
    case SI5351_PLLA: si5351_write(SI5351_PLL_RESET, SI5351_PLL_RESET_A); break;
    case SI5351_PLLB: si5351_write(SI5351_PLL_RESET, SI5351_PLL_RESET_B); break;
  }
}


/*
 * si5351_set_freq(uint32_t freq, uint32_t pll_freq, enum si5351_clock output)
 *
 * Sets the clock frequency of the specified CLK output
 *
 * freq - Output frequency in Hz
 * pll_freq - Frequency of the PLL driving the Multisynth
 *   Use a 0 to have the function choose a PLL frequency
 * clk - Clock output
 *   (use the si5351_clock enum)
 */
void si5351_set_freq(uint32_t freq, uint32_t pll_freq, enum si5351_clock clk)
{
	struct Si5351RegSet ms_reg;//, pll_reg;
	enum si5351_pll target_pll;

	/* Calculate the synth parameters
	 * If pll_freq is 0, let the algorithm pick a PLL frequency */
	if (0 == pll_freq) {
		pll_freq = multisynth_calc(freq, &ms_reg);
	} else {
		multisynth_recalc(freq, pll_freq, &ms_reg);
	}

	/* Determine which PLL to use
	 * CLK0 gets PLLA, CLK1 gets PLLB
	 * CLK2 gets PLLB if necessary
	 * Only good for Si5351A3 variant at the moment */
	if (clk == SI5351_CLK0) {
		target_pll = SI5351_PLLA;
		plla_freq = pll_freq;
	} else if (clk == SI5351_CLK1) {
		target_pll = SI5351_PLLB;
		pllb_freq = pll_freq;
	} else {
		/* need to account for CLK2 set before CLK1 */
		if (pllb_freq == 0) {
			target_pll = SI5351_PLLB;
			pllb_freq = pll_freq;
		} else {
			target_pll = SI5351_PLLB;
			pll_freq = pllb_freq;
			multisynth_recalc(freq, pll_freq, &ms_reg);
		}
	}

  si5351_set_pll(pll_freq, target_pll);

	/* Now the multisynth parameters */
  uint8_t params[SI5351_PARAMETERS_LENGTH];
	uint8_t i = 0;
	uint8_t temp;

	/* Registers 42-43 */
	temp = (uint8_t)((ms_reg.p3 >> 8) & 0xFF);
	params[i++] = temp;

	temp = (uint8_t)(ms_reg.p3  & 0xFF);
	params[i++] = temp;

	/* Register 44
	 * TODO: add code for output divider */
	temp = (uint8_t)((ms_reg.p1 >> 16) & 0x03);
  //uint8_t reg_val; si5351_read((SI5351_CLK0_PARAMETERS + 2) + (clk * 8), &reg_val);
  //reg_val &= ~(0x03);
  //temp = reg_val | ((uint8_t)((ms_reg.p1 >> 16) & 0x03));
	params[i++] = temp;

	/* Registers 45-46 */
	temp = (uint8_t)((ms_reg.p1 >> 8) & 0xFF);
	params[i++] = temp;

	temp = (uint8_t)(ms_reg.p1  & 0xFF);
	params[i++] = temp;

	/* Register 47 */
	temp = (uint8_t)((ms_reg.p3 >> 12) & 0xF0);
	temp += (uint8_t)((ms_reg.p2 >> 16) & 0x0F);
	params[i++] = temp;

	/* Registers 48-49 */
	temp = (uint8_t)((ms_reg.p2 >> 8) & 0xFF);
	params[i++] = temp;

	temp = (uint8_t)(ms_reg.p2  & 0xFF);
	params[i++] = temp;

	/* Write the parameters */
	switch(clk)
	{
	case SI5351_CLK0:
		si5351_write_bulk(SI5351_CLK0_PARAMETERS, i, params);
		si5351_set_ms_source(clk, target_pll);
		break;
	case SI5351_CLK1:
		si5351_write_bulk(SI5351_CLK1_PARAMETERS, i, params);
		si5351_set_ms_source(clk, target_pll);
		break;
	case SI5351_CLK2:
		si5351_write_bulk(SI5351_CLK2_PARAMETERS, i, params);
		si5351_set_ms_source(clk, target_pll);
		break;
	case SI5351_CLK3:
		si5351_write_bulk(SI5351_CLK3_PARAMETERS, i, params);
		si5351_set_ms_source(clk, target_pll);
		break;
	case SI5351_CLK4:
		si5351_write_bulk(SI5351_CLK4_PARAMETERS, i, params);
		si5351_set_ms_source(clk, target_pll);
		break;
	case SI5351_CLK5:
		si5351_write_bulk(SI5351_CLK5_PARAMETERS, i, params);
		si5351_set_ms_source(clk, target_pll);
		break;
	case SI5351_CLK6:
		si5351_write_bulk(SI5351_CLK6_PARAMETERS, i, params);
		si5351_set_ms_source(clk, target_pll);
		break;
	case SI5351_CLK7:
		si5351_write_bulk(SI5351_CLK7_PARAMETERS, i, params);
		si5351_set_ms_source(clk, target_pll);
		break;
	}
}
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

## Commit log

2019-07-22 Fixed minors.
    [ctrl.kicad_pcb, ctrl.sch, pa.sch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]
2019-11-17 Added libs and fixed footprints.
    [ctrl.sch, pa.kicad_pcb, pa.sch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]
2019-11-17 Updated library.
    [pa.kicad_pcb]
2020-02-01 Minor fixes
    [pa.kicad_pcb]
2020-04-28 Fixed greet text editor.
    [trx.c]
2020-05-15 Added revision 2 hardware.
    [ctrl.kicad_pcb, ctrl.sch, pa.kicad_pcb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]
2020-05-15 Added missing sub-circuits.
    [rx.kicad_pcb, rx_audio.sch, rx_ctrl.sch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]
2020-05-17 backup rev. 2
    [pa-B_Cu.gbr, pa-B_Mask.gbr, pa-Edge_Cuts.gbr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]
2020-06-11 Fixed firmware.
    [pa_bom.ods, rx_bom.ods]
2020-06-13 Minor fixes to LP filter.
    [pa.sch, pa_bom.ods, rx.kicad_pcb]
2020-06-13 Added mechanical BOM
    [mech_bom.ods]
2020-06-13 Added Reicheld CSV.
    [complete_bom.ods, mech_bom.ods, reichelt_bom.csv]
2020-06-14 Implemented factory reset & EncType
    [trx.c]
2020-06-17 Fixed minor issues.
    [complete_bom.ods, mech_bom.ods]
2020-06-23 Added quick-set.
    [mech.kicad_pcb, mech.sch, pa.kicad_pcb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]
2020-06-23 Fixed RX/TX sw. on PA.
    [pa.kicad_pcb, pa.sch]
2020-06-24 Fixed docs.
    [complete_bom.ods, pa.kicad_pcb, pa.sch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]
2020-06-24 Fixed PA.
    [pa-B_Cu.gbr, pa-B_Mask.gbr, pa-Edge_Cuts.gbr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]
2020-06-27 Fixed menu.
    [rx.kicad_pcb]
2020-07-23 Started german manual.
    [mech.kicad_pcb]
2020-08-26 Added interactive bom
    [pa.kicad_pcb, rx.kicad_pcb]
2020-12-27 Fixed manual.
    [reichelt_bom.csv]
2021-01-26 Fixed BOM
2021-03-09 Added drill-plan for back side.
    [mech_back.kicad_pcb, mech_back.sch]
2021-12-27 Fixed auto-text and automatic key detection.
    [trx.c]

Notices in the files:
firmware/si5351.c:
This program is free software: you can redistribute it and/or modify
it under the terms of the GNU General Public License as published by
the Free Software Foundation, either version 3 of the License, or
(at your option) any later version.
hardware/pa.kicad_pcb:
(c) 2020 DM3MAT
